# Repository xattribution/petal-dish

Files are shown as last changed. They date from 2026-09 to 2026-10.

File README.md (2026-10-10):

# PETAL — printable parabolic dish generator

PETAL designs a segmented parabolic dish that you can print on an ordinary 3D printer. Enter the dish size and your printer's build volume. It splits the dish into petals that fit your bed and shows the assembly. Then it exports a ready-to-print kit: STLs, packed print plates, an illustrated assembly PDF and a hardware list.

Everything runs in your browser, with no account, no upload and no server-side processing. Geometry builds in a background worker, so the page stays responsive while large dishes generate.

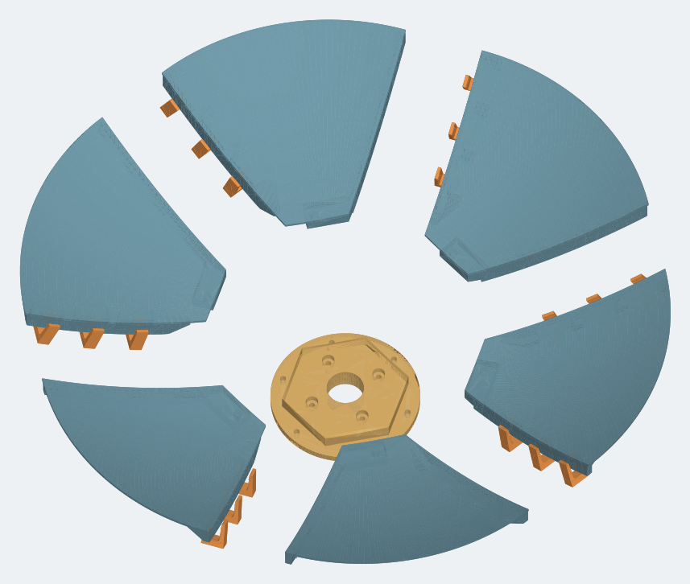
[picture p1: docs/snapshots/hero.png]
A 400 mm dish, exploded and seen from the front: six petals with snap clips around the hub


## Get started

Pick one of four ways to run it.

### 1. Open the offline app (no install)

Download **[`dist/petal-5.3-offline.html`](dist/petal-5.3-offline.html)** and open it in a browser. It is a single file with everything built in, and it works without a network connection.

### 2. Self-host on Linux (one command)

```bash
curl -fL https://raw.githubusercontent.com/xattribution/petal-dish/main/scripts/install-linux.sh -o /tmp/petal-install.sh \
  && sudo bash /tmp/petal-install.sh --port 56302 --ref main
```

Then open `http://SERVER-IP:56302`. The installer sets up a small verified web server and a boot-persistent `petal` service.

| Option | Meaning |
|---|---|
| `--port N` | Listen on port N (default 56302) |
| `--ref REF` | Install a branch, tag or full commit SHA (default `main`) |
| `--localhost` | Bind to 127.0.0.1 only, e.g. behind your own reverse proxy |

To update, re-run the same command. For status, logs and rollback, see [docs/SELF-HOSTING.md](docs/SELF-HOSTING.md).

### 3. Docker

```bash
git clone https://github.com/xattribution/petal-dish.git && cd petal-dish
docker compose up -d --build
```

Then open `http://SERVER-IP:56302`. Compose builds an nginx image from the committed `dist/` and publishes port 56302. This serves the static build only. It does not run the verified Linux installer.

To update, run this one line from anywhere. It pulls the latest build, rebuilds the image, restarts the container and removes the old image. Change `~/petal-dish` if you cloned somewhere else.

```bash
git -C ~/petal-dish pull --ff-only && docker compose -f ~/petal-dish/compose.yaml up -d --build && docker image prune -f
```

If Docker needs `sudo` on your server, use this form instead:

```bash
sudo git -C ~/petal-dish pull --ff-only && sudo docker compose -f ~/petal-dish/compose.yaml up -d --build && sudo docker image prune -f
```

Each build loads its script and styles under new URLs, so a normal reload shows the update.

### 4. Run from source

```bash
git clone https://github.com/xattribution/petal-dish.git && cd petal-dish
npm ci
npm run build                      # rebuilds dist/app.bundle.js and the offline file
python3 -m http.server 56317 -d dist  # then open http://localhost:56317
```

## Using it

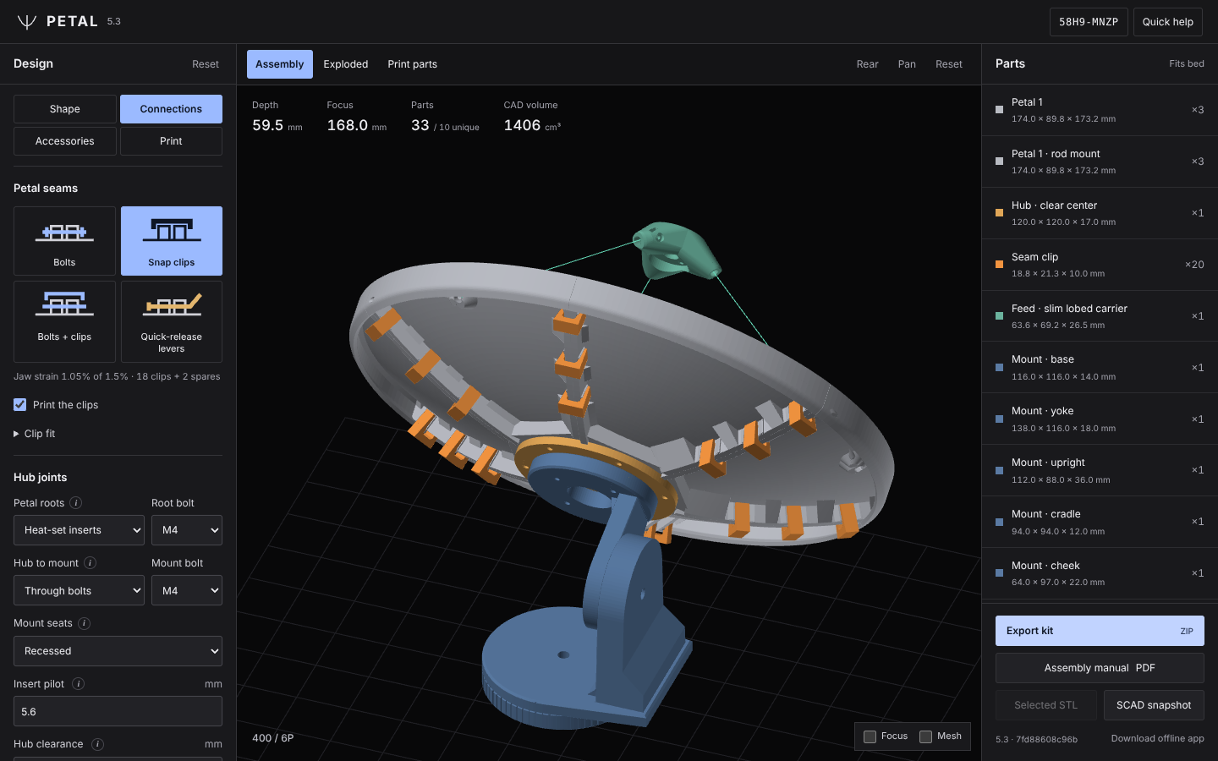
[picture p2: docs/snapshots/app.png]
PETAL in the browser: a 400 mm dish with seam clips, a prime-focus feed support and the aiming mount


The editor has four tabs.

1. **Shape:** dish diameter, focal ratio (f/D), shell thickness, an optional frequency, and the hub front.
2. **Connections:** pick the seam method from the four cards, the seam bolt size and the hub joints. **Edit individual joints** changes one seam family or one joint; **Show in model** highlights it.
3. **Accessories:** a feed support (prime focus, Cassegrain or Gregorian collector) and the aiming mount. Each has a checkbox to leave its parts off the print plates when you already have them.
4. **Print:** your printer and plate packing. PETAL chooses how many petals and rings are needed, aiming for either the largest petals or the fewest print plates.

Then **Export kit (ZIP)**: every STL in its print orientation, packed plates, `ASSEMBLY.pdf`, `HARDWARE.csv` and the fit-test parts. **Print the two seam test strips first**, then one full petal, before printing the whole dish.

The default 400 mm dish is six petals plus one hub: two unique parts, each with a flat flange down on the bed. Packed, they fit on two 220 × 220 mm beds: the petals lean the same way and nest. Drag a part to the empty slot to give it a bed of its own.

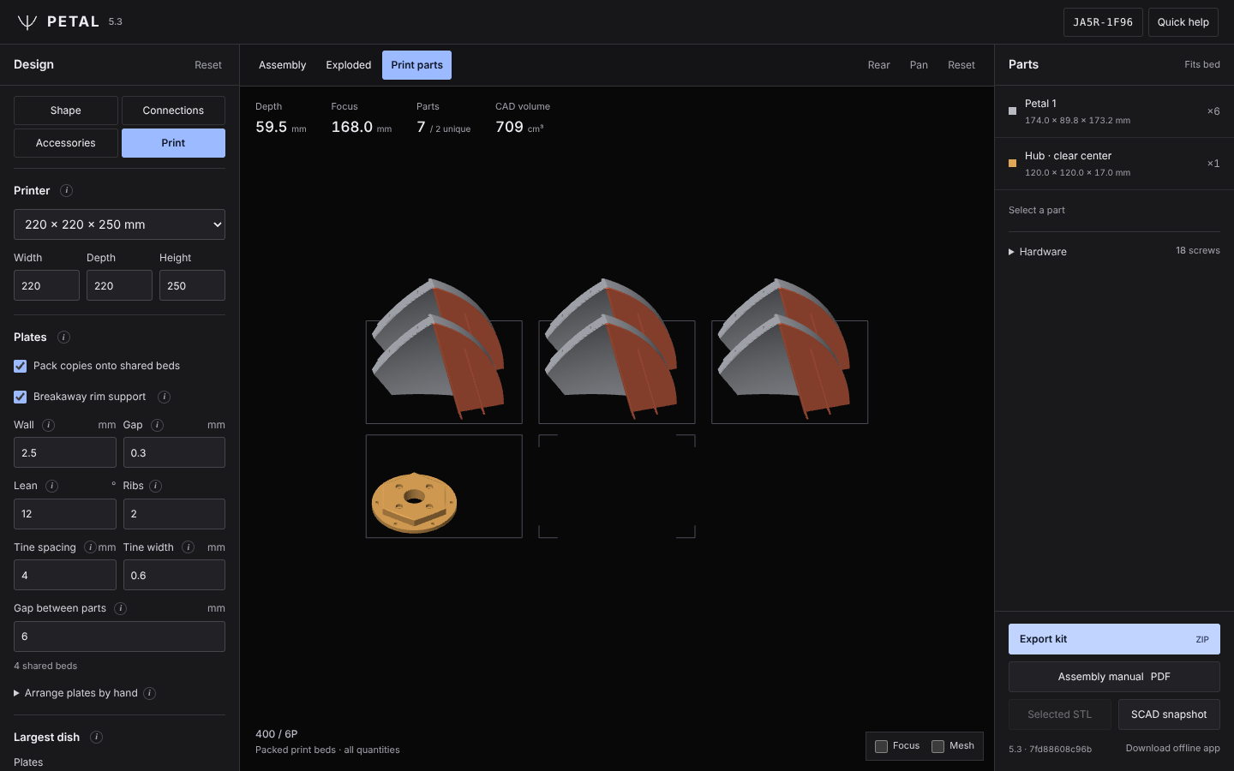
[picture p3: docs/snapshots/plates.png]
Print parts view: five petals nested on the first 220 mm bed, the sixth petal and the hub on the second, and an empty slot for a new bed


### Sharing a design

The button at the top right shows the design's **configuration ID**, such as `PX64-0211`. It covers every setting, joint choice and hand-placed plate, and it changes with any edit, so two people who see the same ID are looking at the same design.

Click it to:

- **Copy code** (for example `P1.wyFMlJFgv-EMhdpaAA`) or **Copy link**. Anyone who loads the code or opens the link gets the exact design. The address bar always holds the current link, so a reload keeps your design.
- **Load** a code, a link, a saved file, or the `parameters.json` from a kit you already exported.
- **Save** named designs in this browser, or **Save file** to keep one with a kit or move it to another device.

Every assembly PDF shows the ID on each page and the full code on the build record page, and the kit's `parameters.json` holds both. A code from another PETAL version still loads, with a note that its parts may differ.

## Options at a glance

| Choice | Options |
|---|---|
| **Seam fastening** | **M3 or M4 bolts** on flat seats (default M3) · **snap clips**, no hardware · **both** (each station takes a bolt or a clip) · **seam levers**, a screwless quick-release cam clamp ([details](docs/SEAM-LEVER.md)) |
| **Petal roots to hub** | Blind heat-set inserts, keeping the reflecting face closed (default) · through bolts, in recessed seats (default) or plain holes. M3, M4 (default) or M5 |
| **Hub to mount** | Through bolts, in recessed seats (default) or plain holes · blind inserts. Four M3, M4 (default) or M5 on a 60 mm bolt circle around a clear Ø30 mm center |
| **Hub clearance** | 0 mm (default) to 0.6 mm of extra gap at the hub's edges and root holes, so the petals line up on their seams before the root bolts clamp them to the hub. The mount holes stay put |
| **Hub front** | Flat (default): level with the petals at the hub's corners and chamfered down to them along each edge, so it prints cleanly · curved, following the dish |
| **Underside** | Smooth curved shell (default) · small flat facets |
| **Stiffening** | A band behind the rim of the outer petals, square to the dish: a frame with a 45° foot toward the hub (default), an L, a U or none, with a 6–30 mm wall and a 0–3 mm lip above the reflecting face (1 mm default). Every print layer ends in a hook instead of a free edge, and the assembled bands form one frame around the dish · optional underside ribs: a diamond grid, a center ring, or both ([details](docs/PRINTING-LARGE-PETALS.md#rim-band-and-underside-ribs)) |
| **Rim support** | A solid breakaway wall printed in front of the rim of each outer petal, joined to the rim's front edge by small tines that snap off (default on: 2.5 mm wall with its inner edge 12° from vertical and two ribs square to it, 0.3 mm gap, 0.6 mm tines at most 4 mm apart). It holds the tall rim edge still in the side print and is not part of the dish. It spreads nested petals on a plate; a larger lean uses less material ([details](docs/PRINTING-LARGE-PETALS.md#breakaway-rim-support)) |
| **Automatic sizing** | Largest petals: the fewest pieces and seams (default) · fewest print plates: may use more, smaller petals when they pack onto fewer beds |
| **Large dishes** | Staggered rings (default) · aligned rings |
| **Printer** | Presets for the Prusa CORE One L (with or without the INDX tool changer), Bambu Lab H2D and H2C, common volumes, or any custom volume. The last valid volume is remembered in the browser |
| **Print plates** | Copies share beds and keep 6 mm apart at every height (adjustable, for wider brims), so side-printed petals that lean the same way nest like spoons. In **Print parts**, drag a part onto another bed (or the empty slot after the last one): it lands in the nearest spot that fits, turning if it has to. Exact positions can also be typed in. **Largest dish** finds the biggest dish whose kit fits a number of plates on your printer, with any petal and ring count |
| **Feed support** | None · prime focus · Cassegrain secondary (experimental) · Gregorian collector: a bowl over the focus that folds the signal down to your insert, re-solved for every dish shape ([details](docs/FEED-OPTICS.md#gregorian-collector)). All on aluminum rods with generated cut lengths: four with 8, 12 or 16 petals, three with 6, or a fixed count |
| **Aiming mount** | None · printed manual alt-az mount, split into parts joined with heat-set inserts. Optional elevation arc lock. The elevation clamp goes on the right, the left (a slip then tightens it) or both sides, a U with two clamps. Base: printed with an azimuth scale, tripod leg sockets for your own legs, or none (bolt the turntable to a stand). Bolt sizes: clamps M6, M8 (default) or M10; joint screws M3–M5; stand screws M4–M6; leg cross bolts by leg size or M3–M6. Joint and stand screws are socket heads in counterbores. The clamp bolt heads, the azimuth nut and the no-base stand screws sit in pockets or counterbores (default) or on plain holes ([details](docs/SIMPLE-MOUNT.md)) |

All seam hardware stays behind the reflecting face.

| Rear: clips, hub and mount | 600 mm, two staggered rings | Exploded |
|---|---|---|
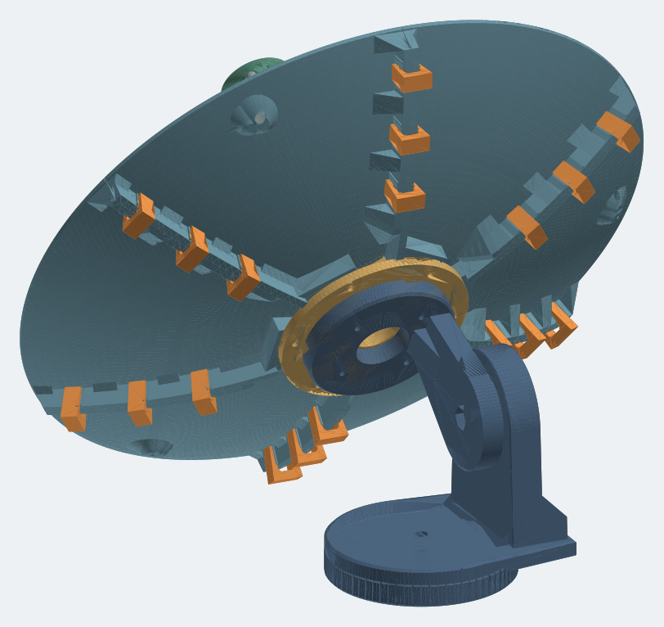
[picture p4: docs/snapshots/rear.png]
Rear view of the 400 mm dish showing seam clips, the flat hub and the aiming mount
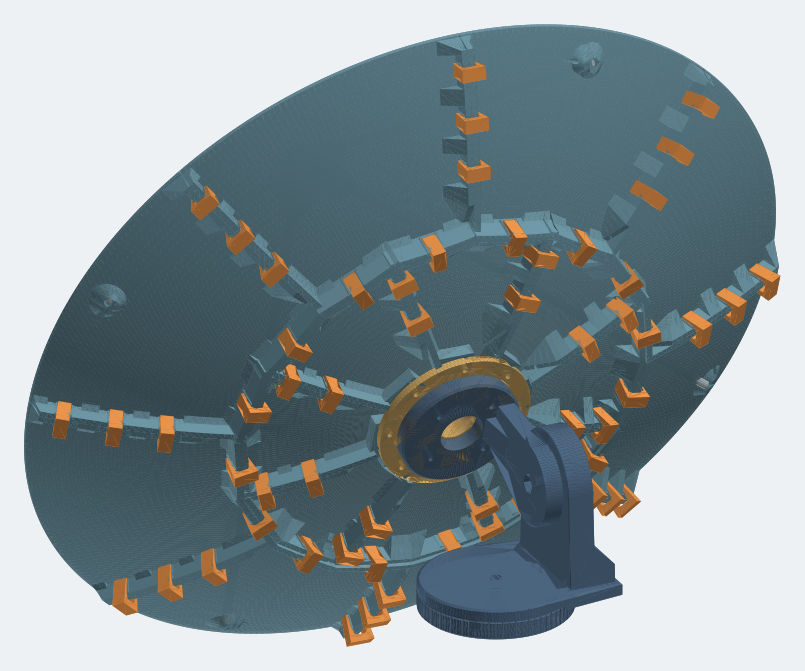
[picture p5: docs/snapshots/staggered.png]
600 mm dish with two staggered rings, mixed bolt and clip seams and four rods
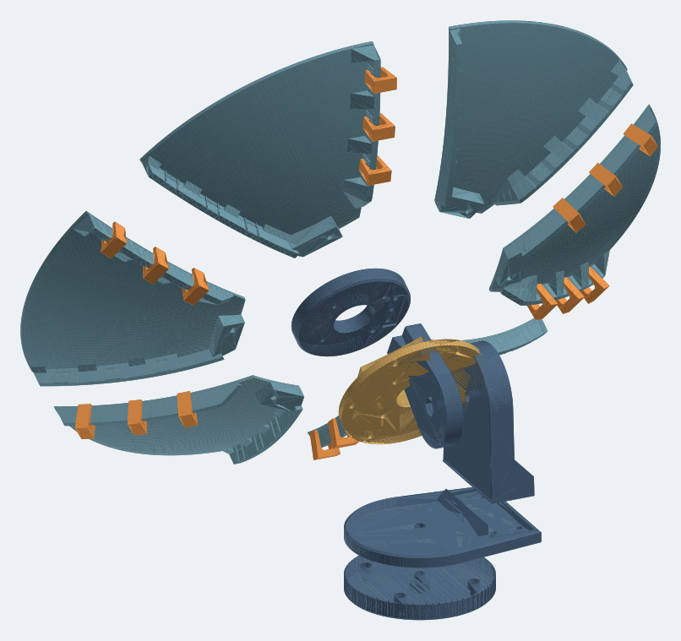
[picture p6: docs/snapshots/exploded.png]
Exploded 400 mm dish and mount
|  |  |  |

| Gregorian collector on the tripod base | Tripod leg sockets |
|---|---|
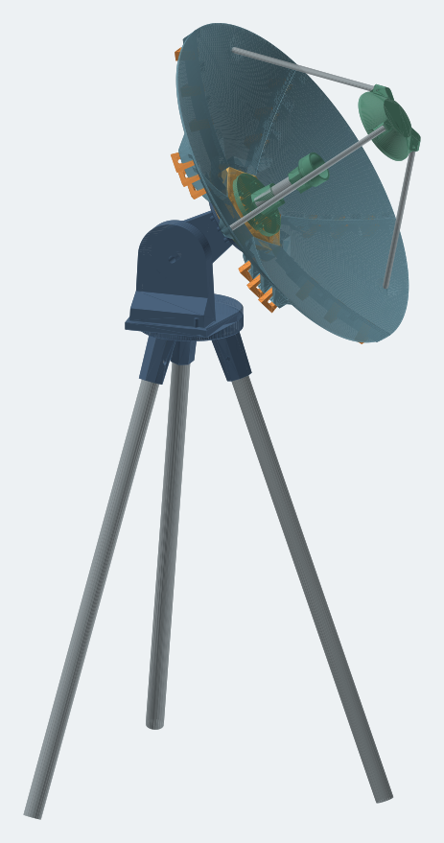
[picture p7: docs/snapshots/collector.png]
400 mm dish with the collector bowl, insert mast and cup, on three legs
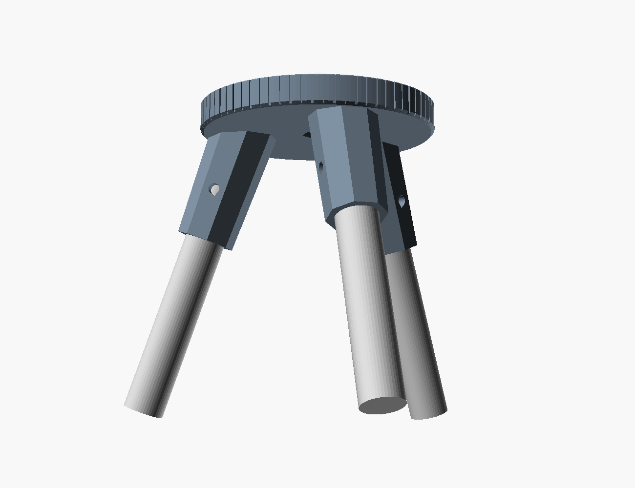
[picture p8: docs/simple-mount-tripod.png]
Tripod base from below: three tapered octagonal sockets with cross bolt holes
|  |  |

Seams take M3 or M4. Petal roots and hub mounts take M3, M4 or M5; M4 is the default interface. Kits with joint overrides include `CONNECTIONS.csv` and individually named petal variants. Help for each setting is in its **ⓘ** tooltip, and the full print and assembly instructions are in the generated PDF.

Viewport: drag to orbit, **middle drag / Shift drag** to pan, wheel to zoom toward the cursor, or use **Pan** mode. On touchscreens, use two fingers to pan and pinch. Shift + arrows pan; Home resets the camera. In **Print parts**, press a part to select it and drag it to move it to another bed.

Feed revision 7 uses a small rounded taper around each direct petal rod hole and a compact side-screw ear. The large underside pyramid, separate rim shoes, backing plates and paired mounting bolts are gone. Only the bore changes angle as dish size or focal distance changes; the exterior blends into the dish underside. The circular bearing has 45° roof shoulders and a **0.8 mm bridge** for the exported side-print orientation.

In **Accessories → Feed support**, choose **Enter diameter**, then enter your measured rod diameter in **mm or inches** (2–12.7 mm / approximately 0.079–0.5 inches). For example, 0.25 inches is exactly 6.35 mm. Both petal and carrier bores use this diameter plus the selected diametral clearance. Switching units preserves physical size. **Auto** screens 4, 5, 6, 6.35, 8, 10, 12 and 12.7 mm stock. On large dishes the rods start further in from the rim, on whichever ring holds that radius, where that keeps them under about 580 mm. No rod is longer than 1 m. Exported geometry, manifest and rod schedule use millimeters; the CSV also includes cut lengths in inches.

Petal retention uses an **M3 × 12 headless screw** and a **short M3 heat-set insert**, maximum 4 mm long, compatible with a 4.2 mm pilot. Carrier hex nuts remain unchanged. Regenerate mounting petals, carrier and rod cuts together; previous feed revisions are not interchangeable. Test one mounting petal for your rod and insert fit first. The carrier and secondary still need their own slicer support review.

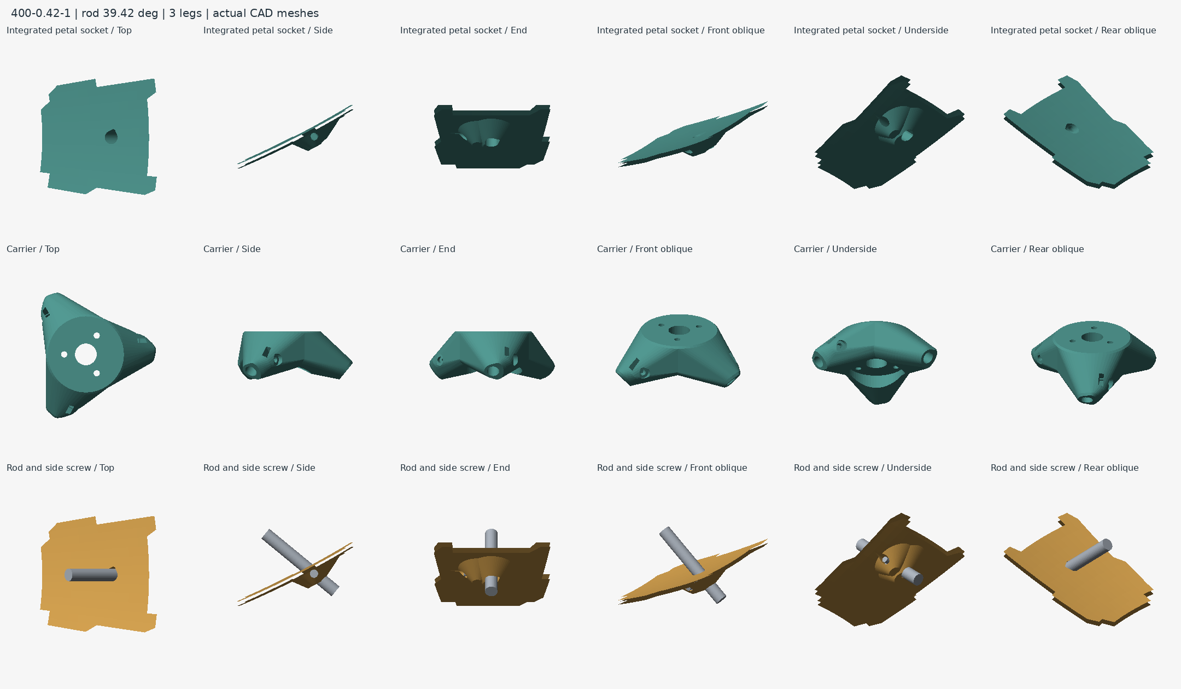
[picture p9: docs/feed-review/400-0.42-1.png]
Compact direct rod attachment, actual CAD views


## Documentation

- [ASSEMBLY / print notes](docs/DEFAULT-ASSEMBLY.md): the generated instructions for the default dish. Your kit includes a version for your exact settings.
- [Test article procedure](docs/TEST_ARTICLE.md): what to print and measure first.
- [Reflective surface](docs/REFLECTOR.md): foil tape and conductive coatings.
- [Feed optics and rod supports](docs/FEED-OPTICS.md)
- [Aiming mount](docs/SIMPLE-MOUNT.md) · [Seam lever](docs/SEAM-LEVER.md)
- [Printing large petals](docs/PRINTING-LARGE-PETALS.md): warping, settings for the CORE One L and H2D/H2C, shell thickness
- [Engineering limits](docs/ENGINEERING.md) · [Validation record](docs/VALIDATION.md)
- [Self-hosting](docs/SELF-HOSTING.md)

## Status and limits

PETAL is an **engineering prototype**. Test prints fit as designed, but a closed STL is not a load, weather or RF rating. Printed plastic needs a conductive finish and a proper RF feed before it works as an antenna. Interface revision 12 parts are not compatible with older kits, so regenerate the whole kit after changing settings. PETG is fine for indoor fit tests. Use ASA for outdoor trials, with a controlled enclosure.

## Develop

```bash
npm ci
npm test              # geometry, feed, plates, rings, integration, lever motion, connections, viewer
npm run test:ui       # builds, then drives the offline app in jsdom
npm run test:scad     # snapshot renders vs. JS geometry (needs OpenSCAD)
npm run test:pdf      # manual PDF fixtures (needs Python)
npm run test:hosting  # real Caddy check of the installer config (downloads Caddy once)
npm run build         # dist/app.bundle.js, petal-5.3-offline.html, BUILD.json
```

The app sources live in `dist/`:

- `app.js`, `workspace-ui.js`, `viewer.js`: the page, its controls and the WebGL preview
- `engine.js`: the geometry worker (build and every export); `engine-client.js` starts it, or runs it on the page if workers are unavailable
- `params.js`: defaults, limits and validation, shared by the page and the worker
- `geometry.js`: dish, flanges, hub and seam fasteners
- `pack.js`: plate packing (per-height footprints, nested stacks, drag-and-drop moves)
- `mount.js`: the aiming mount
- `feed.js`: optics and feed supports
- `exports.js`, `zip.js`: kit, guide, manifest and the deflated ZIP
- `manual.js`: the PDF

The printed accessories are OpenSCAD sources in `cad/`. After editing them, regenerate the bundled meshes:

- `python3 scripts/pack-mount.py` for the mount
- `python3 scripts/pack-lever.py` for the seam lever (needs OpenSCAD and `trimesh`)

`app.bundle.js` and the offline HTML are reproducible build outputs. `npm run docs` regenerates the default guides in `docs/`, and `node scripts/render-system.mjs && python3 scripts/render-system.py && node scripts/render-app.mjs` regenerates the README images. Earlier designs remain in git history.

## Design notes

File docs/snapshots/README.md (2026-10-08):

# PETAL 5.3 images

Every image is generated from the real app or its real triangles, not concept art.

- `hero.png`: the README header, a 400 mm dish with snap clips, exploded and seen from the front.
- `app.png`: the app in a browser, 400 mm dish with snap clips, a three-rod prime-focus support and the aiming mount, Connections tab open. `node scripts/render-app.mjs` (needs Playwright).
- `assembly.png`: the same dish from the front at 30° elevation.
- `rear.png`: the same assembly from behind.
- `staggered.png`: 600 mm dish, two staggered rings, bolt-or-clip seams, four rods, mount at 20° elevation; the rear view shows the three-panel ring joints.
- `exploded.png`: the 400 mm dish and mount with separated parts. Separation is illustrative, not an assembly path.
- `clip.png`: one clip in its exported broad-side print orientation.
- `collector.png`: 400 mm dish with the Gregorian collector (bowl, mast and insert cup) on the tripod base, with legs at the computed minimum length, 35° elevation.
- `plates.png`: the default dish in the Print parts view: five nested petals on the first 220 mm bed, the sixth petal and the hub on the second, and the empty slot for a new bed. Rendered by `node scripts/render-app.mjs`.

Orange parts are installed seam clips, blue is the mount, gold is the hub and green parts hold the aluminum rods. Spare clips, metal fasteners, the RF feed and your stand are omitted.

Regenerate the renders with `node scripts/render-system.mjs && python3 scripts/render-system.py` (NumPy and Matplotlib; name cases to render only those). Numerical geometry is not a load rating or a print qualification.

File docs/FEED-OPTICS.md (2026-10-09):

# Compact feed support and frequency sizing — PETAL 5.3 · accessory revision 7

Actual integrated petal geometry

## Direct petal attachment

The rod passes directly through an angled hole in a selected outer petal. A compact underside saddle is continuous with the shell. An M3 × 12 headless side screw and short M3 heat-set insert retain the rod. There is no separate rim shoe, rear backer, pair of mounting bolts or rim-bolt washer stack.

Small circular tapers blend into the underside. The rod bore has 45° roof shoulders and a 0.8 mm bridge in the actual side-print direction; the side insert pilot is circular. These new petal sockets are designed for support-free printing in the exported orientation. The unchanged carrier and secondary still need their own slicer support review.

The rod count follows the petal count by default: four rods with 8, 12 or 16 petals and three with 6. Each rod lands on its own petal, so 10 and 14 petals cannot space rods evenly, and automatic segmentation skips them while a feed is on. You can still fix the count at 3 or 4; the petal count then has to divide by it. Regenerate mounting petals, carrier and rod cuts together. Use the generated PDF and hardware CSV: the petal uses **short M3 heat-set inserts**, maximum 4 mm long, compatible with a 4.2 mm pilot, while the carrier uses **M3 hex nuts**.

The lower rod datum is now under the reflector. Its crossing of the front face is solved for the chosen dish curve; cuts and angles are recalculated. The 18 mm front-face insertion mark includes any rear protrusion through the open bore, rather than promising 18 mm continuous plastic contact. The carrier keeps its 16–19 mm engagement range. No strength rating follows from geometry checks alone.

## Frequency is an input, not a complete antenna design

For frequency ν in GHz, wavelength in mm is `λ = 299.792458 / ν`. The primary focal length is `f = D × f/D`. **Changing frequency alone does not move the focus of an unchanged parabola.**

| Generator control | What changes |
| --- | --- |
| Frequency + automatic secondary sizing | Target secondary diameter, solved hyperbola position, rod angles/cuts and center standoff |
| Frequency + automatic bowl sizing (collector) | Bowl diameter in wavelengths when that exceeds the smallest bowl that shades the insert; ellipse, F2, rods and mast follow |
| Actual feed phase offset in mm | Prime-focus puck position and rod angles/cuts |
| Known feed phase offset in wavelengths | Converts the supplied feed-specific offset using frequency, then recalculates puck and rods |
| Automatic solid-rod diameter | Chooses 4, 5, 6, 6.35, 8, 10, 12 or 12.7 mm from span, entered payload and deflection budget |
| Manual solid-rod diameter | Uses a user-entered 2–12.7 mm diameter, in mm or inches; warns if over the screening deflection budget |
| Frequency in either optical mode | Reports wavelength and surface-error screening budget |

Changing frequency, phase offset or rod diameter can change the fixed socket angles and bore sizes. Regenerate the mount petals, carrier and rod cut list together; changing the metal rods alone is not always sufficient.

The phase offset in wavelengths is for a **known, scalable feed design**. It is not a universal horn/patch/helix phase-center model. Entering frequency does not synthesize an RF feed, select polarization or establish bandwidth. Default zero offset means the actual feed datum has not been supplied.

## Prime focus and secondary optics

A prime-focus antenna places the actual feed's phase center at the parabola focus, facing the main dish. The puck lower-face datum is `f − phase offset`, with positive offset along +z away from the main reflector. All coordinates refer to the extrapolated parabola vertex, not the rim or rear hub.

A Cassegrain uses a **convex hyperbolic secondary**, with one hyperbola focus at the primary focus and the other at the rear feed's phase center. An arbitrary flat disc or small parabola at the main focus is not interchangeable with this system.

For primary focus f, rear focus g<0 and secondary vertex v:

- `center = (f+g)/2`, `c = (f−g)/2`, `a = v−center`, `b² = c²−a²`.
- Reflecting surface: `z(r) = center + a √(1+r²/b²)`.
- Intersect the primary rim-to-focus ray with this surface; extend its radius by 4% as a geometric margin.

Automatic sizing targets the entered diameter in wavelengths (default **4λ**), subject to a **56 mm mechanical minimum** and a **25% primary-diameter ceiling**. Bisection solves the secondary vertex for that diameter. The program then recomputes all support coordinates. It does not optimize taper, blockage or sidelobes. The 25% ceiling is a prototype packaging limit; a smaller secondary-to-primary ratio can be preferable electromagnetically.

For a 400 mm dish, a 4λ secondary is approximately 500 mm across at 2.4 GHz: automatic mode rejects that combination. Prime focus is the practical starting point at that scale. At 15 GHz the target is about 80 mm; at 20 GHz it is about 60 mm. These examples still need appropriate feed design and electromagnetic analysis. Below five wavelengths the UI specifically flags diffraction; this is not an absolute RF pass/fail threshold.

The returned ray bundle must clear the 30 mm hub with 1.5 mm radial margin. This does not certify physical clearance for a rear horn, connector or cable. A small central standoff is generated in 5 mm increments so rods clear the secondary edge. It is part of the single puck, not a separate arm structure.

The secondary is a 3 mm shell with a central boss and one blind short-M4-insert pocket. No screw breaks the reflecting face. Use the generated hardware schedule: puck/standoff height changes the screw length. A 4 mm total metal washer/spacer stack leaves nominally 5 mm screw entry. Verify actual insert length and tip clearance before tightening.

## Gregorian collector

The collector layout uses the dish to gather rather than to radiate. A concave bowl hangs just beyond the prime focus, facing the dish. Rays from the dish converge on F1, cross it, reflect off the bowl and come back down to a second focus F2 below it. The receiving insert sits at F2, looking up into the bowl, on a short tube mast from the hub. The rods socket directly into fins on the bowl, so there is no separate carrier or adapter.

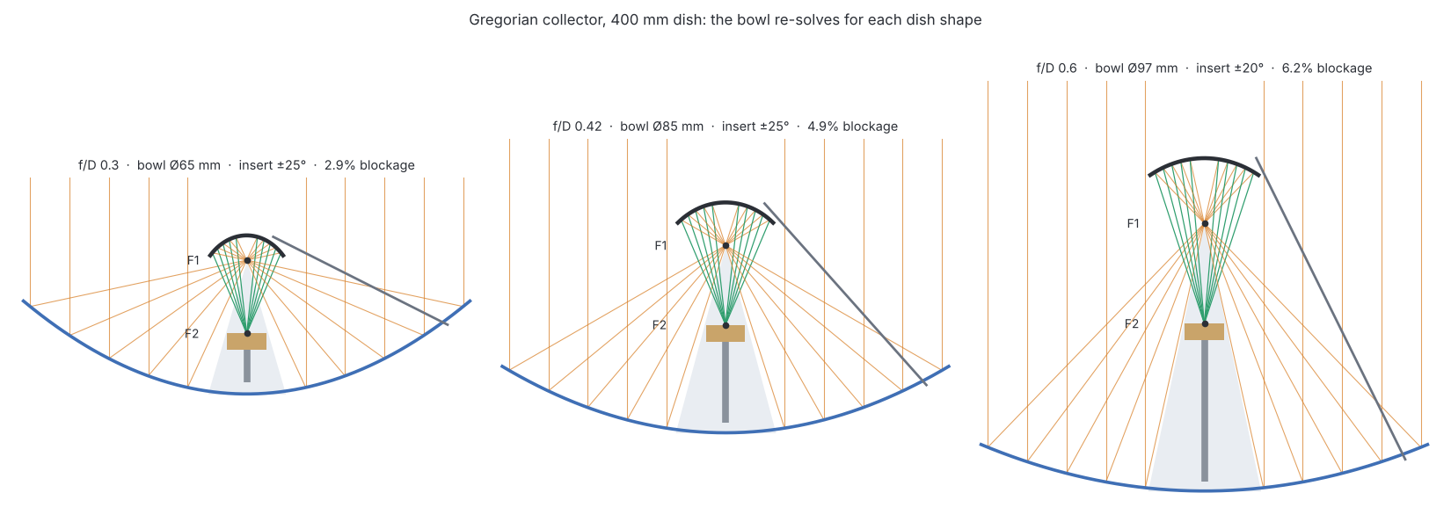
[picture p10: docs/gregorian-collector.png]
Gregorian collector cross-sections for f/D 0.3, 0.42 and 0.6


**Why an ellipsoid.** A reflector that sends every ray through one point to a second point is an ellipsoid with those two points as foci. With F1 at the dish focus and F2 at the insert's phase center, every dish ray folds to the insert. This is the Gregorian dual reflector; the Cassegrain mode uses a convex hyperboloid instead and puts the feed behind the dish. About F1, with ψ measured from the dish axis (ψ = 0 at the bowl vertex):

`t(ψ) = b² / (a + c·cos ψ)`, with `c = |F1F2| / 2`, `a = (|PF1| + |PF2|) / 2` at any surface point P, and `b² = a² − c²`.

**How it follows the dish.** Every build re-solves the bowl from D and f/D:

- Rim angle `ψ0 = 2·atan(D / 4f)`. The bowl edge sits at `ψ0 + 3°`, so it catches every dish ray with a little spill margin.
- The insert half-angle θ is the angle at F2 to the bowl edge. For a bowl radius `r`, the focus spacing is `|F1F2| = r·(cot θ − cot ψE)`.
- Magnification `M = (1 + e) / (1 − e) = tan(ψE / 2) / tan(θ / 2)`, with `e = c / a`. The insert sees an equivalent dish of `f/D × M`, so a deep dish can be fed by an ordinary moderate-beam insert.

A deeper dish (larger ψ0) or a narrower insert beam spreads F1 and F2 apart. A wider insert beam pulls F2 up toward the bowl; a larger insert needs a larger bowl.

**Sizing rule: hide the insert in the bowl's shadow.** Dish rays inside the bowl's radius never reach the dish, so a cone below F1, of half-angle `2·atan((r + lip) / 2f)`, carries no energy. The insert cup and mast go inside that cone, so the bowl is the only blocking object. This is the minimum-blockage condition for dual reflectors (Wade: the feed's blockage should not exceed the subreflector's). Auto sizing bisects for the smallest bowl that shades the insert cup with 1 mm to spare, or the entered number of wavelengths when a frequency is set, whichever is larger. Manual sizing takes your diameter and rejects one that cannot hide the insert.

**RF guidance.** These are ray-optics rules; diffraction is not modeled.

| Check | Rule used | What the app does |
| --- | --- | --- |
| Bowl size | Above ~10 λ works well; 5–10 λ loses some gain to diffraction; below ~5 λ prime focus usually wins | Warns below 10 λ and below 5 λ |
| Blockage | Area fraction `((r + lip) / R)²` | Reports it; warns above 5%; refuses bowls over 30% of D |
| Insert far field | Bowl at least `2d² / λ` from the insert | Warns when the bowl is closer |
| Insert beam | −10 dB edge near ±θ | θ is the input; the dish rim lands slightly inside it |

At 10 GHz a 400 mm, f/D 0.42 dish gets a 4 λ (120 mm) bowl by default, which the app flags. At 24 GHz the same 4 λ is a 50 mm target, so the shadow rule sets the size (about 85 mm, 6.8 λ). Larger dishes and higher frequencies are where the collector earns its keep.

**Mechanics.** The reflecting face is the exact ellipsoid; a ray cast against the printed mesh finds it within 0.01 mm everywhere inside the rim. The bowl prints on its flat top with the reflecting face up and no supports: the back follows the face at 3 mm or a 45° cone, whichever is steeper. Where each rod goes in, the wall thickens between the flat top and the rim, so nothing hangs below the rim or into the signal path. The rod runs just above the back cone, enters at the rim and stops inside the thickened wall, with 1.5 mm of wall over the reflecting face and 1 mm under the top. Each seat is the rod's collar swept at 45° up to the flat top, so it stands on the bed in print. One cross bolt (M3 for rods 6 mm and up, M2 below) passes through flat side faces in open air and is match-drilled through the rod. The bowl end takes 1.6 rod diameters of engagement (at least 8–10 mm), because the bolt pins it. The mast foot bolts to the flat hub front on the four hub-to-mount through bolts; the cup and foot each take an M3 set screw into a short heat-set insert. The cable runs inside the mast and out through the hub center. Very deep dishes leave no room for a tube, and the cup then stands on a printed pedestal.

## Rod cuts, tolerances and retention

**Where the rods start.** The lower datum is 20 mm inside the rim when that rod is at most 580 mm long. On a larger dish the datum moves in toward the hub, in 5 mm steps, to the outermost radius whose rod is 580 mm or shorter and no steeper than 62° (the steepest bore the petal sockets have been checked for), and the sockets go on whichever ring holds that radius (with room for the socket and 8 mm to each ring seam). When no datum meets both (a long focus, a Cassegrain carrier or a collector bowl on a large dish, where the rise alone is most of the rod), the datum stays at the rim: moving in would barely shorten the rod and would narrow the support. No rod may exceed 1 m. On a 1200 mm dish at f/D 0.42 on a 300 mm bed, that puts the prime-focus datum at r 370 mm on ring 2 of 3 (580 mm rods); the Cassegrain and collector rods start at the rim (679 and 659 mm). A 1200 mm dish at f/D 0.8 needs rods over 1 m and is refused.

The underside petal datum and carrier datum determine span S. The lower front-face crossing is solved from the parabola; the upper entrance remains 22 mm from its datum:

`rod cut = S − lower entrance − upper entrance + 36 mm`.

The entrance distances, cut and leg positions are included in `RODS.csv`. The petal hole is through, with no floor. Only the carrier has a bore floor, 2 mm from its datum.

At the carrier, keep 16–19 mm engagement and at least 1 mm clearance above its bore floor. Align the lower 18 mm mark with the front-face center crossing; the rod may protrude under the petal. Deburr, mark insertion depths and trial-fit before final trimming. The rods are not printed; use smooth **solid** aluminum stock. Tubing requires a different clamp and section calculation, because a radial screw can crush it. The purchased rod diameter and generated socket clearance must match.

The radial M3×10 screw threads through a real M3 nut in a **side-loading captured pocket**. The nut has a retaining roof in the screw-load direction; it is not simply pressed into an outward-open recess. No printed threads. Test screw-tip contact, slip and repeatability with the actual rod and filament. Mark the rod for visual slip detection. Do not interpret screw engagement as a validated clamp-force rating.

Align the puck with an independent center/height jig. Tighten incrementally without using any rod to pull a warped petal into shape. Recheck alignment at different dish elevations and after warm soaking. The puck has three/four M3 adapter holes on a 24 mm bolt circle, midway between rods, with a 12 mm prime-focus cable opening. This is PETAL's interface, not a standard feed flange; a feed-specific adapter remains necessary.

## Mechanical and RF screening

Automatic stock selection uses `δ = FL³/(3EI)`, `I = πd⁴/64`, E=69 GPa, and the entire entered supported payload acting transversely on one exposed rod span. This is a deliberately conservative **single-cantilever screen**, not an analysis of the assembled truss. The limit is `min(1 mm, λ/50)`; unknown frequency uses 1 mm. Include the feed/secondary, puck, adapter, fasteners and cable reaction in the entered load. Wind, joints, resonance, buckling, temperature and polymer creep are not modeled. No supported mass or wind rating is assigned.

The displayed surface-RMS budget is λ/40. In the Ruze random-error approximation, that corresponds to roughly 0.43 dB surface-error loss alone; systematic petal distortion, gaps, blockage and feed losses are additional effects. This budget is not a measurement of the printed surface or a complete focus-position tolerance. Rod-screening deflection is likewise not a prediction of RF loss.

Print mounting petals in their exported side-print orientation; the new socket roofs and underside ramps are aligned for support-free printing. Print the carrier top-face down; its existing circular bores and hex-nut pockets may need localized supports. Print the secondary boss-down with support under the surrounding rear shell. Start with four perimeters and locally solid fitting walls; inspect the actual sliced wall paths. PETG is useful for indoor fit tests; ASA can be appropriate for outdoor UV exposure with an enclosed printer. Qualify creep and alignment at the actual service temperature.

Cover the dish-facing reflector surfaces with continuous, well-bonded aluminum/copper foil or a verified conductive coating. Ordinary metallic-looking paint is not an RF conductivity specification. Foil wrinkles, seams, adhesive thickness and assembly steps all consume the surface-error budget. Mask mounting datums and bores; fit first and coat afterward. Verify electrical continuity, then measure RF performance with stable feed alignment.

## Sources and verification scope

- [Paul Wade, W1GHZ: Multiple Reflector Dish Antennas](https://www.w1ghz.org/antbook/conf/Multiple_reflector_antennas.pdf): Gregorian ellipse foci, magnification and eccentricity, subreflector size and feed blockage.
- [T. L. Wilson: Techniques of Radio Astronomy](https://arxiv.org/abs/1111.1183): dual-reflector systems, aperture blockage and efficiency.
- [MathWorks: Cassegrain geometry and electromagnetic analysis](https://www.mathworks.com/help/antenna/ug/design-and-analyze-cassegrain-antenna.html): separate horn design; example 4λ secondary; hybrid solvers and diffraction considerations.
- [NRAO: surface errors and the Ruze approximation](https://naic.nrao.edu/arecibo/phil/sysperf/misc/surfaceErrorsRuze.html).
- [RF HAMDESIGN: three-leg accessory examples](https://www.rfhamdesign.com/products/parabolicdishkit/accessories/index.php).
- [Prusa material guide](https://help.prusa3d.com/filament-material-guide): PETG and ASA printing/material considerations.
- [Manifold](https://github.com/elalish/manifold): Boolean geometry kernel used by the online and offline app; see `THIRD-PARTY-NOTICES.md`.

Automated checks cover closed meshes, winding, quantities, print bounds, generated cuts and datums, wavelength sizing, fixed primary focus, rod screening, exports, independent hyperbola reflection/path checks and ellipse ray traces to F2 for several dish shapes. Sampled mesh interference checks and OpenSCAD comparisons complement them. These are geometry/software checks, not a slicer, physical load test, electromagnetic simulation or measured antenna qualification.

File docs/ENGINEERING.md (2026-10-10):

# Integral-flange design decisions

PETAL 5.3 is a test-article candidate, not a qualified structure.

## Load path and fit

The shell has continuous edge walls extending 14 mm below its underside. Bolt-only walls are 3 mm with 5 mm fastening stations; clip-compatible walls are uniformly 5 mm. The upper flange has a full-depth 45° gusset and a ramped inner end. Root bosses extend to the bed-side edge. Cross-flanges join the side flanges at their ends. M3 screws clamp sideways between flat seats with loose nuts; there are no captured seam nuts or alignment keys. Spaced stations resist rotation; longer seams add stations. Clips provide removable retention, but do not provide the same preload as bolts.

Mating faces are flat, with no keys; the bolts or clips align the petals. Radial insertion between fixed neighbors is sampled by computer collision checks; accumulated shrinkage, layer ridges and thermal distortion remain physical risks. Do not force a ring closed with screws.

Side flanges stop outside the Ø120 hub envelope. Petal root bosses span the whole hub end, seam to seam, and bear on the hub's flat rear support ring. By default each root takes a short blind M4 insert and an M4 × 12 from the hub rear, so the reflecting face stays closed. A through bolt is an option: its head sits in a recessed flat seat in the front, and the nut sits on the hub's rear. Roots and the four hub-to-mount bolts take M3, M4 or M5; holes, seats, insert pilots and screw lengths follow the size. Through-bolt seats are recessed by default; plain holes keep only a flat spot face where the surface slopes, so the heads and washers bear flat. An optional hub clearance (up to 0.6 mm) moves the hub's edges in and enlarges its root holes by the same amount, so the seams, not the hub, set the petals' positions; the petals still bear on the hub's flat rear ring, which sets the surface height. The one-piece hub includes the center surface and eliminates the front cap. The flat front sits level with the petals at the hub's corners, where the inner petal edge is highest, and chamfers down to meet each petal along its edge, so there is no step at the joint. It stands above the parabola by up to zAt(45 / cos(π/n)) − zAt(15), about 3.7 mm on the default dish. The curved front follows the parabola. The flat front's local surface departure is reported against the chosen frequency in the UI and in the exported instructions. Feed shadowing is not guaranteed to hide this error. Root fasteners are not an independently qualified overturning-moment connection. Mount and feed loads still need creep and temperature tests.

## Print orientation

Petals stand on the bed-side radial flange. The primary curved underside becomes side-facing instead of plate-facing. The chosen orientation provides a long contact strip but makes a tall thin wall: brim adhesion, vibration and layer-direction bending remain concerns. Upper-edge details, root-boss transitions and bore roofs need slicer inspection. A 45° gusset in assembly coordinates is not by itself proof of a support-free print in every orientation.

Optional underside facets use a square lattice of tangent planes, never intruding into the nominal shell. Maximum added vertical material is pitch²/(8f), about 0.30 mm for 20 mm pitch and f=168 mm. Crease lines are inserted into the mesh. The reflective front is still a tessellated parabola; coarse triangle spacing can consume a high-frequency surface-error budget.

Minimum supported dish diameter is 260 mm with the present hub and flange hardware. The planner may reject other dimension/bed combinations. This is preferable to exporting overlapping or inaccessible hardware. Segmentation uses straight chord boundaries, maintaining flat printable cross-flanges. **Largest petals** takes the fewest sectors and rings that fit the bed. **Fewest print plates** ranks larger counts by a packed-plate estimate, then packs the real petals and switches only when they need strictly fewer plates. Both are fit heuristics, not a globally optimal packing or stiffness calculation.

## Plate packing

Each copy stands on the bed in its print orientation. Its space on a plate is its outline in every 4 mm height band, on a grid of 1 mm for beds up to 320 mm (1.5 mm up to 480 mm, 3 mm beyond), grown by half the 6 mm gap. Two parts clash only where their outlines meet in the same band. Side-printed petals lean, so copies that lean the same way can stand much closer than their bounding boxes: identical petals are packed as nested stacks, everything else as rectangles. The default 400 mm dish fits on two 220 mm beds instead of three. Moving a part by drag and drop uses the same outlines: it lands at the free spot nearest the drop point, trying its own rotation first, then 180°, 90° and the other 15° steps; if no spot is free the target plate is repacked with it, as long as everything still fits on that plate.

## Numerical checks and remaining gates

Regression tests exercise oriented closed meshes, connected solids, actual print bounds, packing separation (every pair of parts on a plate sliced every 1 mm and kept 6 mm apart), hub/root clearances, flat seam seats with washer and nut clearance, root and mount through bores and seats, insert-pilot roofs, sampled radial seam insertion, inter-segment mating, feed geometry and independent secondary reflection/path calculations. Binary STL reload and OpenSCAD comparison independently check exports. Offline DOM tests exercise the embedded kernel, options, errors and instructions; they do not qualify WebGL rendering.

Manifold solid operations replace the earlier BSP Boolean code. Each petal and the hub are built in their own scope, so their intermediate WASM solids are freed before the next part starts. Mesh output keeps the kernel's vertices and welds only exact duplicates. The kernel works in double precision, so two surfaces a few micrometers apart can share a point once written as Float32; welding them would pinch the surface, so those vertices move 0.2 µm apart into the solid instead. Collinear triangles are then repaired before STL export. These numerical checks cannot establish layer adhesion or dimensional accuracy.

Before a full dish: two seam strips, one full petal, then a root/hub fit. Measure profile and seam steps before and after tightening, multiple assembly cycles, several elevations and warm settling. Check flange-root cracking, screw bearing on the flat seats, seat flatness on the upper flange and feed-rod slip. RF gain, wind, service temperature and outdoor life remain unmeasured. Do not interpret a part-count reduction as proof of greater strength.

## Integrated aiming mount and clips

The mount's blank parts (no holes) are bundled from `cad/STL/blank` by `scripts/pack-mount.py`, and the app cuts the holes, counterbores and pockets for the selected sizes; regenerate that asset after changing mount CAD. Shared scene transforms drive the viewer, PDF and SCAD assembly. The generator checks mount/dish interference at the selected pose and reports below-base clearance, including the elevation-range envelope. This does not certify the continuous collision path, hardware, cables or a user stand.

Clip jaws print in the layer plane on their broad side. The 0.3 mm default detent reduces estimated flex strain; generation rejects settings above the user-entered strain budget. Material selection is an explicit record, not an automatically qualified allowable strain. Test unfilled materials separately from reinforced rigid mount parts. Installed clips and spare print quantities are distinct.

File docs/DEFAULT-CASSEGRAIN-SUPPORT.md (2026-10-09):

# PETAL compact rod support · cassegrain

Accessory revision 7: rods fasten directly into the underside of the selected petals, 20 mm inside the rim. There are no rim shoes, backing plates or paired mounting bolts. Regenerate the mount petals, carrier and rod cuts as a matching kit; earlier rods and petals do not interchange. Seam/hub interface remains revision 12. Changing rod count may change segmentation.

## Rods and attachment

3 × Ø6.35 mm smooth SOLID aluminum rods; nominal cut 224.95 mm each. The petal has an angled through-hole and a small continuous underside saddle, chamfered into the shell. A side M3×12 headless set screw bears on the rod through a short M3 heat-set insert (maximum 4 mm long, compatible with the 4.2 mm pilot). The carrier retains its hex nuts. No printed threads or extra petal mounting bolts.

Rod elevation is 41.42°. The lower face crossing is solved from the dish curvature, not a fixed shoe height. Cut = datum span − lower face crossing − upper entrance + 36 mm. Mark 18 mm from each rod end. At the petal, align the mark with the center of the front opening; the through-hole has no floor and the rear end may protrude. This insertion mark is not a claim of 18 mm continuous plastic bearing. At the carrier, retain 16–19 mm engagement without bottoming the rod. RODS.csv gives the actual angles, positions and cuts. Trial-fit long stock before final trimming.

## Printing and assembly

The integrated saddle is designed for the petal's existing side-print orientation. Its compact circular tapers blend into the underside. The rod bore has 45° roof shoulders and a 0.8 mm bridge aligned to print-up. The side screw and insert pilot are circular, nearly vertical in the print orientation. Keep this exported orientation. Nominal diametral rod clearance is 0.35 mm; print one mount petal and verify fit first. The circular lower arc locates the rod; the short roof relief clears the full specified diameter.

Heat-set the short M3 insert from the side, recessed 0.5 mm; then insert the rod through the petal and fit the side screw. Keep the screw loose while aligning the carrier with a height/centering jig. Fit the fourth rod last without preload. Tighten progressively and mark the rods to reveal slip. Petal inserts and carrier hex nuts are distinct items in FEED-HARDWARE.csv.

The existing carrier prints top-face down and still needs slicer review/localized support for circular bores and hex-nut roofs. The new petal socket's support-free geometry does not certify the carrier or secondary as support-free. PCTG and ASA still require a fit/slip/temperature test of the printed joint; resin data alone does not rate the assembled part. Use locally solid socket walls and a suitable material profile. Avoid hollow tubing with point screws unless separately engineered for crushing and stiffness.

The carrier has 3 M3 adapter holes on 24 mm BCD and a central M4 clearance hole. A feed-specific adapter and its hardware remain separate. Strain-relieve the cable along a rod. Measure height/centering/tilt before and after tightening and warm soaking.

## Frequency and optical meaning

Frequency is unknown; enter it to enable wavelength-based dimensions and accuracy guidance.

Frequency alone does not move the focus of a fixed parabola. Prime focus remains f = D × f/D = 168.000 mm. A phase-center offset can be entered in mm or wavelengths ONLY when supported by the chosen feed design; scaling a generic unknown feed is not valid. The puck lower-face datum is z=177.760 mm; phase-center offset is 0.000 mm along +z.

The secondary is a convex hyperboloid toward the main dish: vertex z=137.760 mm, diameter 80.336 mm, rear focus z=-20.000 mm. Automatic mode targets the entered secondary wavelength count (minimum 56 mm mechanical diameter), solves its position and then recalculates rod lengths and angles. Above 25% dish diameter it rejects the combination; choose prime focus or a larger dish. These are engineering screening limits, not optimized RF dimensions. The 3 mm reflective shell has a central 10 mm boss with one blind Ø5.6×7 mm insert pocket. Install a short M4 insert at least 0.5 mm recessed, maximum 6 mm long; use M4×55 with a 4 mm metal washer/spacer stack through the 46 mm puck/stem stack. Verify actual engagement and leave the reflective face intact. Secondary prints with its boss down; support the surrounding back shell in the slicer. The rear RF feed, phase center, polarization and illumination must be designed separately.

Auto rod sizing screens 4, 5, 6, 6.35, 8, 10, 12 and 12.7 mm SOLID aluminum using E=69 GPa and a deliberately conservative single cantilever with the entire entered 100 g payload applied transversely over the exposed span: δ=FL³/(3EI). Selected-rod result 0.400 mm. Include feed/secondary, puck, adapter and cable loads in the payload input; wind, joint compliance, resonance and creep are excluded. This is not an allowable-load calculation or an RF guarantee. Manual diameter overrides retain an over-budget warning.

- Prototype: no wind, payload or RF performance rating. Small radial screws require physical slip and warm-creep tests.
- Frequency unspecified: wavelength-dependent dimensions and RF tolerances are unavailable.
- Hyperbolic ray geometry is not electromagnetic validation. A frequency-specific rear feed remains required.

Coat the dish-facing secondary surface with continuous bonded aluminum/copper foil or a verified conductive coating; ordinary metallic paint is not sufficient evidence of RF conductivity. Keep datums, bores and the boss back clean. Surface seams/wrinkles count toward the RF error budget. Test one assembled leg for slip and creep, then the complete assembly at several elevations before committing to a full outdoor installation.

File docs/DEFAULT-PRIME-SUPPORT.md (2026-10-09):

# PETAL compact rod support · prime-focus

Accessory revision 7: rods fasten directly into the underside of the selected petals, 20 mm inside the rim. There are no rim shoes, backing plates or paired mounting bolts. Regenerate the mount petals, carrier and rod cuts as a matching kit; earlier rods and petals do not interchange. Seam/hub interface remains revision 12. Changing rod count may change segmentation.

## Rods and attachment

3 × Ø6.35 mm smooth SOLID aluminum rods; nominal cut 218.55 mm each. The petal has an angled through-hole and a small continuous underside saddle, chamfered into the shell. A side M3×12 headless set screw bears on the rod through a short M3 heat-set insert (maximum 4 mm long, compatible with the 4.2 mm pilot). The carrier retains its hex nuts. No printed threads or extra petal mounting bolts.

Rod elevation is 39.42°. The lower face crossing is solved from the dish curvature, not a fixed shoe height. Cut = datum span − lower face crossing − upper entrance + 36 mm. Mark 18 mm from each rod end. At the petal, align the mark with the center of the front opening; the through-hole has no floor and the rear end may protrude. This insertion mark is not a claim of 18 mm continuous plastic bearing. At the carrier, retain 16–19 mm engagement without bottoming the rod. RODS.csv gives the actual angles, positions and cuts. Trial-fit long stock before final trimming.

## Printing and assembly

The integrated saddle is designed for the petal's existing side-print orientation. Its compact circular tapers blend into the underside. The rod bore has 45° roof shoulders and a 0.8 mm bridge aligned to print-up. The side screw and insert pilot are circular, nearly vertical in the print orientation. Keep this exported orientation. Nominal diametral rod clearance is 0.35 mm; print one mount petal and verify fit first. The circular lower arc locates the rod; the short roof relief clears the full specified diameter.

Heat-set the short M3 insert from the side, recessed 0.5 mm; then insert the rod through the petal and fit the side screw. Keep the screw loose while aligning the carrier with a height/centering jig. Fit the fourth rod last without preload. Tighten progressively and mark the rods to reveal slip. Petal inserts and carrier hex nuts are distinct items in FEED-HARDWARE.csv.

The existing carrier prints top-face down and still needs slicer review/localized support for circular bores and hex-nut roofs. The new petal socket's support-free geometry does not certify the carrier or secondary as support-free. PCTG and ASA still require a fit/slip/temperature test of the printed joint; resin data alone does not rate the assembled part. Use locally solid socket walls and a suitable material profile. Avoid hollow tubing with point screws unless separately engineered for crushing and stiffness.

The carrier has 3 M3 adapter holes on 24 mm BCD and a 12 mm cable opening. A feed-specific adapter and its hardware remain separate. Strain-relieve the cable along a rod. Measure height/centering/tilt before and after tightening and warm soaking.

## Frequency and optical meaning

Frequency is unknown; enter it to enable wavelength-based dimensions and accuracy guidance.

Frequency alone does not move the focus of a fixed parabola. Prime focus remains f = D × f/D = 168.000 mm. A phase-center offset can be entered in mm or wavelengths ONLY when supported by the chosen feed design; scaling a generic unknown feed is not valid. The puck lower-face datum is z=168.000 mm; phase-center offset is 0.000 mm along +z.

Place the actual feed PHASE CENTER at the focus, not automatically its mouth or flange. A zero offset remains unverified. The feed points toward the main dish.

Auto rod sizing screens 4, 5, 6, 6.35, 8, 10, 12 and 12.7 mm SOLID aluminum using E=69 GPa and a deliberately conservative single cantilever with the entire entered 100 g payload applied transversely over the exposed span: δ=FL³/(3EI). Selected-rod result 0.361 mm. Include feed/secondary, puck, adapter and cable loads in the payload input; wind, joint compliance, resonance and creep are excluded. This is not an allowable-load calculation or an RF guarantee. Manual diameter overrides retain an over-budget warning.

- Prototype: no wind, payload or RF performance rating. Small radial screws require physical slip and warm-creep tests.
- Frequency unspecified: wavelength-dependent dimensions and RF tolerances are unavailable.
- Zero phase-center offset is a placeholder; specify the actual feed datum.

Coat the dish-facing secondary surface with continuous bonded aluminum/copper foil or a verified conductive coating; ordinary metallic paint is not sufficient evidence of RF conductivity. Keep datums, bores and the boss back clean. Surface seams/wrinkles count toward the RF error budget. Test one assembled leg for slip and creep, then the complete assembly at several elevations before committing to a full outdoor installation.

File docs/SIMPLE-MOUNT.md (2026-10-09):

# Simple alt-az mount

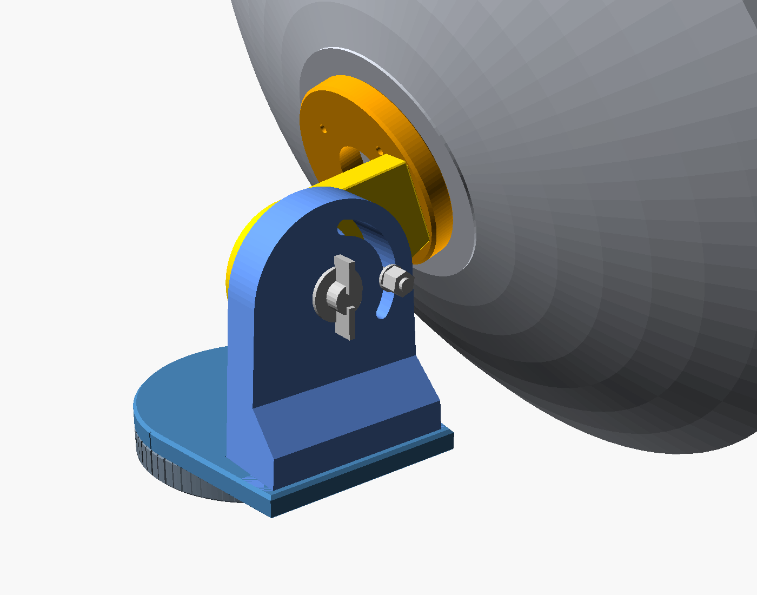
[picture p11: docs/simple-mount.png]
Simple mount with a 400 mm PETAL at 20° elevation, arc lock fitted


Five printed parts and one clamp per axis. Each clamp is two flat faces squeezed by one bolt (M8 by default): loosen, aim, tighten. The two arms, the upright and the cheek, are separate parts bolted on with heat-set inserts (M4 by default). Every bolt size can be changed; see [Bolt sizes](#bolt-sizes). That lets every part print flat, with no supports.

| | |
|---|---|
| Parts | Base, yoke, upright, cradle, cheek. Without the base: four parts |
| Azimuth | 360°. The yoke turns on the base; one bolt in the center, tightened with a hex key from above |
| Elevation | −10° to 100°, checked with the dish fitted. The cheek clamps against the inside of the upright, with one wing nut. Optional arc lock: a second bolt in an arc slot |
| Scale | Azimuth grooves down the base rim every 5°, wide every 10°, read at the groove on the back of the yoke |
| Joints | Upright → yoke plate: 4 socket heads from below. Cheek → cradle plate: 3 socket heads from the hub face. All into heat-set inserts, heads in counterbores 0.5 mm below the face |
| Mounting | 4 socket heads through the base, through the yoke plate without the base, or three legs in the tripod base |
| Supports | None. The overhang scan passes for every part; inspect your slicer toolpath |

## Options

Set them in PETAL under **Aiming mount**, or in `cad/simple-mount.scad`:

| App setting | SCAD parameter | Effect |
|---|---|---|
| Azimuth base: *Printed base with azimuth scale* (default) | `stand_holes = false` | Base + yoke turntable with the azimuth clamp and the scale |
| Azimuth base: *No base · turntable bolts to the stand* | `stand_holes = true` | No base part. The yoke plate gets 4 counterbored stand screw holes (M5 by default) from its top and screws straight onto a flat stand. No azimuth clamp: turn the stand to aim in azimuth |
| Azimuth base: *Tripod leg sockets* | `base_screws = false`, plus sockets added by the app | The base without its stand screw holes, with three splayed, tapered leg sockets on its underside. See [Tripod base](#tripod-base) |
| Elevation lock: *Add arc-slot bolt* | `arc_lock = true` | An M6 bolt runs in an arc slot through the upright, from a captive head in the cheek, for extra grip. It covers the whole −10° to 100° range |
| Elevation clamp: *Right side* (default), *Left side*, *Both sides* | `sides = "right"`, `"left"`, `"both"` | Seen from behind the dish. Left is the mirror image of right. Both sides is a U: a second upright and cheek, mirrored, on the left, so the dish is clamped at two faces and nothing twists it sideways. The bolt heads stay captive inside the cheeks and the wing nuts outside. With both sides the arc lock goes on the right. See [Keeping it from slipping](#keeping-it-from-slipping) |

### Bolt sizes

| App setting | SCAD parameter | Sizes (default) | What changes |
|---|---|---|---|
| Clamp bolts | `clamp_m` | M6, **M8**, M10 | Azimuth hole and captive nut pocket in the base; elevation holes and the head pocket in the cheek. Azimuth M × 25 socket head; elevation hex bolt 40 mm (M6, M8) or 45 mm (M10) |
| Joint screws | `joint_m` | M3, **M4**, M5 | Counterbores in the yoke and cradle plates (Ø6.5 / 8 / 9.5, 3.5 / 4.5 / 5.5 deep); insert pilots in the upright and cheek (Ø4.2 / 5.6 / 6.4). Socket heads 10 mm (upright) and 12 mm (cheek) at every size |
| Stand screws | `stand_m` | M4, **M5**, M6 | Counterbored holes in the base or, without the base, the yoke plate |
| Hub to mount (Connections tab) | `hub_m` | M3, **M4**, M5 | The four cradle holes, matching the hub's mount bolts |
| Leg cross bolt | (app only) | **Auto**, M3–M6 | Auto picks M3, M4 or M5 by leg diameter. The hole may take up to half the leg diameter |

### Seats

| App setting | SCAD parameter | Options (default) | What changes |
|---|---|---|---|
| Clamp heads | `head_pockets` | **Hex pocket**, plain hole | Pocket: the elevation (and arc lock) bolt head is held in the cheek, so one hand turns the wing nut. Plain: a through hole; the head and a washer sit on the cheek's inner face. The bolts grow to M8 × 50 and M6 × 50 |
| Azimuth nut | `nut_pocket` | **Pocket**, plain hole | Pocket: the nut is captured under the base. Plain: a through hole; the nut and a washer sit under the base. The screw grows to M8 × 40. A stand under the printed base needs a clearance hole; the tripod base has room between its sockets |
| Stand seats (no base) | `stand_counterbore` | **Counterbored**, plain hole | Plain: socket heads and washers on top of the yoke plate |

The joint screws stay counterbored, and so do the printed base's stand screws: their heads sit in the faces the yoke and the dish hub bear on.

The arc lock stays M6. The insert pilots follow the **Insert pilot** setting, which is the M4 value; M3 and M5 move by the same amount.

The STLs in `cad/STL/` are the default sizes. For other sizes export the parts from the app, or set the parameters above in the SCAD.

## Generator integration

Enable **Aiming mount** in PETAL 5.3. The app embeds blank parts for the selected options (`cad/STL/blank/`, exported with `fasteners = false`) and cuts every bolt hole, counterbore, insert pilot and nut or head pocket for the selected sizes, with the SCAD's own transforms and 32-sided holes ([`dist/mount-fasteners.js`](../dist/mount-fasteners.js)). At the default sizes the result matches `cad/STL/simple-*.stl` to float rounding. It applies the same assembly transforms in the viewer/PDF/SCAD snapshot, includes mount parts in plate packing, and checks printed-part interference at the selected pose. It reports the clearance below the lowest mount face at that pose and the geometric minimum stand height across the displayed elevation range. Add stand/cable/handling margin. The stand, hardware envelopes and complete collision sweep are not runtime-certified.

For **blind hub inserts**, use M4 × 18 through the 12 mm cradle with a 1 mm head washer, nominal 5 mm entry (M3 × 16 and M5 × 18 for the other sizes). Never use the through-bolt length in a blind insert. For **through bolts**, use the generated schedule; M4 × 35 is the default 400 mm setup.

The kinematic frame is the same for every option: elevation axis 94 mm above the base bottom (base 14 + yoke plate 10 + 70), hub face 75 mm ahead of the axis, clamp faces at x = 40. Without the base the yoke bottom, 14 mm up in that frame, is the lowest face, and the app measures stand clearance from it.

## Design choices

- **One adjustment per axis.** Elevation is a single clamp on one side. It's asymmetric on purpose, so there's one wing nut to work instead of two.
- **Split arms for print orientation.** The upright and the cheek print lying on their clamp faces. The clamp faces come out flat, both elevation bolt holes and the arc slot are vertical in the print, and the layers run along each arm, the way the dish bends it. The plates print on their bearing faces.
- **Bolted joints that resist the moment both ways.** The upright stands on the yoke plate on 4 screws: two under the arm itself (x 48) and two in a foot flange on its outer side (x 69), 64 mm apart. The dish's weight tips the upright inward, which loads the flange screws, and anything that tips it outward loads the inner pair. A low shoulder on the plate locates the upright's inner face. The large triangular flare of the one-piece yoke is gone.
- **Inset joints.** Each arm ends in a 2 mm tenon that drops into a matching pocket in its plate, with 0.2 mm clearance per side and a 0.5 mm lead-in. The tenon locates the arm and carries sideways shear, so the screws only clamp.
  - The upright's tenon is its whole footprint, foot flange included, and it bears on the pocket floor.
  - The cheek's tenon stands 2 mm inside its end face on the inner, top and bottom sides, and is flush with the clamp face so it prints without overhang. The tenon end and the end face both bear on the plate.
  - The insert pilots are 2 mm deeper, so the screws keep their length and full engagement.
- **Cheek gusset.** One solid wedge (20 mm wide, 8 × 24 mm) on the cheek's inner face at the plate end stiffens the joint and bears on the plate. It sits between the hub's bolt heads and outside the Ø34 port, and prints as an up-facing slope.
- **Socket heads in counterbores.** All joint and stand screws are ISO 4762 socket heads, the common M-series screw with a flat underside. Each sits in a counterbore 1 mm wider than the head and 0.5 mm deeper, so the head finishes below the face: under the yoke plate that is the azimuth bearing face, and on the cradle it is the face the dish hub bears on. A flat face mates cleanly with a flat head, washer or the next part, where a cone would leave a sharp lip. Where a counterbore opens toward the bed its ceiling is stepped: two 0.4 mm layers, first a slot the width of the hole, then a square, so each layer bridges a short span instead of a ring hanging in the air.
- **Clamp faces sized to the load.** The upright's cap is r 40 around the axis and holds the arc slot. The cheek's clamp disc is r 32, about 37 cm² of contact. Hand-tight on the default M8, that holds roughly 8 N·m, several times the moment of a 400 mm dish with a feed in wind.
- **A compact cheek.** The cheek tapers straight from its clamp disc to a flat 14 × 42 mm end face. The whole face sits inside the plate's rim chamfer, so it needs no corner cuts, and it clears the four hub bolt heads behind the plate. It is 70 cm³, about 30% less than the earlier 80 mm wide cheek with ribs.

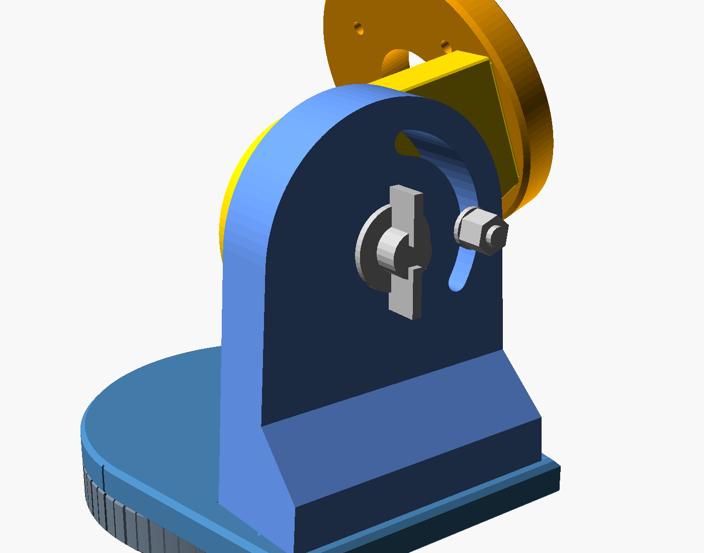
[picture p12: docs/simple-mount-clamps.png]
Elevation clamp and arc lock from the outside


## Keeping it from slipping

The elevation clamp holds the dish by friction alone, so how much it holds depends on how hard the wing nut is turned and how grippy the two faces are. The chart compares the dish's weight torque with an estimate of what each setup holds, counting only half of each estimate to allow for creep and a light hand.

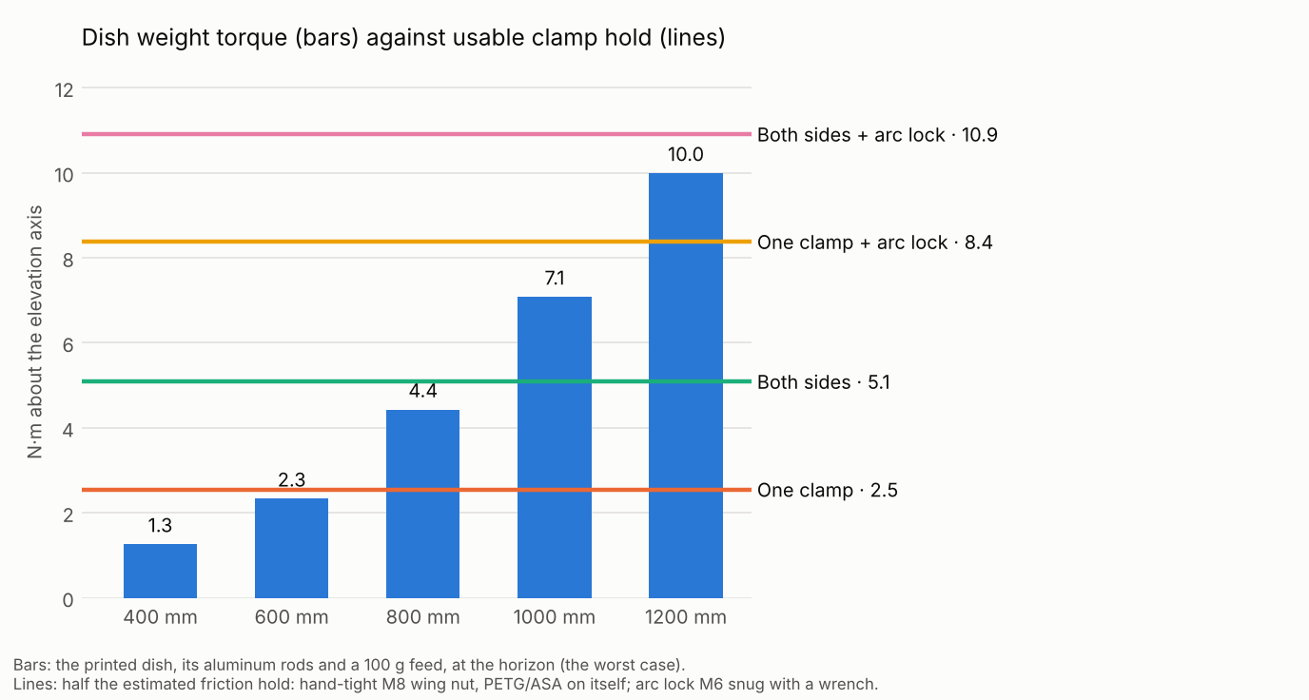
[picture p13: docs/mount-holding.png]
Dish weight torque against clamp hold, by dish size


| Setup | Estimated hold | Usable (half) | Holds, with a 100 g feed |
|---|---|---|---|
| One clamp, hand-tight M8 wing nut | 5.1 N·m | 2.5 N·m | up to about 600 mm |
| Both sides | 10.2 N·m | 5.1 N·m | up to about 800 mm |
| One clamp with a 1 mm rubber or cork pad between the cheek and the upright | 12.2 N·m | 6.1 N·m | up to about 900 mm |
| One clamp plus the arc lock, its M6 nyloc snug with a wrench | 16.8 N·m | 8.4 N·m | up to about 1100 mm |
| Both sides plus the arc lock | 21.8 N·m | 10.9 N·m | up to 1200 mm, with little margin |

How the estimates are made:

- **Preload.** A hand-tight M8 wing nut takes about 1.5 N·m, which with a nut factor of 0.2 clamps with about 940 N.
- **Friction.** PETG or ASA on itself has a friction coefficient of about 0.25; a rubber or cork pad about 0.6. The clamp disc's mean friction radius is 21.7 mm.
- **Arc lock.** The arc lock bolt is tightened with a wrench (about 2 N·m on M6, roughly 1,700 N) and sits 28 mm from the axis, so it adds more than the wing nut does. Snug it; do not crush the plastic under its 12 mm washer.
- **Dish torque.** The app's own masses: the printed parts solid at 1.24 g/cm³, the rods, and the feed payload at its focus, at the elevation where the torque is largest.

These are estimates for comparing options. Test the real thing (see [Validation](#validation)).

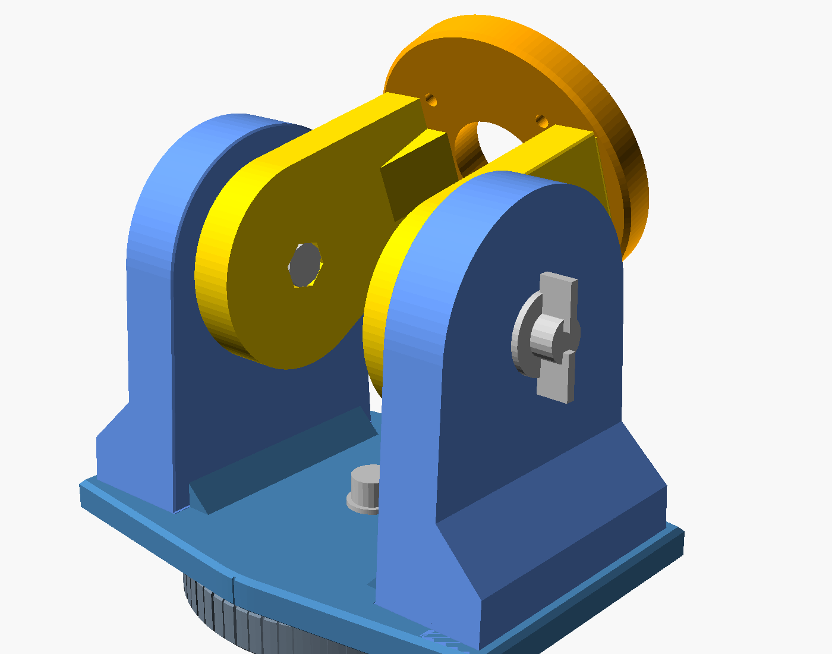
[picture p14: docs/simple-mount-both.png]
The elevation clamp on both sides: a second, mirrored upright and cheek


**Which side.** The bolt head is held in the cheek, so when the dish slips the bolt turns with it. On the right side, a slip that lets the dish nod down turns the bolt the way that unscrews it from the wing nut, so a slip loosens the clamp further. On the left side the same slip screws the bolt further into the nut and tightens it. With right-hand threads the left side is the better choice. With both sides the left clamp tightens as the right one loosens.

**Pads.** A thin rubber, EPDM or cork disc between the cheek and the upright more than doubles the grip and keeps some preload as the plastic creeps. It works with one clamp. With both sides there is no room for it: the cradle fits between the uprights with no designed gap.

**Larger dishes.** Past about 1000 mm, friction is not a dependable way to hold elevation. The reliable answer is a screw drive: a threaded rod between a pivot on the yoke and a pivot under the cradle, turned by a knob. The thread locks itself, so it cannot slip. In a first layout, with the cradle pivot 70 mm from the axis and the yoke pivot 90 mm from it, an M8 rod moves the dish about 1.3° per turn at mid-range, needs about 100 mm of travel (about 80 turns) for the full −10° to 100°, and holds a 1200 mm dish with about 200 N of thrust. It adds two printed pivots, a knob, the rod and two nuts. It is not built yet.

## Tripod base

Tripod base from below with 20 mm legs

Pick **Tripod leg sockets** as the azimuth base, enter your leg diameter (8–25.4 mm, in mm or inches) and set the splay with its slider (10–30° from vertical, default 20°). Legs are whatever round stock you have: dowel, aluminum tube or conduit.

| | Rule | 20 mm legs, 20° splay |
|---|---|---|
| Bore | leg Ø + 0.4 mm, blind, floor just below the base | Ø20.4 |
| Engagement | max(35 mm, 2.5 × leg Ø) | 50 mm |
| Wall | max(5 mm, 0.25 × Ø) at the base, tapering to max(3 mm, 0.15 × Ø) at the mouth | 5 → 3 mm |
| Shape | Octagon, flats facing the cross bolt | 30.4 → 26.4 mm across flats |
| Cross bolt | Auto: M3 below Ø14, M4 below Ø20, M5 above; or pick M3–M6. Mid-engagement, nyloc and two washers | M5 × 40 |
| Placement | As far out as the Ø116 disc allows, clear of the azimuth nut | root at r 37 mm |

Leg 1 points along azimuth zero. Each socket's flats face the tangential direction, so the cross bolt clamps two flat faces. Push the leg home, drill it through the socket hole, and bolt it.

**Printing.** The base still prints top face down, so the sockets stand up from it, leaning out by the splay. The outer faces overhang by at most the splay plus about 2° of taper. The bore floor faces up and the cross-bolt holes are teardrops. No supports.

**Leg length.** The app computes the shortest legs that do two jobs, for your actual dish, feed and mount:

- **Stability.** It sums every printed part, the aluminum rods and mast, and the feed payload at its focus, and finds the worst center-of-mass offset from the azimuth axis over the elevation range. A tripod tips first over the edge between two feet, which sits at half the foot radius. The legs must put that edge 1.5 times farther out than the offset.
- **Ground clearance.** The dish's lowest point over the elevation range must stay 20 mm off the ground.

The default 400 mm dish needs 370 mm legs at 20° splay, on a 334 mm foot circle. With the Gregorian collector the center of mass moves forward and the answer becomes 540 mm. More splay shortens the legs.

**Leg clearance.** The dish turns in azimuth over fixed legs. For every elevation the app checks whether any part of the dish comes within 3 mm of a leg or socket at any azimuth, and reports the lowest elevation that is clear all the way round. It also checks the selected pose exactly. The default dish touches a leg only below −8°, and only when it faces that leg.

These are static checks with no wind rating. Stake or weight the feet outdoors.

## Parts

STLs are in `cad/STL/`, already in print orientation, at the default bolt sizes. Use the variant that matches your options.

| Part | STL | Prints | Size (mm) |
|---|---|---|---|
| Base | `simple-base.stl`; tripod: export from the app | Top (clamp) face down | Ø116 × 14; tripod about 127 × 128 × 70 |
| Yoke | `simple-yoke.stl`; without the base `simple-yoke-stand.stl` | Bearing face down | 138 × 116 × 18 |
| Upright | `simple-upright.stl`; with arc lock `simple-upright-arc.stl` | Lying on its clamp face (x = 40) | 112 × 88 × 36 |
| Cradle | `simple-cradle.stl` | Hub face down | Ø94 × 12 |
| Cheek | `simple-cheek.stl`; with arc lock `simple-cheek-arc.stl` | Lying on its clamp face (x = 40) | 97 × 64 × 22 |
| Both sides | `simple-yoke-dual.stl` (without the base `simple-yoke-dual-stand.stl`), `simple-cradle-dual.stl`, plus `simple-upright-left.stl` and `simple-cheek-left.stl` with the right-hand upright and cheek | As above; the left arms are mirror images | Yoke 160 × 116 × 18 |

For the left side alone, mirror the yoke, upright, cradle and cheek in your slicer, or export them from the app.

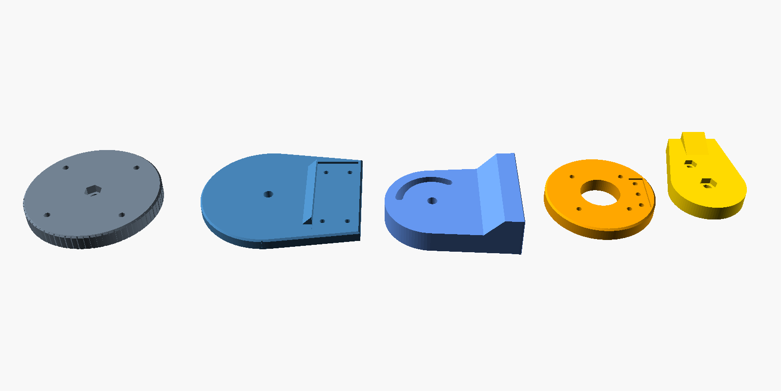
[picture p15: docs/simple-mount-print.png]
Print orientation


The cradle keeps the hub interface: Ø94 × 12 plate, Ø34 port, 4 holes on a 60 mm circle for the hub's mount bolts (M4 by default).

**Material:** use a qualified ASA or reinforced ASA profile for the rigid mount parts, with slip and warm-creep tests. This is separate from the flexible clip material; filled filament is not automatically suitable for repeatedly flexed snaps.

**Print settings:**
- 5–6 walls.
- 30–40% infill.
- Elephant-foot compensation on.
- Insert pilots are 10 mm deep blind holes (Ø5.6 for M4, Ø4.2 for M3, Ø6.4 for M5) with pointed roofs where they lie horizontal in the print. Check your insert supplier's recommended hole, and test one on a scrap print first.

## Hardware

Default sizes. The generated hardware list and PDF use the sizes you pick.

| Qty | Item | Use |
|---|---|---|
| 1 | M8 × 25 socket head, washer, nut | Azimuth (base only). The nut sits in the pocket under the base |
| 1 | M8 × 40 hex bolt, fender washer (24–30 mm OD), wing nut | Elevation. The head sits in a hex pocket on the inside of the cheek |
| 7 | M4 heat-set insert, 6 mm long or shorter, for a Ø5.6 pilot | 4 in the bottom of the upright, 3 in the cheek's end face |
| 4 | M4 × 10 socket head (ISO 4762) | Upright → yoke plate, up from below |
| 3 | M4 × 12 socket head (ISO 4762) | Cheek → cradle plate, from the hub face |
| 4 | M4 × 35 socket head, 2 washers, nut | Cradle → PETAL hub. Head behind the cradle plate; washer and nut in the seats on the hub front |
| 4 | M5 socket head (ISO 4762), length from your stand | Base → your stand, or yoke plate → your stand without the base |
| 1 | M6 × 45 hex bolt (ISO 4017), M6 washer 12 mm OD, M6 nyloc nut | Arc lock only. Head captive in the cheek; washer and nyloc on the upright's outside |

Each joint screw is the shortest stock length that reaches through the plate and the whole insert; the tips stop at least 1.5 mm short of the pilot bottoms. Use a nyloc or flange nut on the arc lock, not a wing nut: its wings would foul the M8 wing nut. The Ø12 washer is the largest that clears the M8 wing nut's swept circle (Ø39).

## Assembly

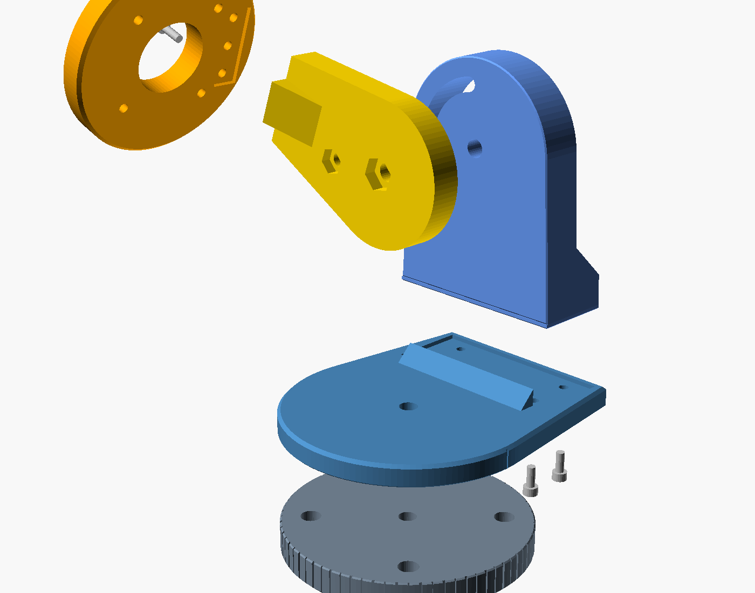
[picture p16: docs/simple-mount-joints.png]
The bolted joints, exploded


Default sizes; the generated PDF uses yours.

1. **Inserts.**
   - Heat-set 4 inserts into the pilots in the bottom of the upright and 3 into the cheek's end face, each 0.5 mm below the tenon entry face (the tip of the 2 mm tenon), not below its surrounding shoulder.
   - Let them cool. Scrape off any raised rim so the mating faces stay flat.
2. **Upright on the yoke plate.**
   - Drop the upright's tenon into the pocket in the plate, against the locating shoulder.
   - Drive the 4 × M4 × 10 up through the plate from underneath. The heads must finish below the bottom face.
3. **Base on the stand** (with the base).
   - Press the M8 nut into the pocket underneath.
   - Screw the base down with the 4 × M5 socket heads.
   - Set the yoke on the base. Drop in the M8 × 25 and washer and tighten it into the nut with a 6 mm hex key.
4. **Yoke on the stand** (without the base).
   - Put the yoke plate, upright already fitted, on a flat stand.
   - Drive the 4 × M5 socket heads down through its counterbores, heads below the top face. They are reached from above beside the upright, so do this before the cradle goes on.
5. **Cheek on the cradle.** Drop the cheek's tenon into the pocket in the back of the cradle plate, then fit it with the 3 × M4 × 12 from the hub face, heads below the face. Do this before the dish hub covers that face.
6. **Cradle on the dish.**
   - Push the 4 × M4 × 35 with washers through the cradle plate from behind, then through the hub.
   - Put a washer and nut on each in the Ø10 seats on the hub front and tighten.
7. **Elevation bolt.** Seat the M8 × 40 head in its pocket on the inside of the cheek. With the arc lock, also seat the M6 × 45 head in the second pocket.
8. **Both sides.** Do steps 1, 2, 5 and 7 for each arm. The cradle fits between the uprights with no designed gap; each upright's tenon has 0.2 mm of play. Screw the left upright down, offer the cradle with both cheeks fitted, then screw the right upright down while pressing it against its cheek. Build the whole U on the bench before setting the yoke on the base: the upright screws are reached from under the yoke plate. Tighten both wing nuts evenly.
9. **Cradle on the upright.**
   - Slide the M8 out through the upright, and the M6 into the arc slot.
   - Add the fender washer and wing nut on the outside, and the M6 washer and nyloc.

## Using it

- **Azimuth (with the base):**
  - Loosen the center bolt from above.
  - Turn the dish, read the rim ticks at the yoke's rear groove, then tighten.
  - The key reaches the bolt with the dish anywhere from −10° to 30°.
- **Azimuth (without the base):** there is no azimuth clamp. Turn or re-fix the stand. The central Ø8.5 hole stays open.
- **Elevation:**
  - Hold the dish, loosen the wing nut (and the arc lock nyloc), set the angle and tighten the wing nut, then snug the nyloc with a 10 mm wrench.
  - The arc slot's ends stop the cradle just beyond −10° and 100°.
  - Read the angle with a phone inclinometer on the dish rim or the back of the hub plate.
- **Clearance:** at −10° the rim hangs 129 mm below the base bottom, or 143 mm below the yoke plate without the base. Mount the lowest face at least that high.
- **With snap-clip seams:** the clips hang about 6–9 mm farther behind the dish than the flanges. Elevation then clears from −7.5° to 100°.

## Loads

- **Elevation:**
  - About 1.2 N·m per kg of dish at the horizon.
  - Grip depends on actual preload, friction, contact and temperature; no allowable holding torque is established. The arc lock adds a second clamp point 28 mm from the axis; it is not rated either.
  - If it creeps, stop and review preload, material, bearing stress and clamp design. Do not solve slip by indefinitely increasing torque.
- **Off-center load:** the dish sits about 40 mm off the clamp. The single joint carries that sideways moment through the full face and the bolt.
- **Joints:** the insert joints are not load-rated. Check them for creep and loosening along with the clamps.
- **Azimuth:** only wind loads it, over 100 cm² of contact.

## Validation

### `scripts/check-simple-mount.py <stl dir>`
It reads the print transforms from the SCAD, places all eight STLs with them, and checks the default, arc-lock and no-base variants:

- **Bed fit and printability:** closed, single-body meshes that fit the bed, and an overhang scan (below).
- **Joints:**
  - The upright sits flush on the yoke plate (29.6 cm²) and the cheek on the cradle plate (6.2 cm², gusset included), each face bearing fully.
  - Each tenon drops into its pocket with 0.2 mm clearance and locks its arm sideways in every direction.
  - All 7 socket heads sit 0.5 mm below the face in their counterbores and stop short of the pilot ends; the inserts fit their pilots with at least 2 mm of plastic around them.
  - The screws clear every other bolt, head and nut.
- **Clamp contact:**
  - Azimuth: 100 cm².
  - Elevation: 36–38 cm² across the range, 32–34 cm² with the arc slot.
- **Hardware:** the bolts, heads and wing nut sit in their holes and pockets at every angle.
- **Elevation travel:** −10° to 100°, clear of the yoke, upright and hardware. The first contact is at −22.5°.
- **Arc lock:** the M6 runs clear through the slot from −10° to 100°, and its washer stays inside both clamp faces and clear of the M8 fender washer and wing nut at every angle. The slot ends stop travel at about −12° and 102°.
- **Both sides:** the left upright and cheek are exact mirror images of the right ones. Each arm sits flush on the dual yoke and cradle with its screws seated, each clamp keeps 36–38 cm² of contact over the range, and both bolts sit in their holes and pockets with the heads inside and the wing nuts outside. The cradle tilts from −10° to 100° (with the arc lock too), the dish clears both uprights, everything that turns clears the base, the hex key still reaches the azimuth bolt from −10° to 30°, the hub bolts and port stay open, and without the base the four stand screws clear both uprights and are reached straight down.
- **Dish clearance:** the dish clears the yoke, upright and base over the same range. With snap-clip seams, modeled as a ring 26 mm deep behind the dish, it clears from −7.5° to 100°.
- **Azimuth sweep:** everything that turns clears the base all the way around, at −10°, 0°, 45° and 90°.
- **Tool access:** the hex key reaches the azimuth bolt, and a Ø10 driver reaches each stand screw with the upright fitted.
- **Hub interface:** the M4 holes and the Ø34 port are open with straight access from behind. The root nuts and washers behind the hub and the hub bolt heads behind the plate are clear. The joint counterbores sit between the port, the hub bolts and the rim.

### `scripts/check-printability.py cad/STL/simple-*.stl`
All eight parts pass. A part fails on any downward face more than 60° from vertical, unless it is a flat ceiling (within 20° of flat) no more than 10 mm across, which prints as a bridge, or a step within 0.3 mm of the bed. Faces between 45° and 60° are listed but pass: at 0.2 mm layers each layer steps out at most 0.35 mm, under one extrusion width. The counterbore ceilings are the bridges here, 4.5 to 6.5 mm across. The same holds for parts exported from the app at the smallest (M3 / M6 / M4) and largest (M5 / M10 / M6) sizes, and for the tripod base with M10 clamps and M6 leg bolts.

### Bolt sizes
- `tests/integration.test.mjs`: at the default sizes, the app's cuts on the blanks reproduce all eight complete STLs (difference under 0.5 mm³, the same number of holes), the hole diameters follow each size setting, and each plain-hole seat option removes its pocket or counterbore.
- `scripts/check-scad.mjs`: `cad/simple-mount.scad` rendered with `joint_m = 5`, `clamp_m = 10`, `stand_m = 6` and `hub_m = 3` matches the app's parts to float rounding, including the dual yoke and cradle and a left upright with `sides = "both"`.

### Regenerating
`python3 scripts/pack-mount.py --export` re-exports every complete STL variant and every blank (`cad/STL/blank/`) from the SCAD and rebuilds `dist/mount-meshes.js` from the blanks, with each part's frame, the inverse of its SCAD print transform and the constants the cuts need. `python3 scripts/render-mount.py` redraws these images.

These are geometry checks. Grip and creep need a physical test: set the dish at 0°, tighten everything, leave it somewhere warm for 48–72 hours, re-tighten once after the first day, then check the angle again.

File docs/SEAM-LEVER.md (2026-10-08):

# Seam lever (quick-release, screwless)

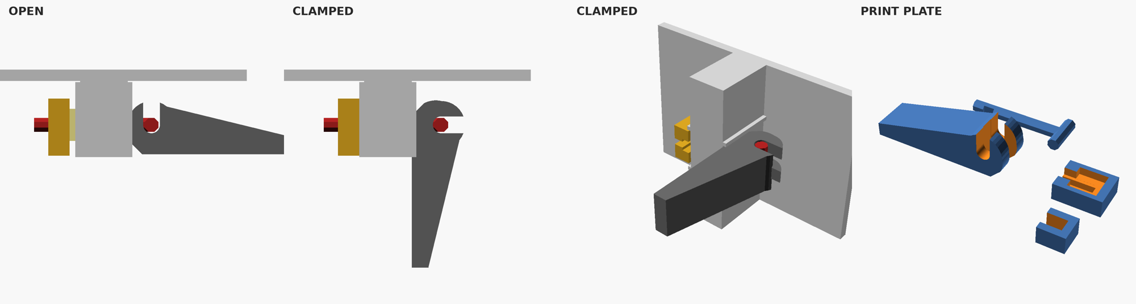
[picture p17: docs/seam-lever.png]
Seam lever open, clamped, and on the print plate


A cam-lever clamp for seam stations. Flip the handle down to clamp, flip it out to release. No screws. Use bolts where a seam should be permanent.

In the app, choose **Seam fastening → Seam levers**. The petals get the same stations as **Both** (bolt hole, clip window, guide ridges), and the kit includes a lever, draw bar, keeper and spring for every station plus spares, sized to the selected **Seam bolt size** (M3 or M4 holes). The assembly view shows each set installed. At ring junctions where a neighboring flange is in the way, the set is turned to the other side of the seam; if neither side has room, that station takes a bolt, and the hardware list says how many. TPU springs are packed on their own print plates.

| | |
|---|---|
| Parts | Lever, draw bar, keeper (PCTG), spring (TPU 95A, or disc/coil springs in the same 7 mm pocket) |
| Stations | Seam joint **Both**: 5 mm flat walls, clip window, guide ridges 10.8 mm apart, bore 2.2 mm below station level |
| Holes | `STL/seam-lever-M3` fits the Ø3.4 holes cut with **Seam bolt size M3**; `STL/seam-lever-M4` fits the Ø4.5 holes cut with **M4** |
| Action | About 1.1 mm draw, a 0.3 mm over-center hump, then the cam seats on a flat; clamp load pushes it further closed |
| Supports | None. Overhang scan finds no face steeper than 45° off the bed |

## Install

1. Push the bar through both flange holes from the lever side.
2. Slide the keeper, with its spring, up onto the bar's neck from behind the dish.
3. Push the lever's open slot up onto the bar's cross pin with the handle sticking straight out.
4. Flip the handle down along the flange.

Release in reverse: handle out, drop the lever off the pin, slide the keeper down.

## Printing

Print the STLs as oriented, at full scale (the bar is sized to the hole).
- **Lever:** stands on its clamping flat; the pin slot opens upward.
- **Bar:** flat on the bed, so the shaft and pin run along the extrusion lines.
- **Keeper:** back face down, pocket up.
- **Spring:** tune clamp force with TPU walls/infill or `spring_t`, not the cam.

## Strength

Ballpark only, not a rating: the M3 bar neck is about 4 mm² (around 150 N ultimate in PCTG); M4 is roughly double. Intended for many stations sharing the load as a quick-assembly option.

## Changing it

`cad/seam-lever.scad` takes the station geometry from the generator (`wall`, `hole_d`, `hole_y`, `ridge_gap`, `shell_y`) and derives the bar, cam and keeper from it. Tuning values: `stroke`, `hump`, `pre`, `spring_t`, `pocket`, `handle_l`. Export a part with `-D 'part="lever"'` (or `bar`, `keeper`, `spring`, `plate`); `part="assembly"` with `closed=true|false` shows it on a mock station, and `installed_*` gives each part in its clamped pose in the station frame. After changing the SCAD, run `python3 scripts/pack-lever.py`: it re-exports both STL sets and the meshes bundled into the app (`dist/lever-meshes.js`).

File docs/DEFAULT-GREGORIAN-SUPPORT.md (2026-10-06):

# PETAL Gregorian collector

The dish gathers, the bowl folds the focus back down, and the insert sits under the bowl looking up. Rays from the dish converge on the prime focus F1 (z = 168.0 mm), cross it, strike the concave bowl just beyond it and reflect down to the second focus F2 (z = 96.8 mm). Put the insert's phase center at F2. The insert, its cup and the mast all stand inside the bowl's shadow, so the only aperture blockage is the bowl itself: 4.9%.

## How the bowl is shaped

The bowl is a section of a prolate ellipsoid whose two foci are F1 and F2 (the Gregorian condition). Any ray through one focus reflects through the other, so the fold is exact for every ray from the dish. About F1, the surface is t(ψ) = b² / (a + c·cos ψ) with a = 74.101, b = 64.999 and c = 35.581 mm; ψ is measured from the dish axis.

It is re-solved on every build from the dish diameter and f/D:

- Rim: the bowl edge sits at the dish rim angle 61.5° plus 3° spill margin (64.5°), so every ray from the dish lands on the bowl.
- Focus spacing: F1 to F2 is 71.2 mm, set so the rim ray reaches the insert at ±25°.
- Size: the smallest bowl whose shadow still covers the insert cup, or N wavelengths when a frequency is set, or the entered diameter. This one is Ø85.3 mm (minimum Ø85.3).

A deeper dish or a narrower insert angle spreads F1 and F2 further apart, so a smaller bowl still shades the insert. A larger insert needs a larger bowl.

Magnification M = (1 + e) / (1 − e) = 2.85, with eccentricity e = c / a = 0.480. The insert sees the system as an f/D 1.20 dish: the dish rim arrives at ±23.6° and the bowl edge at ±25°. Choose an insert whose −10 dB beam edge is near ±25°.

## Parts

- Collector bowl, Ø85.3 mm, 3 mm shell. The wall thickens into 3 rod seats between the flat top and the rim, so nothing hangs below the rim. Prints on its flat top with the reflecting face up; no supports.
- Mast foot: bolts to the hub front through the four mount holes. Prints flange down.
- Insert cup: Ø30 mm bore, 12.0 mm deep, on the mast tube. Prints socket down.
- Mast tube: Ø16 mm, cut 71.8 mm. Aluminum or rigid conduit; the insert cable runs inside it.

## Assembly

1. Heat-set the M3 inserts: one in each petal rod socket and one in the rib of the mast foot and insert cup.
2. Bolt the mast foot to the hub front with the four mount through bolts; the nuts sit on top of the 6 mm flange.
3. Feed the insert cable through the tube, seat the tube in the foot and the cup, and snug both set screws.
4. Seat the insert in the cup with its phase center 0.0 mm above the cup rim (z = 96.8 mm).
5. Mark each of the 3 × Ø6.35 mm rods (cut 229.0 mm) 18 mm from the petal end and 11 mm from the bowl end. Fit them into the petals, then push them into the bowl's rod seats up to the marks. Center the bowl over the hub, drill each rod Ø3.2 through the seat's cross hole, then fit the M3 bolts with a washer on each flat face and a nyloc.
6. Line the bowl's concave face with bonded aluminum or copper foil, seams pressed flat.

## Checks

- Heights run along the dish axis from the paraboloid vertex; the hub front is at z = 4.0 mm.
- Bowl vertex z = 206.5 mm, rim z = 188.3 mm.
- Bowl apex to insert: 109.7 mm.
- Shadow cone half-angle from the prime focus: 15.0°. Keep everything under the bowl inside it.

- Prototype: no wind, payload or RF performance rating. Small radial screws require physical slip and warm-creep tests.
- Frequency unspecified: wavelength-dependent dimensions and RF tolerances are unavailable.
- Ellipsoidal ray geometry is not an electromagnetic validation; measure the assembled collector against a reference antenna.

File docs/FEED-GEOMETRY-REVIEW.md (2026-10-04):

# Direct rod attachment review · revision 7

The broad revision-6 pyramid is replaced by a small rounded rod collar and side-insert ear. Their tapers follow the dish underside; only the internal rod bore follows the calculated rod angle. There are no separate rim shoes or backers.

Default actual CAD, six angles and installed hardware

The default mounting petal adds approximately **1.52 cm³**, versus 7.45 cm³ for revision 6: about **80% less added material**. Maximum local underside depth is approximately 7.55 mm for the default 6.35 mm rod. Both dimensions grow with the supplied rod diameter.

Rod diameter is user-entered in millimeters or inches, from 2 to 12.7 mm. Internally all geometry uses millimeters. Both end bores use the supplied diameter plus diametral clearance; automatic sizing retains the 4/5/6/6.35/8 mm stock list.

The nominal round bearing is fully enclosed by a bore with short 45° roof shoulders and a **0.8 mm bridge**, rather than a pointed teardrop apex. The side pilot is circular and aligned nearly vertically in the exported petal orientation. Petal retention uses a short M3 heat-set insert (maximum 4 mm long, compatible with the 4.2 mm pilot) and an M3 × 12 headless screw. Carrier hex nuts remain unchanged.

## Validation

The size/focal-ratio sweep covers dishes from 260 to 1200 mm and f/D from 0.25 to 0.8, plus custom 3.175, 7.9375 and 12.7 mm rods, phase-offset limits, four legs, thin/thick shells and faceted backs. **52 combinations build; 12 fail the existing optical or rod-path limits explicitly.**

Independent mesh checks verify connected, watertight solids, complete nominal rod clearance, screw and insert access, and the full 4 mm insert's retaining wall. Print-angle checks use the actual side-print up vector. The only bridge exemption is the measured 0.8 mm roof; other local faces must meet the 45° criterion. These checks do not qualify physical strength, creep, or printed fit.

[Small deep dish](feed-review/260-0.25-1.png) · [Large deep dish](feed-review/1200-0.25-1.png) · [Secondary support](feed-review/800-0.6-2.png)

The general test suite, offline UI conversion tests and OpenSCAD volume/bounds comparisons cover the updated geometry and exports. The unchanged carrier and secondary still need localized slicer support review. Regenerate all feed parts and rod cuts together; previous feed revisions do not interchange.

Reproduce the sweep with `node scripts/check-feed-envelope.mjs` and `python3 scripts/check-feed-envelope.py`. Render actual mesh views with `python3 scripts/render-feed-review.py CASE_ID`. Python dependencies: NumPy, Pillow, trimesh and manifold3d.

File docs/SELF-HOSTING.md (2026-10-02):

# Self-host PETAL on Linux

PETAL runs entirely in the browser. The server only delivers static files; models, STL/ZIP exports and the illustrated PDF are generated on the user's device. No database, Node runtime, printer software or PDF daemon is required on the server.

## One-shot installation

Download [install-linux.sh](../scripts/install-linux.sh), then run:

```bash
sudo bash install-linux.sh --port 56302 --ref main
```

Or download and install in one command (requires curl for this initial download):

```bash
curl -fL https://raw.githubusercontent.com/xattribution/petal-dish/main/scripts/install-linux.sh -o /tmp/petal-install.sh && sudo bash /tmp/petal-install.sh --port 56302 --ref main
```

The commands install the current merged release from `main`. A commit SHA or tag can be used instead of a branch for repeatable installs.

Change `56302` to your preferred TCP port (1-65535). Open `http://SERVER-IP:56302`. Add `--localhost` to bind only 127.0.0.1, for example behind an existing reverse proxy.

The downloaded script installs its remaining dependencies. If you start from a downloaded file, Bash and sudo/root are the only bootstrap requirements. The single curl command also needs curl installed beforehand.

## What it installs

Supported: systemd Linux on x86_64, ARM64 or ARMv7, using apt-get (Debian/Ubuntu), dnf/yum (Fedora/RHEL-family), zypper (openSUSE), or pacman (Arch). Arch uses your existing package database; update the OS normally first if it is out of date. The installer does not perform a full OS upgrade. Unsupported init systems/architectures stop with an explanation.

- Installs curl, CA certificates, tar and Python 3 through the system package manager. Python is only used during installation to validate/extract downloads.
- Resolves the selected GitHub ref to one commit, downloads that archive, and verifies the prebuilt web files against BUILD.json. It refuses old builds rather than silently hosting an older interface.
- Downloads Caddy 2.11.4 from its official GitHub release and verifies its SHA-512 against the release checksum list. Caddy is isolated at `/opt/petal/caddy`; existing web-server configuration is untouched.
- Installs static releases under `/opt/petal/releases/COMMIT` (with a suffix on repeat installs), with `/opt/petal/current` pointing to the active release.
- Writes `/etc/petal/Caddyfile` and a dedicated `/etc/systemd/system/petal.service`, running as a systemd dynamic user. The service starts now and at boot. A failed startup/health check restores the prior PETAL configuration and active release.
- Sends `Cache-Control: no-cache`, so clients revalidate assets. The interface shows the version/build ID and has a versioned offline download. BUILD.json exposes the exact installed build.

Package-manager changes are not rolled back. Previous static releases are retained for recovery; there is no automatic OS, Caddy or application update process.

## Network access

The default listens on all IPv4 interfaces over **HTTP**. The installer does not change firewall rules, router forwarding, DNS or TLS. On a filtered host, allow your chosen TCP port using your existing firewall policy. For internet access, put it behind your normal HTTPS reverse proxy; `--localhost` is suitable when that proxy is on the same host. This is a public static application with no login, uploads or server-side model storage.

## Updating or changing ports

Re-run the installer with the desired ref and port. To pin a build, use its full commit SHA. Check the header build ID or:

```bash
curl http://127.0.0.1:56302/BUILD.json
sudo systemctl status petal.service
sudo journalctl -u petal.service -n 60 --no-pager
```

If another application already uses the chosen port, select a free one and re-run. Do not stop an unrelated service to make room. System logs show bind/startup errors.

To roll back manually, stop PETAL, point `/opt/petal/current` to a retained release, and start it again. The release must match its bundled index, JavaScript, CSS and offline file; do not mix assets from different builds.

## Offline edition and stale copies

The current standalone download is `petal-5.3-offline.html`. It contains both the geometry and PDF engines. Open that file itself in a browser; a mail/file-manager HTML preview may disable JavaScript. Expect **PETAL 5.3**, a build ID, and **flange joints** in the header, seven default printed parts, and an Assembly manual PDF button. Legacy strap/plate selectors indicate an older file.

The old hosted `petal-offline.html` URL redirects to the versioned download. That small redirect is not itself an offline app. Previously downloaded files do not update themselves: download the new version explicitly and remove or rename old copies.

## Manual hosting / containers

Serve the complete verified `dist/` build from an existing static server, preferably with revalidation enabled. For Caddy:

```caddyfile
http://:56302 {
    root * /absolute/path/to/petal-dish/dist
    header Cache-Control "no-cache"
    file_server
}
```

A container should expose TCP 56302 and mount the static build read-only. The installer intentionally requires a systemd host; it does not install an init system inside containers. To rebuild from source, use a supported Node.js version satisfying package-lock dependencies, run `npm ci && npm run build`, then serve the generated files together. Node is unnecessary when hosting the committed prebuilt distribution.

## Removal

```bash
sudo systemctl disable --now petal.service
sudo rm /etc/systemd/system/petal.service
sudo systemctl daemon-reload
```

After confirming you no longer need the installation or retained releases, remove `/opt/petal`, `/etc/petal` and `/var/lib/petal`. The installer does not remove system packages shared with other applications.

Caddy references: https://caddyserver.com/docs/quick-starts/static-files and https://github.com/caddyserver/caddy/releases/tag/v2.11.4

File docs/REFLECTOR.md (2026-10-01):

# Reflector surface and RF setup

PETAL prints a support structure. The frequency, feed, conductive finish and mount determine whether the assembled system works as an antenna. There is no measured gain or RF rating for this design.

## Recommended first article: a continuous foil face

Use a thin aluminum foil tape whose adhesive is explicitly conductive, for example 3M 1170. 3M 1181 copper foil tape is another conductive-adhesive option, but copper adds more mass. These are examples of material construction, not qualified PETAL finishes or outdoor lifetime guarantees. Ordinary HVAC tape may have insulating adhesive; overlapping it does not guarantee electrical contact between strips.

Sources: https://www.3m.com/3M/en_US/p/d/b5005158003/ and https://www.3m.com/3M/en_US/p/d/b5005158005/

1. Print an adhesion/coating scrap from the actual filament. Check the tape and any primer after a warm hold and gentle peel. Do not assume adhesion to an injection-molded plastic transfers to a printed surface.
2. Dry-fit, mark and measure the uncoated assembly. Complete heat-setting before applying the conductive finish. Lightly remove burrs; do not sand the parabola into a different shape.
3. Apply narrow strips to each front petal, burnishing gently from the center outward. Start around 10–20 mm strip width and reduce it where compound curvature causes wrinkles. Avoid stretching foil tight across gaps or unsupported holes. Keep overlaps small and consistent; record their height if operating at short wavelengths.
4. Mask flange datums, bearing faces and bores. Cover the central hub front with the same finish. Do not bridge a pocket with foil that a screw will tear during service.
5. Assemble and align first. Bridge seams with removable strips afterward, without pulling petals together. Remove these strips before disassembly. Do not use a continuous skin as an alignment clamp.
6. With power disconnected, check foil-to-foil continuity across strips, hub and seams at many points. Compare against the meter’s shorted-lead baseline; intermittent or unexpectedly high resistance needs investigation. DC continuity is a useful workmanship check, not proof of RF efficiency.
7. Recheck surface shape, adhesion and continuity after thermal cycling and repeated assembly. Corrosion, water ingress and differential expansion require an outdoor finishing plan. Do not assume a generic clearcoat is RF-neutral or compatible with the tape. Keep a specular foil-covered dish pointed away from the Sun during handling; concentrated sunlight near the focus can heat the feed or fixture.

## Conductive paints

A specified silver or silver-coated-copper conductive coating is an alternative when foil wrinkles are unacceptable. Examples are MG Chemicals 842AR and 843AR. They are designed as conductive shielding coatings; that does not establish antenna-reflector performance on PETAL. Follow the current technical data and safety sheets, verify dry-film thickness and sheet resistance, and test solvent/primer compatibility on the actual ASA, ABS or PCTG print. Solvent attack, shrinkage and poor adhesion can ruin surface accuracy. Metallic-looking craft paint, ordinary graphite paint and carbon-filled filament are not automatically suitable low-loss reflectors.

Sources: https://mgchemicals.com/products/conductive-paint/conductive-acrylic-paints/silver-conductive-paint/ and https://mgchemicals.com/products/conductive-paint/conductive-acrylic-paint/copper-conductive-paint/

## Perforations and mesh

This version has no perforation mode. Conductive mesh must be chosen for the intended wavelength; openings, wire size, conductivity and surface accuracy all matter. Do not equate percent open area with gain loss. A continuous foil covering over printed holes needs support against sagging and will largely block airflow. Reference: https://www.gmrt.ncra.tifr.res.in/doc/WEBLF/LFRA/node173.html

## Feed and alignment

This configuration has focal length 168.00 mm from the parabola vertex, dish depth 59.52 mm, and rim half-angle 61.53 degrees as seen from the focus. The vertex is the extrapolated center of the parabola, not the rear hub surface or rim plane. Place the feed phase center at the focus and match its illumination to that rim angle. Provide rigid, adjustable axial/lateral positioning and polarization adjustment. Route and strain-relieve the cable so it cannot move the feed. Enable the optional rod support to generate mounting parts and rod cuts. The RF feed is not supplied.

Choose an operating band before setting surface tolerances. As an engineering starting budget, allocate no more than wavelength/50 RMS to structural/assembly error, then account separately for finish, feed and pointing. This is a proposed test criterion, not a verified capability. Use the shortest wavelength in a band. Measure at several azimuths and elevations; systematic seam steps and defocus need attention beyond a single RMS number.

Check feed return loss if equipment is available, but also compare received level and beam pattern against a known reference with fixed polarization, cable, receiver gain and geometry. Good impedance matching alone does not prove reflector gain. Use a suitable far-field range or a properly characterized near-field method, rather than a nearby transmitter of unknown geometry. RF background: https://www.cv.nrao.edu/~sransom/web/Ch3.html

## Material references

ASA: outdoor UV/temperature suitability, with significant warping risk unless the printer environment is controlled: https://help.prusa3d.com/article/asa_1809
PCTG: manufacturer-specific material data; heat-distortion temperature is not a continuous precision-service limit: https://fiberlogy.com/en/fiberlogy-filaments/pctg/
Inserts and plastic creep: https://www.spirol.com/resources/white-papers/how-to-properly-mate-compression-limiters-and-threaded-inserts-in-plastic-assemblies/

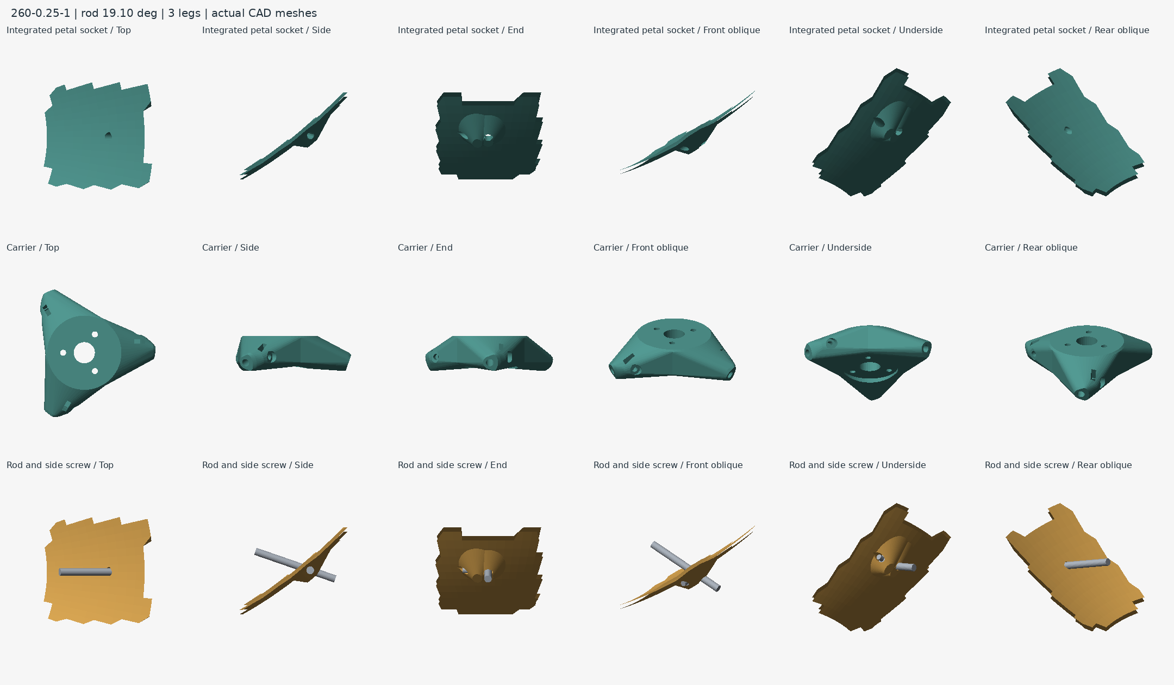
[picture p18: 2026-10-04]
docs/feed-review/260-0.25-1.png

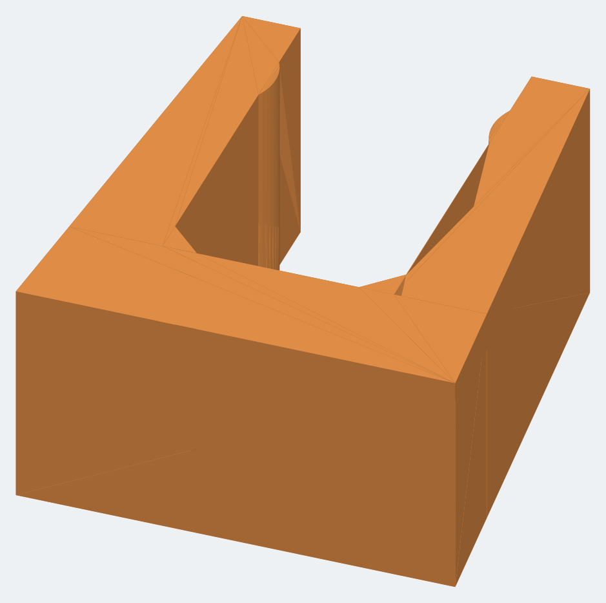
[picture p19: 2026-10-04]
docs/snapshots/clip.png

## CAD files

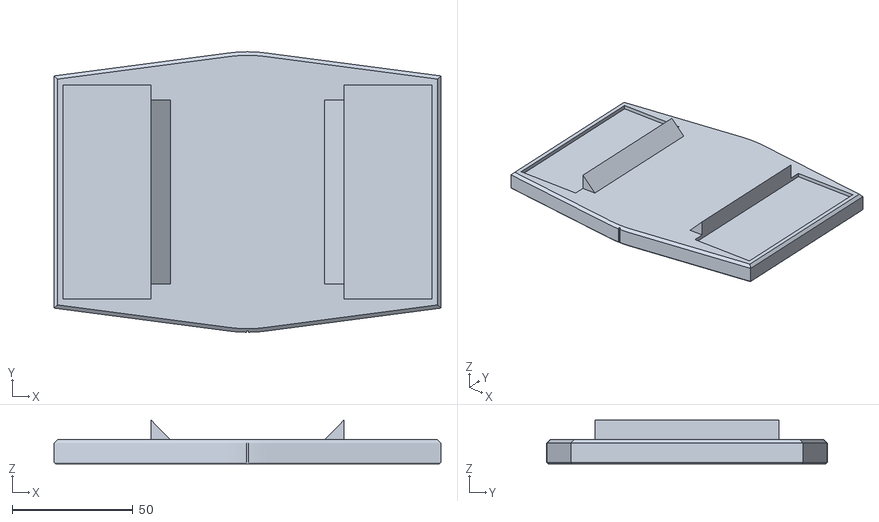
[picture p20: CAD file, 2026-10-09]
cad/STL/blank/simple-yoke-dual.stl
160.0 x 116.0 x 18.0

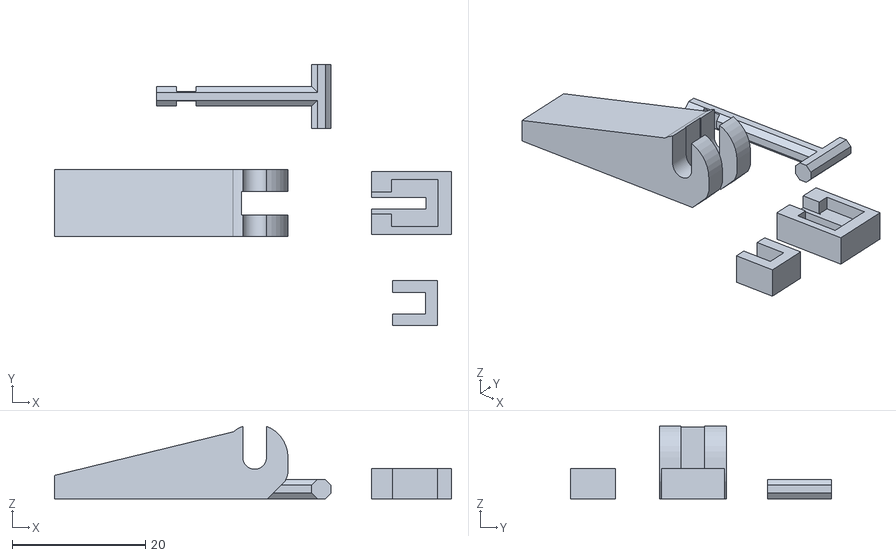
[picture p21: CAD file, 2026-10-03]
cad/STL/seam-lever-M3/plate.stl
59.5 x 39.2 x 10.9

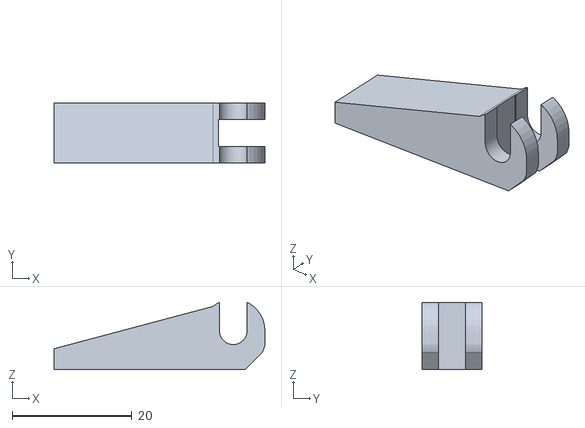
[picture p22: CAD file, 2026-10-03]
cad/STL/seam-lever-M4/lever.stl
35.3 x 10.0 x 11.3

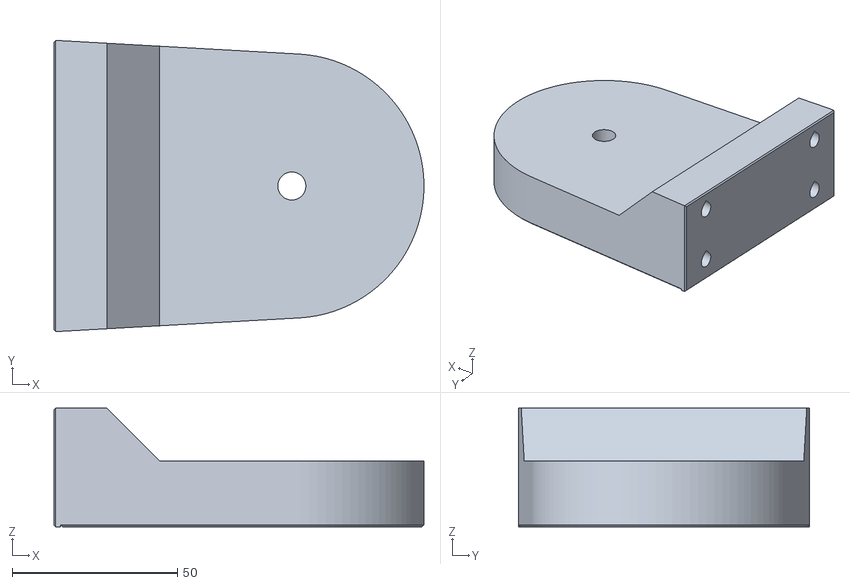
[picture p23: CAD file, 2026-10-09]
cad/STL/simple-upright-left.stl
112.0 x 88.0 x 36.0

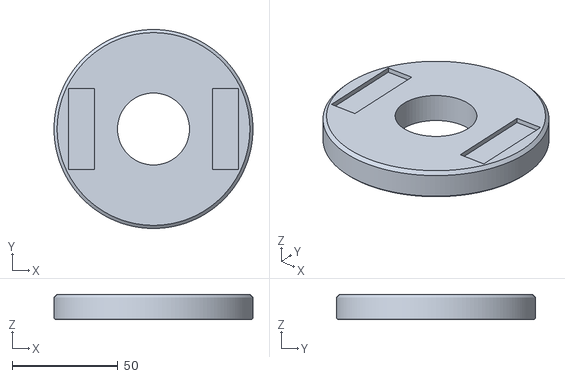
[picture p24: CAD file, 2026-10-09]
cad/STL/blank/simple-cradle-dual.stl
94.0 x 94.0 x 12.0

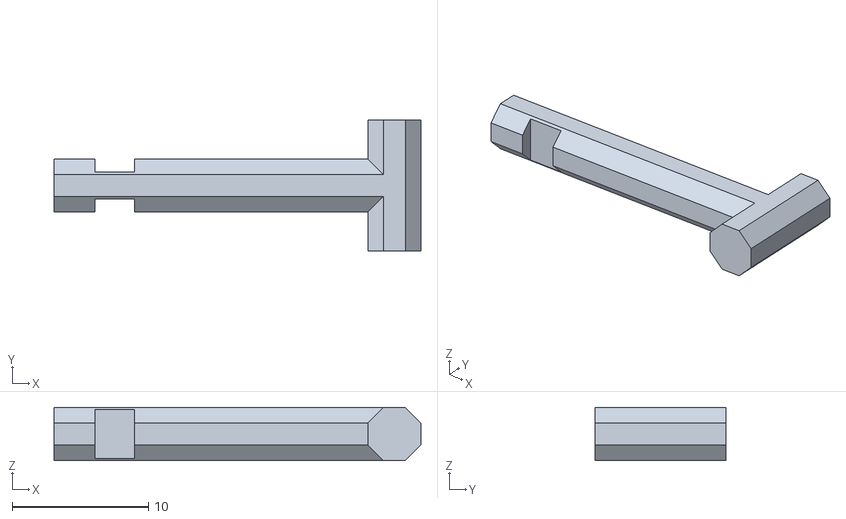
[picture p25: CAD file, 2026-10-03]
cad/STL/seam-lever-M4/bar.stl
27.0 x 9.60 x 3.90

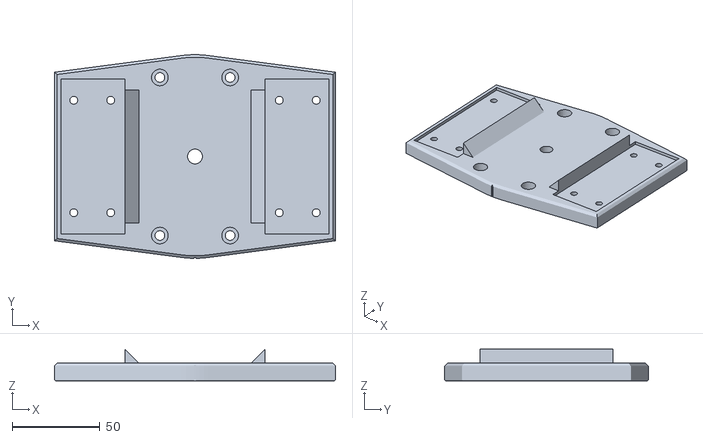
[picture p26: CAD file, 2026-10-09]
cad/STL/simple-yoke-dual-stand.stl
160.0 x 116.0 x 18.0

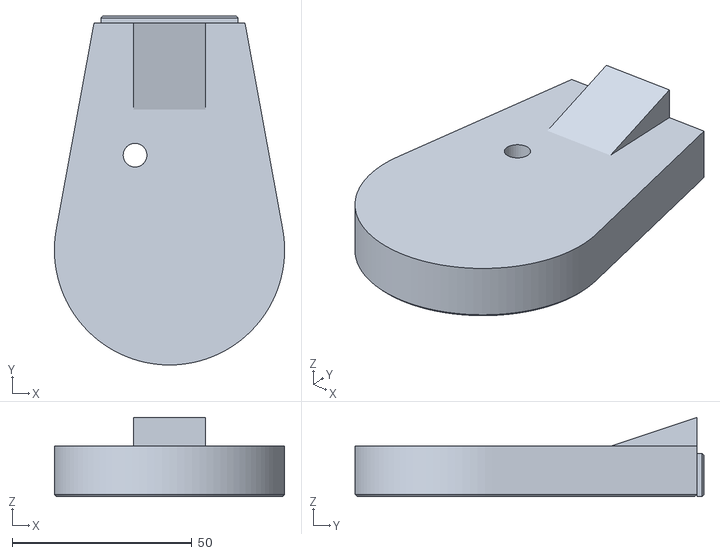
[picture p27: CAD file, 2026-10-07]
cad/STL/blank/simple-cheek-arc.stl
64.0 x 97.0 x 22.0

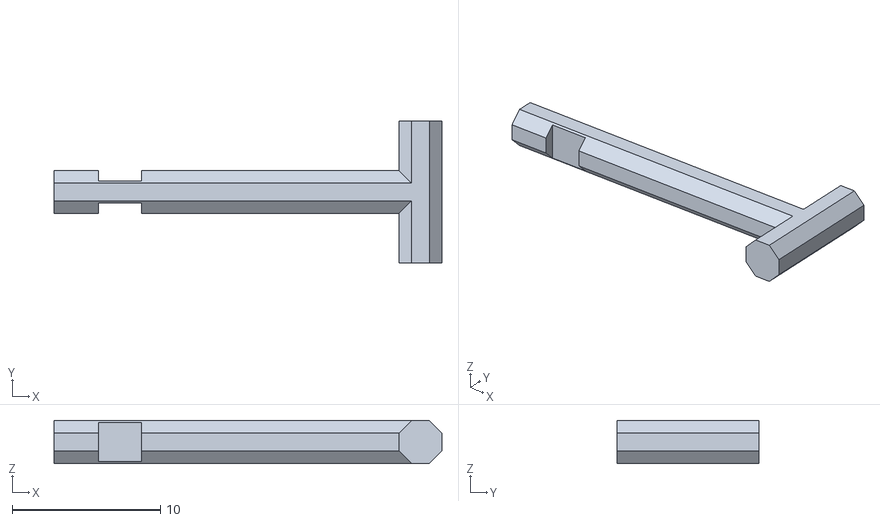
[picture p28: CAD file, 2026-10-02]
cad/STL/seam-lever-M3/bar.stl
26.1 x 9.60 x 2.90

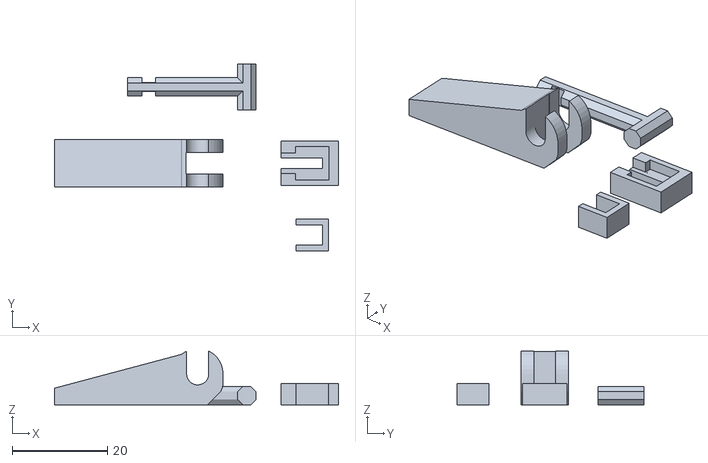
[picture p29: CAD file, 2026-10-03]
cad/STL/seam-lever-M4/plate.stl
59.5 x 39.2 x 11.3

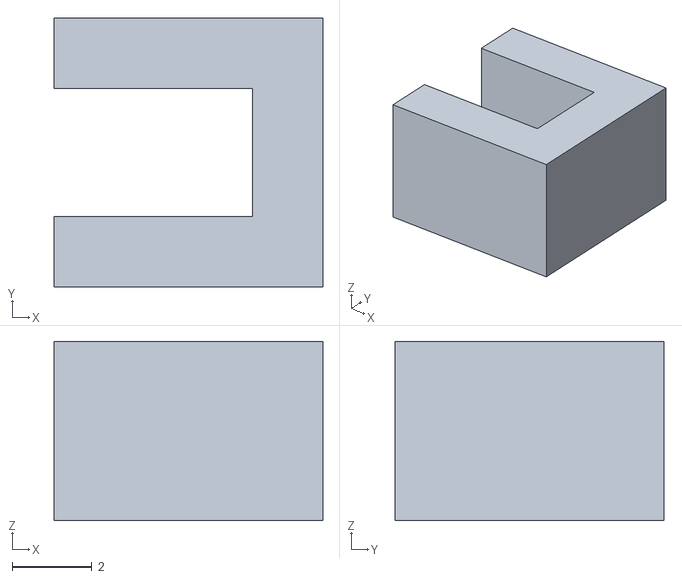
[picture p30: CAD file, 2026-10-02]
cad/STL/seam-lever-M3/spring.stl
6.75 x 6.75 x 4.50

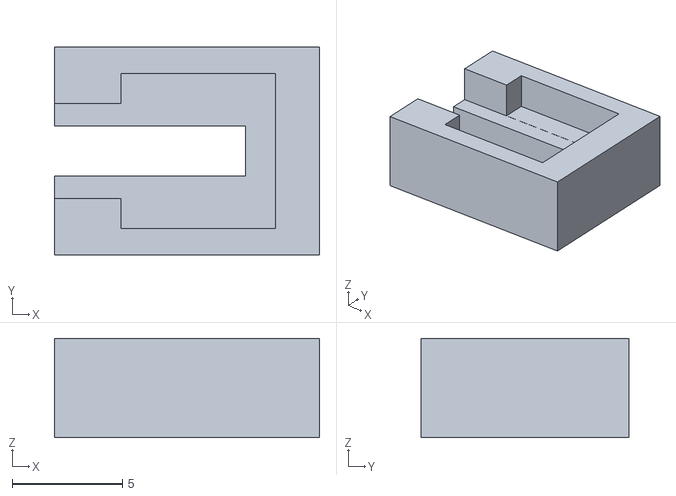
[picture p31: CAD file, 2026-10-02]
cad/STL/seam-lever-M4/keeper.stl
12.0 x 9.40 x 4.50

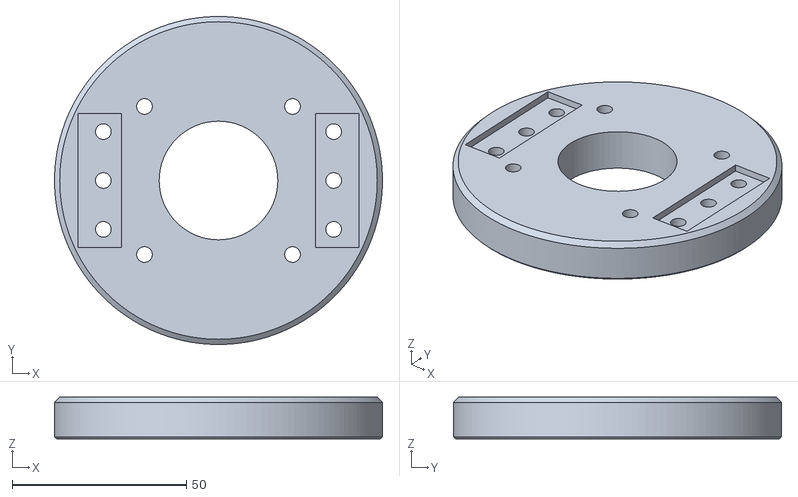
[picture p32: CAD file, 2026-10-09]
cad/STL/simple-cradle-dual.stl
94.0 x 94.0 x 12.0

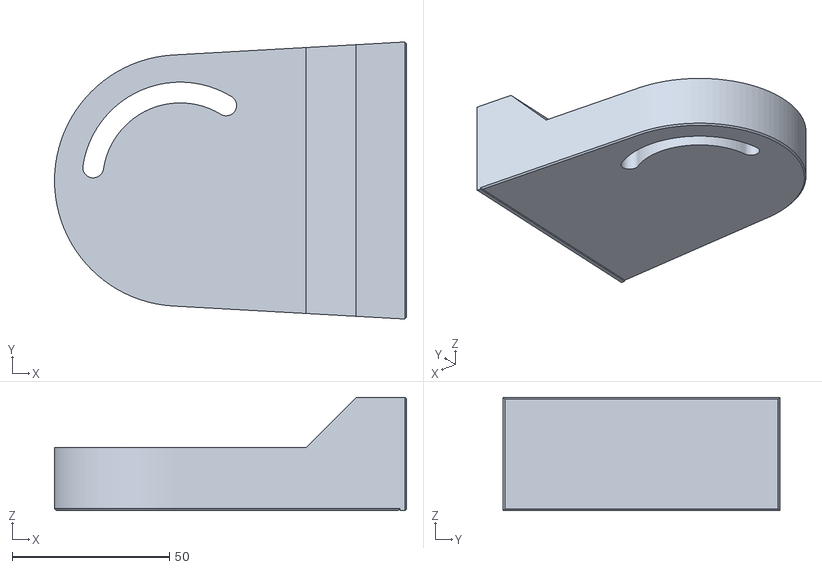
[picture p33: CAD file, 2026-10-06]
cad/STL/blank/simple-upright-arc.stl
112.0 x 88.0 x 36.0

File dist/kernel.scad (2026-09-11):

// PETAL parametric geometry kernel, version 3.0
// Units: millimetres. Front surface z = r*r / (4*f).
// Custom center interface: 120 mm OD, 30 mm center bore, four M4
// clearance windows on a 60 mm keyed / 40 mm legacy bolt circle. Custom interface.
// Square polar clearance windows accept M4 hardware; use washers.
// Front stays parabolic. Optional two-plane rear includes matched fittings.
// Angled panels can include separate breakaway ribs in the same STL.
// F6 Render, then File > Export > STL. Select one part for printing.
// assembly is for inspection only. Recheck fit after editing parameters.

assert(diameter>=180&&diameter<=1200&&fd>=.25&&fd<=.8,"Dish dimensions out of supported range.");
assert(thickness>=1.6&&thickness<=6&&resolution>=2&&resolution<=10,"Thickness or mesh spacing out of range.");
assert(sectors==0||(sectors>=6&&sectors<=32&&sectors%2==0),"Use automatic or 6-32 even petals.");
assert(rear_style==0||rear_style==1,"Choose curved or two-facet rear.");
assert(facet_angle>=10&&facet_angle<=15,"Rear fold angle must be 10-15 degrees.");
assert(!(rear_style&&print_angle==0),"Faceted petals use diagonal printing.");
assert(rows>=0&&rows<=12&&floor(rows)==rows,"Use 0-12 whole rings.");
function zz(r)=r*r/(4*diameter*fd);
function seq(a,b,n)=[for(i=[0:n])a+(b-a)*i/n];
// Range-bisect numeric sort avoids deep recursion on repeated mesh indices.
function qsort(a)=len(a)<2?a:let(lo=min(a),hi=max(a),mid=(lo+hi)/2,p=mid<hi?mid:lo)lo==hi?[lo]:concat(qsort([for(x=a)if(x<=p)x]),qsort([for(x=a)if(x>p)x]));
function hh(r,a,w=4.6)=[r-w/2,r+w/2,a-w/(2*r)*180/PI,a+w/(2*r)*180/PI,r,a,w,1,0];
function nh(h)=let(af=7+2*joint_clearance,w=af/cos(30))[h[4]-w/2,h[4]+w/2,h[5]-w/(2*h[4])*180/PI,h[5]+w/(2*h[4])*180/PI,h[4],h[5],w,2,af];
function bcuts(h,axis)=len(h)>7?[for(t=[-1,-.75,-1/sqrt(3),-.25,0,.25,1/sqrt(3),.75,1])axis==0?h[4]+t*h[6]/2:h[5]+t*h[6]/(2*h[4])*180/PI]:axis==0?[h[0],h[1]]:[h[2],h[3]];
function sameb(a,b)=len(a)>7&&len(b)>7&&abs(a[4]-b[4])<.000001&&abs(a[5]-b[5])<.000001;
function bgroups(bs)=[for(i=[0:len(bs)-1])if(len(bs[i])>7&&len([for(j=[0:1:i-1])if(sameb(bs[j],bs[i]))1])==0)let(g=[for(b=bs)if(sameb(b,bs[i]))b],ws=qsort([for(b=g)b[6]]))[for(w=ws)[for(b=g)if(abs(b[6]-w)<.000001)b][0]]];
function bpoint(h,a)=let(rad=h[7]==2?h[8]/2/max([for(i=[0:5])cos(a-i*60)]):h[6]/2)[rad*cos(a),rad*sin(a)];
function bwarp(x,y,gs)=let(r=sqrt(x*x+y*y),a=atan2(y,x),matches=[for(g=gs)let(h=g[0],da=atan2(sin(a-h[5]),cos(a-h[5]))*PI/180,u=r-h[4],v=h[4]*da,q=max(abs(u),abs(v)),limit=g[len(g)-1][6]/2*1.15)if(q<limit&&q>.0000000001)[g,u,v,q,limit]])len(matches)==0?[x,y]:let(m=matches[0],g=m[0],h=g[0],q=m[3],angle=atan2(m[2],m[1]),hits=[for(i=[0:len(g)-1])if(q<=g[i][6]/2)i],idx=len(hits)?hits[0]:len(g),p0=idx==0?[0,0]:bpoint(g[idx-1],angle),q0=idx==0?0:g[idx-1][6]/2,p1=idx==len(g)?[cos(h[5])*(x-h[4]*cos(h[5]))+sin(h[5])*(y-h[4]*sin(h[5])),-sin(h[5])*(x-h[4]*cos(h[5]))+cos(h[5])*(y-h[4]*sin(h[5]))]:bpoint(g[idx],angle),q1=idx==len(g)?m[4]:g[idx][6]/2,t=(q-q0)/(q1-q0),P=p0+(p1-p0)*t)[h[4]*cos(h[5])+P[0]*cos(h[5])-P[1]*sin(h[5]),h[4]*sin(h[5])+P[0]*sin(h[5])+P[1]*cos(h[5])];
function clamp_depth()=4.4+zz(56.7)-zz(48.3);
function legacy_tilespec(n,k,j)=let(w=(diameter/2-45)/k,b0=45+j*w,b1=45+(j+1)*w,rm=b0+w*.65,h=180/n)
 [b0+(j>0?gap/2:0),b1-(j<k-1?gap/2:0),-h+gap/(2*b0)*180/PI,h-gap/(2*b0)*180/PI,
 concat([hh(rm,-h+8/rm*180/PI),hh(rm,h-8/rm*180/PI)],j==0?[hh(52.5,0)]:[for(a=radial_angles(n,k,j-1))hh(b0+8,a)],j<k-1?[for(a=radial_angles(n,k,j))hh(b1-8,a)]:[]),0,thickness,rear_style?1:0,n,k,j];
function tilespec(n,k,j)=joint_style?jpanel(n,k,j):legacy_tilespec(n,k,j);
function smode(s)=len(s)>7?s[7]:0;
function fdata(s)=let(f=diameter*fd,xc=(s[0]+s[1])/2,base=atan(xc/(2*f)),ms=[tan(base-facet_angle/2),tan(base+facet_angle/2)],mins=[for(m=ms)let(q=m>=0?1:cos(s[3]),r=max(s[0],min(s[1],2*f*m*q)))r*r/(4*f)-m*(r*q-xc)])[min(mins)-thickness,xc,ms[0],ms[1]];
function fz(x,d)=d[0]+max(d[2]*(x-d[1]),d[3]*(x-d[1]));
function roof(s,x,y)=let(mode=smode(s),r=sqrt(x*x+y*y))mode==2?let(d=fdata(tilespec(s[8],s[9],s[10])),h=180/s[8])fz(cos(h)*x+sin(h)*abs(y),d)-.2:
 mode==3?let(w=(diameter/2-45)/s[9],rb=45+(s[10]+1)*w,d1=fdata(tilespec(s[8],s[9],s[10])),d2=fdata(tilespec(s[8],s[9],s[10]+1)),u=max(0,min(1,(r-(rb-gap/2))/gap)))(1-u)*fz(cos(jalpha(s))*x-sin(jalpha(s))*y,d1)+u*fz(cos(jbeta(s))*x-sin(jbeta(s))*y,d2)-.2:
 mode==4?let(d=fdata(tilespec(s[8],s[9],0)),xx=max([for(i=[0:s[8]-1])cos(i*360/s[8])*x+sin(i*360/s[8])*y]))fz(xx,d)-.2:zz(r)+s[5];
function creases(s)=let(mode=smode(s))mode==1?[[1,0,fdata(s)[1]]]:mode==2?let(d=fdata(tilespec(s[8],s[9],s[10])),h=180/s[8])[[0,1,0],[cos(h),sin(h),d[1]],[cos(h),-sin(h),d[1]]]:mode==3?[[cos(jalpha(s)),-sin(jalpha(s)),fdata(tilespec(s[8],s[9],s[10]))[1]],[cos(jbeta(s)),-sin(jbeta(s)),fdata(tilespec(s[8],s[9],s[10]+1))[1]]]:mode==4?[for(i=[0:s[8]/2-1])let(a=(i+.5)*360/s[8])[-sin(a),cos(a),0]]:[];
function orient(v,t)=[cos(t)*v[0]+sin(t)*v[2],v[1],-sin(t)*v[0]+cos(t)*v[2]];
function yawpoint(v,a)=[cos(a)*v[0]-sin(a)*v[1],sin(a)*v[0]+cos(a)*v[1],v[2]];
function envelope(s,t,a)=let(vs=[for(r=seq(s[0],s[1],16),ang=seq(s[2],s[3],24),l=[0,1])yawpoint(orient([r*cos(ang),r*sin(ang),(l?(smode(s)==5?jrear(s,r*cos(ang),r*sin(ang))-(s[10]==0?2:0):(rear_style?fz(r*cos(ang),fdata(s)):zz(r)-thickness)):zz(r))],t),a)])
 [for(k=[0:2])max([for(v=vs)v[k]])-min([for(v=vs)v[k]])+(supports?(k==2?5.6:8):0)];
function fits(d)=((d[0]<=bed_x-2*margin&&d[1]<=bed_y-2*margin)||(d[1]<=bed_x-2*margin&&d[0]<=bed_y-2*margin))&&d[2]<=bed_z-2;
function exactfit(d)=d[0]<=bed_x-2*margin&&d[1]<=bed_y-2*margin&&d[2]<=bed_z-2;
function anglechoice(s,angle)=let(t=atan((s[0]+s[1])/(4*diameter*fd))-angle,choices=[for(a=angle==0?[0,90]:[0:15:90])let(d=envelope(s,t,a))if(exactfit(d))[d[0]*d[1]+a*.001,angle,a,t]])len(choices)==0?[]:[for(c=choices)if(c[0]==min([for(v=choices)v[0]]))c][0];
function pickprint(s,i=0)=let(angles=print_angle==-1?((supports||rear_style||joint_style)?[60,55,50,45,65]:[0]):[print_angle])i>=len(angles)?[]:let(c=anglechoice(s,angles[i]))len(c)>0?c:pickprint(s,i+1);
function valid(n,k)=(diameter/2-45)/k>=40&&(!joint_style||jfit(n,k))&&min([for(j=[0:k-1])len(pickprint(tilespec(n,k,j)))>0?1:0])==1;
assert(supports==0||supports==1,"Supports must be 0 or 1.");
assert(print_angle==-1||print_angle==0||(print_angle>=45&&print_angle<=70),"Use auto, low profile, or 45-70 degrees.");
assert(!(supports&&print_angle==0),"Ribs require an angled panel.");
assert(rib_count>=2&&rib_count<=5&&floor(rib_count)==rib_count,"Use 2-5 whole ribs.");
assert(contact_gap>=.1&&contact_gap<=.4&&contact_width>=.4&&contact_width<=.8&&rib_pitch>=6&&rib_pitch<=20,"Support settings out of range.");
candidates=[for(k=rows==0?[1:12]:[rows],n=sectors==0?[6:2:32]:[sectors])if(valid(n,k))[n*k+k*.15+n*.001,n,k]];
assert(len(candidates)>0,"No segmentation fits. Change bed or dish settings.");
assert(fits([120,120,18]),"Center clamp does not fit bed.");
choice=[for(c=candidates)if(c[0]==min([for(t=candidates)t[0]]))c][0];
N=choice[1]; K=choice[2]; W=(diameter/2-45)/K;
echo(petals=N,rings=K,depth=diameter/(16*fd),focus=diameter*fd);
function extra_r(s)=smode(s)==3?let(r=(s[0]+s[1])/2)[r-gap/2,r,r+gap/2]:[];
function rr(s)=qsort(concat(extra_r(s),seq(s[0],s[1],max(1,ceil((s[1]-s[0])/resolution))),[for(h=s[4],r=bcuts(h,0))if(r>s[0]&&r<s[1])r]));
function aa(s)=qsort(concat(seq(s[2],s[3],max(2,ceil((s[3]-s[2])*PI/180*s[1]/resolution))),[for(h=s[4],a=bcuts(h,1))if(a>s[2]&&a<s[3])a]));
function inside(r,a,hs)=len([for(h=hs)if(r>h[0]&&r<h[1]&&a>h[2]&&a<h[3])1])>0;
function on(i,j,R,A,hs,full)=let(jj=full?(j+len(A)-1)%(len(A)-1):j)i>=0&&i<len(R)-1&&jj>=0&&jj<len(A)-1?!inside((R[i]+R[i+1])/2,(A[jj]+A[jj+1])/2,hs):false;
function vid(i,j,l,nr,nc)=l*nr*nc+i*nc+j%nc;
function verts(s)=let(R=rr(s),A=aa(s),full=abs(s[3]-s[2]-360)<.00001,nc=len(A)-(full?1:0),gs=bgroups(s[4]))
 [for(l=[0:1],r=R,j=[0:nc-1])concat(bwarp(r*cos(A[j]),r*sin(A[j]),gs),[l])];
function faces(s)=let(R=rr(s),A=aa(s),nr=len(R),full=abs(s[3]-s[2]-360)<.00001,nc=len(A)-(full?1:0),off=nr*nc)
 [for(i=[0:nr-2],j=[0:len(A)-2])if(on(i,j,R,A,s[4],full))let(q=[vid(i,j,0,nr,nc),vid(i+1,j,0,nr,nc),vid(i+1,j+1,0,nr,nc),vid(i,j+1,0,nr,nc)],b=[for(x=q)x+off])each concat(
 [[q[0],q[1],q[2]],[q[0],q[2],q[3]],[b[2],b[1],b[0]],[b[3],b[2],b[0]]],
 [for(e=[[0,1,i,j-1],[1,2,i+1,j],[2,3,i,j+1],[3,0,i-1,j]])if(!on(e[2],e[3],R,A,s[4],full))each [[q[e[0]],b[e[0]],b[e[1]]],[q[e[0]],b[e[1]],q[e[1]]]]] )];
// Edge-indexed triangle splitting preserves watertight crease topology.
function crossing(a,b)=(a>1e-6&&b< -1e-6)||(a< -1e-6&&b>1e-6);
function ekey(u,v,n)=min(u,v)*n+max(u,v);
function bfind(a,x,lo=0,hi=undef)=let(h=is_undef(hi)?len(a)-1:hi,m=floor((lo+h)/2))lo>h?-1:a[m]==x?m:a[m]<x?bfind(a,x,m+1,h):bfind(a,x,lo,m-1);
function clipface(f,d,sgn,keys,n)=[for(j=[0:2])let(u=f[j],v=f[(j+1)%3])each concat(sgn*d[u]>=-1e-6?[u]:[],crossing(d[u],d[v])?[n+bfind(keys,ekey(u,v,n))]:[])];
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

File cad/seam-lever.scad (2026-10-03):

// PETAL seam lever: a quick-release cam clamp for clip/lever seam stations. Millimeters.
// No screws. Three printed parts plus a printed TPU spring (or a small metal spring in the same pocket):
//   lever   - two cheeks with the cam profile, joined by the handle; an open slot takes the bar's cross pin
//   bar     - draw bar: cross pin (lever side), octagon shaft through both flange holes, neck + button (far side)
//   keeper  - slides up onto the neck from behind the dish, holds the spring against the far flange
//   spring  - TPU block in the keeper pocket (or swap in disc/coil springs)
// Install: bar through both holes from the lever side, keeper (with spring) up onto the neck from the rear,
// push the lever's open slot up onto the cross pin with the handle sticking straight out, then flip the handle
// down along the flange; it snaps over-center onto its flat. Release: flip the handle out, drop the lever off
// the pin, slide the keeper down.
//
// Station geometry comes from the PETAL generator (seam joint = "Both", where every station has the bolt
// hole and the clip window): 5 mm flat walls, guide ridges 10.8 mm apart, bore 2.2 mm below station level.
// World frame: X across the seam (seam plane X = 0, lever on +X), Y toward the shell (Y = 0 at the station
// level), Z along the seam.

part = "assembly";  // [assembly,lever,bar,keeper,spring,plate,installed_lever,installed_bar,installed_keeper,installed_spring]
closed = true;      // assembly view: handle down (clamped) or up (open)
$fn = 48;

// ---------- from the PETAL designer (Both mode) ----------
wall      = 5;      // each flange wall at a station (CLIP.wall)
hole_d    = 3.4;    // seam bore: 3.4 = M3 as generated; 4.5 = M4
hole_y    = -2.2;   // boltY() in Both mode
ridge_gap = 10.8;   // clear width between the two guide ridges (2 x (CLIP.width/2 + CLIP.clear))
shell_y   = 6.75;   // nothing may rise above this (CLIP.top)

// ---------- tuning ----------
hole_clr  = 0.25;   // bar corner-to-hole diametral clearance
stroke    = 1.2;    // net draw from handle-up to handle-down
hump      = 0.3;    // over-center: how far the cam lifts before it drops onto its flat
pre       = 0.3;    // spring preload with the handle up (keeps the keeper seated)
spring_t  = 4.5;    // free spring thickness (TPU: ~40% max squeeze at stroke + hump + pre)
pocket    = 7;      // square spring pocket in the keeper
pocket_d  = 2;      // pocket depth
lever_w   = 10;     // lever width, sits between the ridges
handle_l  = 30;     // handle length below the pivot
handle_t  = 3.5;    // handle thickness at the tip

// ---------- derived ----------
p    = floor((hole_d - hole_clr) * cos(22.5) * 10) / 10;   // bar section: octagon across flats
n    = 0.5 * p;                                            // neck width (balances neck vs shoulder area)
gap  = p + 0.6;                                            // central slot between the lever cheeks
rb   = p / 2 / cos(22.5) + 0.2;                            // pin slot half width
h_open = max(5, rb + 3);                                   // cam radius toward the wall, handle up
hf   = h_open + stroke;                                    // pivot-to-flat, handle down
rc   = hf + hump;                                          // peak radius at the flat's corner
yc   = sqrt(rc * rc - hf * hf);                            // corner height above the pivot
th_c = atan2(yc, -hf);                                     // corner angle
floor_t = 2.5;                                             // keeper floor (fork) thickness
button  = 3;
x_pf = -wall - (spring_t - pre);   // pocket floor, handle up
x_k  = x_pf - floor_t;             // keeper back face = button shoulder, handle up
pin_x = wall + h_open;             // pivot, handle up
kw = min(ridge_gap - 1.4, pocket + 2.4);
kb = 6.5; kt = pocket / 2 + 2;

echo(str("bar octagon ", p, " mm, neck ", n, " mm, pin slot ", 2 * rb, " mm, cheeks ", (lever_w - gap) / 2, " mm"));
echo(str("cam radius to the wall: open ", h_open, ", clamped flat ", hf, ", over-center peak ", rc));

echo(MOTION = [h_open, hf, rc, stroke, hole_y, wall]);

// ---------- helpers ----------
module oct(d) rotate(22.5) circle(d = d / cos(22.5), $fn = 8);   // octagon, across flats d
// lever profile in the lever frame: pivot at origin, handle down, x away from the wall, y toward the shell
function spiral() = [for (i = [0:24]) let(t = 90 + (th_c - 90) * i / 24, r = h_open + (rc - h_open) * i / 24) [r * cos(t), r * sin(t)]];
function lever_pts() = concat(
  [[-hf, -handle_l], [-hf + handle_t, -handle_l]],
  [for (t = [-40:10:80]) [h_open * cos(t), h_open * sin(t)]],
  spiral(),
  [[-hf, yc]]);
module lever_profile() intersection() {
  polygon(lever_pts());
  // The open cam must not protrude beyond h_open toward the flange.
  // The radial spiral briefly exceeds this tangent otherwise (about 0.13 mm).
  translate([-60, -60]) square([120, 60 + h_open]);
  // 45° print chamfer up from the flat's corner (the flat is the bed face)
  polygon([[-hf, yc], [40, yc + 40 + hf], [40, -60], [-hf, -60]]);
}

// ---------- parts (each modeled in its own working frame) ----------
module lever() difference() {
  translate([0, 0, -lever_w / 2]) linear_extrude(lever_w) lever_profile();
  // central slot for the bar: everything above the handle root, down through the flat
  translate([-50, -p / 2 - 0.5, -gap / 2]) cube([100, 50, gap]);
  // open pin slot through both cheeks, opening away from the wall
  translate([0, 0, -lever_w]) linear_extrude(2 * lever_w) { circle(r = rb); translate([0, -rb]) square([20, 2 * rb]); }
}

module bar() {   // world frame, handle up
  // cross pin
  translate([pin_x, hole_y, -(lever_w - 0.4) / 2]) linear_extrude(lever_w - 0.4) oct(p);
  // shaft from the pin to the neck
  translate([x_pf + 0.4, hole_y, 0]) rotate([0, 90, 0]) linear_extrude(pin_x - x_pf - 0.4) rotate(90) oct(p);
  // neck
  intersection() {
    translate([x_k - 0.01, hole_y, 0]) rotate([0, 90, 0]) linear_extrude(x_pf + 0.42 - x_k) rotate(90) oct(p);
    translate([x_k - 1, hole_y - p, -n / 2]) cube([floor_t + 2, 2 * p, n]);
  }
  // button
  translate([x_k - button, hole_y, 0]) rotate([0, 90, 0]) linear_extrude(button) rotate(90) oct(p);
}

module keeper() difference() {   // world frame, handle up
  translate([x_k, hole_y - kb, -kw / 2]) cube([x_pf + pocket_d - x_k, kb + kt, kw]);
  translate([x_pf, hole_y - pocket / 2, -pocket / 2]) cube([10, pocket, pocket]);                        // spring pocket
  translate([x_pf - 0.01, hole_y - kb - 1, -(p + 0.4) / 2]) cube([10, kb + 1 + p / 2 + 0.2, p + 0.4]);  // bar clearance
  translate([x_k - 1, hole_y - kb - 1, -(n + 0.3) / 2]) cube([floor_t + 2, kb + 1 + p / 2 + 0.2, n + 0.3]); // neck fork
}

module spring() difference() {   // world frame, free length, seated in the pocket
  translate([x_pf, hole_y - (pocket - 0.25) / 2, -(pocket - 0.25) / 2]) cube([spring_t, pocket - 0.25, pocket - 0.25]);
  translate([x_pf - 1, hole_y - pocket, -(p + 0.3) / 2]) cube([spring_t + 2, pocket + p / 2 + 0.15, p + 0.3]);
}

// ---------- station mock-up for the assembly view ----------
module station() color("lightgray") difference() {
  union() {
    translate([-wall, -9, -20]) cube([2 * wall, shell_y + 9 + 0.25, 40]);
    translate([-30, shell_y + 0.25, -20]) cube([60, 2.4, 40]);   // shell
    for (s = [-1, 1], k = [-1, 1]) translate([s > 0 ? wall : -wall - 1, -9, k > 0 ? ridge_gap / 2 : -ridge_gap / 2 - 1]) cube([1, shell_y + 9, 1]);
  }
  translate([-20, hole_y, 0]) rotate([0, 90, 0]) cylinder(d = hole_d, h = 40);
}

// ---------- print orientations ----------
// lever: flat face (x = -hf) on the bed, cheeks side by side; lever y -> X, z -> Y, x -> Z
module print_lever()  multmatrix([[0, 1, 0, 0], [0, 0, 1, 0], [1, 0, 0, hf], [0, 0, 0, 1]]) lever();
// bar: world Y up, everything flat on the bed; keeper: back face down, pocket up; spring: squeeze axis up
module print_bar()    translate([0, 0, p / 2 - hole_y]) rotate([90, 0, 0]) bar();
module print_keeper() multmatrix([[0, 1, 0, -hole_y], [0, 0, 1, 0], [1, 0, 0, -x_k], [0, 0, 0, 1]]) keeper();
module print_spring() multmatrix([[0, 1, 0, -hole_y], [0, 0, 1, 0], [1, 0, 0, -x_pf], [0, 0, 0, 1]]) spring();

module lever_world(c) translate([wall + (c ? hf : h_open), hole_y, 0]) rotate([0, 0, c ? 0 : 90]) lever();

// installed poses in the station frame (no mock station); the PETAL generator bundles these for its assembly view
module installed_lever()  lever_world(closed);
module installed_bar()    translate([closed ? stroke : 0, 0, 0]) bar();
module installed_keeper() translate([closed ? stroke : 0, 0, 0]) keeper();
module installed_spring() { s = closed ? stroke : 0; translate([s + x_pf, 0, 0]) scale([(spring_t - pre - s) / spring_t, 1, 1]) translate([-x_pf, 0, 0]) spring(); }
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

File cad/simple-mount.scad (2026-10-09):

// PETAL simple alt-az mount. Millimeters. One clamp per axis; the two arms are bolted on with heat-set inserts.
//   base    - flat disc on your stand; captures the azimuth nut, carries the azimuth scale on its rim (optional)
//   yoke    - turntable plate on the base (azimuth); without the base it screws straight onto the stand
//   upright - elevation arm; socket heads (joint_m) come up through the yoke plate into its inserts
//   cradle  - hub plate (Ø94 × 12, Ø34 port, 4 × hub_m on a 60 mm circle)
//   cheek   - elevation arm on the cradle; socket heads (joint_m) from the hub face go into its inserts
// Each axis: two flat faces, one clamp_m bolt. Azimuth: hex key from above. Elevation: one wing nut,
// plus an optional M6 bolt in an arc slot (arc_lock).
// Every part prints without supports in its export orientation (printing = true):
//   base   top face down            yoke   bottom (bearing) face down
//   upright clamp face (x = 40) down  cradle hub face down    cheek clamp face (x = 40) down
// Frame: Z up, +Y = boresight at az 0 / el 0, elevation axis along X. Base bottom at Z 0.

part = "assembly";  // [assembly,base,yoke,upright,cradle,cheek,upright_left,cheek_left,matrices]
printing = false;
arc_lock = false;     // M6 arc-slot lock bolt: slot in the upright, hole + head pocket in the cheek
// Elevation clamp side, seen from behind the dish: "right"; "left", the mirror image (with right-hand threads a slip
// that lets the dish nod down turns the captive bolt the way that tightens its wing nut); "both", a U with an upright
// and a cheek on each side, two clamps. Heads stay captive inside the cheeks and the wing nuts outside. The arc lock
// sits on the right in "both" (part = "upright_left" / "cheek_left" give the mirrored arms).
sides = "right";      // [right, left, both]
stand_holes = false;  // no base: 4 counterbored stand_m holes from the top of the yoke plate; assembly omits the base
base_screws = true;   // base: 4 counterbored stand_m holes to a stand. The app's tripod base turns them off and adds leg sockets
fasteners = true;     // false: every bolt hole, insert pilot and nut or head pocket left out. The app bundles these blanks
                      // and cuts the holes for the selected sizes itself (dist/mount-fasteners.js mirrors the cuts below)
head_pockets = true;  // false: plain holes in the cheek; the elevation (and arc lock) bolt heads sit on its inner face with a washer
nut_pocket = true;    // false: plain azimuth hole in the base; the nut and a washer sit under the base
stand_counterbore = true;   // false (no base): plain stand holes in the yoke plate; socket heads and washers on its top
// Fastener sizes (metric): joint socket heads into inserts, the two clamp bolts, stand screws, hub-to-mount bolts
joint_m = 4;   // [3,4,5]
clamp_m = 8;   // [6,8,10]
stand_m = 5;   // [4,5,6]
hub_m = 4;     // [3,4,5]
dish_d = 400; dish_fd = 0.42;
el = 30; az = 0; show_dish = true;
$fn = 96;
hfn = 32;               // small holes; a multiple of 8 so teardrop roofs meet the circle on a vertex
efoot = 0.6;            // first-layer chamfer
chamf = 1.5;            // top-edge chamfer on plates
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

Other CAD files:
cad/STL/seam-lever-M3/lever.stl
cad/STL/simple-yoke-dual.stl
cad/STL/blank/simple-cheek.stl
cad/STL/seam-lever-M3/keeper.stl
cad/STL/blank/simple-base.stl
cad/STL/blank/simple-cradle.stl
cad/STL/blank/simple-upright.stl
cad/STL/blank/simple-yoke.stl
cad/STL/seam-lever-M4/spring.stl
cad/STL/simple-base.stl
cad/STL/simple-cheek-arc.stl
cad/STL/simple-cheek-left.stl
cad/STL/simple-cradle.stl
cad/STL/simple-upright-arc.stl
cad/STL/simple-upright.stl
cad/STL/simple-yoke-stand.stl
cad/STL/simple-yoke.stl

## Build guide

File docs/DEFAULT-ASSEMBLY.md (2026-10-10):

# PETAL 5.3 — print and assembly

## New interface · print a test first

PETAL uses integral flanges and one rear hub, interface revision 12. Do not mix older petals, saddles, caps or hubs with this kit. The first article is a geometric prototype, not a validated antenna or outdoor load-bearing structure. Start with two copies of FIT_TEST/seam-strip-print-two.stl in their exported orientations. These are sections of the real petal, including both flange edges and a fastening station. They intentionally retain the petal width so the upper flange prints in the same orientation as the full part. They do not test full-length warping or the hub.

## Materials and side printing

Use dry PETG for an indoor fit article; use ASA for outdoor trials only with a controlled enclosure and a verified material profile. For long ASA, ASA-CF or ASA-GF petals run the chamber at the top of its range (50–65 °C) with a low part fan, dry the filament first, and print one of the longest petals alone before full plates (docs/PRINTING-LARGE-PETALS.md). PLA can establish fit but is a poor choice for a warm, sunlit dish. Start with a 0.4 mm nozzle, 0.2 mm layers and at least four perimeters; preview thin walls and use locally solid flange pads and root bosses. Exported petals stand on their flat radial flange; the curved underside is sideways. A full-depth upper-flange gusset, ramped inner end and bed-connected root boss reduce broad unsupported projections. The underside is a smooth curved shell by default; optional small tangent-plane facets add material without changing the RF face. Each outer petal has a band behind its rim, square to the dish: a 14 mm wall whose foot bends 45° toward the hub, standing 1 mm above the reflecting face. In the side print every layer ends in it instead of a free edge, so the tall rim edge does not flex when the nozzle turns there, and its end adds bed contact. Assembled, the bands form one frame around the dish. Each outer petal prints with a breakaway rim support in the same file: a solid 2.5 mm wall with 2 ribs square to it standing 0.3 mm in front of the rim's front edge, joined to it by 44 tines (0.3 mm tall, 0.6 mm wide at the rim, at most 4 mm apart). It holds the tall rim edge still when the nozzle turns there. Let the petal cool on the bed, then twist the wall away from the rim starting at the top; the tines break at the rim. Trim any nub flush with a sharp blade. It adds about 29.8 cm³ per petal and is not part of the dish. Add a 3–6 mm brim for full petals and check adhesion. Packed copies keep 6 mm apart at every height, so side-printed petals that lean the same way nest closely; at the bed the gap is also 6 mm, so brims wider than 3 mm merge with their neighbors. Tall ASA petals hold better with a wider brim: raise the gap between parts in Print, or let the brims merge. Avoid sequential-by-object printing unless the slicer confirms toolhead clearance. The upper flange, bores and clip recesses still require layer-preview inspection; pointed roofs reduce unsupported spans but are not a universal support-free guarantee. Use localized supports if your slicer/material requires them. Hub prints flat rear down.

## Fit and fasteners

Remove first-layer flare only from mating edges; the mating faces are flat, with no keys. Every seam bolt clamps between two flat Ø10 mm seats square to the bolt, one on each flange; the nut is loose, not captured. Bores are Ø3.4 mm for M3. Test the real M3 hardware on the coupon before printing the whole dish. Petal roots take blind heat-set inserts, so the reflecting face above them stays closed. The M4 hub mount bolts pass fully through, with Ø10 mm seats 5 mm deep in the hub front for the washers and nuts. Insert pockets are Ø5.60 × 7 mm for short M4 inserts, maximum 6 mm long, seated 0.5 mm below the entry. Insert pilot requirements depend on the exact insert and filament: verify the supplier specification and use an insert scrap before installation. Heat-set while supporting the boss, never by loading the RF face. Let it cool fully. The hub front is flat, level with the petals at the hub corners and chamfered down to them along each edge. It stands up to 3.68 mm above the parabola near the center opening, which sits in the feed's shadow; choose Curved if the hub area must follow the parabola.

## Assembly without pulling in warp

If petals are segmented, join each radial strip first using its integral cross-flanges. Then bring complete petals together by sliding radially inward from outside the rim. The flat mating faces meet as the edges approach. Keep all fasteners loose. The final petal also approaches radially; do not try to snap it into a closed ring from the front. Flat pads establish contact; bolts retain. Use a profile jig for repeatable alignment. Place the shape in a measured support jig, check seam steps, then lightly snug opposite seams in several passes. Install the rear hub after the petal ring closes freely. Never use bolts to bend a warped petal until its seam disappears. Reprint or correct the process if faces do not sit flat, pads do not seat or the final petal needs force. Full-length flanges increase stiffness but thermal shrinkage and accumulated print error still require measurement.

## Hardware and access

Use M3 × 16 socket head seam screws with a washer under the head and under the nut. Each nut sits loose on a flat seat; hold it with a 5.5 mm nut driver or wrench and drive the screw from the other side. Work from behind the dish, and verify tool access before fitting rods. M4 × 12 root screws go from the hub rear, with one 1 mm washer, into the petal inserts; nominal 5 mm entry. The external mount keeps the clear 30 mm center hole and has four Ø4.6 mm through bores on a 60 mm bolt circle for M4. Put the heads behind the adapter and the washers and nuts in the Ø10 mm front seats (washers 9 mm OD or less). Select screw length as 19 mm plus the adapter thickness, rounded up. Install front hardware before applying removable foil patches; keep bores and hardware accessible. No qualified torque is specified: snug by hand and stop if plastic compresses, whitening appears, or a seam moves. Recheck after a warm hold; printed plastic creeps.

## RF surface and accuracy

Apply continuous conductive foil or a specified conductive coating; see REFLECTOR.md for preparation and source references. Keep flange seats, detent grooves and bores clean. Align before bridging seams with removable foil strips. The parabola focus is 168.00 mm from the extrapolated vertex, not from the hub back. Frequency does not move that geometric focus. Feed phase-center position, illumination, surface error and pointing determine RF performance. Mesh spacing is a geometric approximation too: reduce it for short wavelengths and measure the final coated dish. No calculated focal point or closed STL establishes measured gain.

## Inspection before a full article

Record seam steps and dish profile before tightening, after tightening, at several elevations, and after thermal settling. A joint that fits a coupon does not prove a full petal will stay true. Check screw bearing on the flat seats, flange-root cracking, seat flatness and tool access on the test parts. Test repeated assembly and mark screws/rods to reveal movement. Wind, water, UV, creep and transport loads are not qualified. Keep a foil-covered dish away from direct sunlight during handling because it can concentrate heat.

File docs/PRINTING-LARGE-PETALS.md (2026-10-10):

# Printing large petals in ASA-GF, ASA-CF and PCTG

This is a plan for getting long petal prints right the first time in expensive filament. It covers what makes these parts warp, the settings that matter most on the Prusa CORE One L and the Bambu Lab H2D and H2C, what changing the shell thickness, walls or infill would do, and the rim band and ribs that stiffen the petal while it prints.

## What is at risk in this part

PETAL petals print standing on one radial flange. On a large dish that makes them tall, narrow parts:

| Dish / printer | Petals | Largest petal | Bed contact | Contact length |
|---|---|---|---|---|
| 400 mm / 220 bed | 6 × 1 | 174 × 70 × 173 mm | 2,060 mm² | 147 mm |
| 600 mm / CORE One L | 6 × 1 | 274 × 102 × 260 mm | 3,510 mm² | 247 mm |
| 1000 mm / H2D | 10 × 2 | 287 × 125 × 294 mm | 3,400 mm² | 235 mm |
| 1200 mm / H2D | 12 × 2 | 290 × 226 × 300 mm | 4,080 mm² | 266 mm |

Three things follow from this shape:

- **The bed strip is narrow.** The contact averages about 15 mm wide and the part stands up to 300 mm tall, a 20 to 1 ratio. Lifting starts at the two ends of the strip.
- **Every layer is one long curved bead.** Each layer is a slice through the petal's profile, 250–300 mm long. Warping grows with the length of continuous material in a layer (Wang 2007), so this part is near the worst case for it.
- **The prints are long.** A tall part spends hours with its first layers cooling under it while new layers shrink on top, and a single lifted corner or knock ends a 10-hour print.

How much a new layer shrinks against the layers below it is roughly its expansion coefficient times the gap between its glass transition and the chamber. For ASA (Tg about 104 °C, 69 µm/m·°C) that is about 0.55% with the chamber at 25 °C and about 0.3% at 60 °C. Over a 266 mm strip that is a pull of 1.5 mm against the bed at room temperature and 0.8 mm in a 60 °C chamber. Glass or carbon fiber cuts the shrinkage along the bead to about a third (measured on CF-ABS, GF-PETG and CF-PA), but not between layers. That is why ASA-CF and ASA-GF are the right materials for the long petals, and why Prusa's CORE One profile compensates ASA-CF by 0% in XY but 0.22% in Z.

## Settings that matter most

Start from the printer maker's profile for the exact filament. These are the values in those profiles today:

| Profile | Chamber | Bed | Nozzle | Part fan |
|---|---|---|---|---|
| CORE One L · ASA | 60 °C (at least 50) | 110 °C | 260 °C | 20–25% |
| CORE One L · ASA-CF | 60 °C (at least 50) | 110 °C | 260 °C | 15–20% |
| CORE One · PCTG | 35 °C | 85 °C | 260 °C | 30–60% |
| H2D / H2C · ASA | 65 °C | 100 °C | 270 °C | 10–35% |
| H2D / H2C · ASA-CF | 60 °C | 90 °C, textured plate | 275 °C | up to 25% |
| H2D / H2C · PCTG | off | 70 °C | 255 °C | 10–40% |

The CORE One L chamber reaches 60 °C and the H2D and H2C 65 °C; some ASA-GF makers ask for more than either can give, so run them at the maximum.

For the long ASA-GF and ASA-CF petals, in order of importance:

1. **Chamber at the top of its range**, and let it reach temperature before the first layer. This is the setting that does the most against warping.
2. **Dry filament.** Bambu ASA-CF: 80 °C for 8 hours. ASA-GF: 70–80 °C for 4–6 hours. PCTG: 65 °C for 4–6 hours. Keep fiber-filled spools below 20% humidity while printing.
3. **A wide brim.** A 10 mm brim raises the contact of a 170 × 10 mm strip from about 1,700 mm² to about 5,600 mm². Bambu Studio's automatic brim grows with a part's height for exactly this reason. In PETAL, set **Gap between parts** (Print tab) to 16–20 mm so 8–10 mm brims do not merge, or accept merged brims and cut the parts apart afterward.
4. **Plate and glue.** Prusa: smooth or satin sheet with glue stick for ASA. Bambu: Engineering, High-Temp or textured PEI with glue, with the plate type in the slicer matching the plate fitted. PCTG sticks too well: use glue as a release layer.
5. **Low fan and moderate speed.** Keep the part fan at or below the profile's value. Slow down and lower the acceleration for tall parts.
6. **Hardened nozzle.** The H2D and H2C come with hardened steel. On the CORE One L fit a hardened or ObXidian nozzle before printing CF or GF.

## Shell thickness, walls and infill

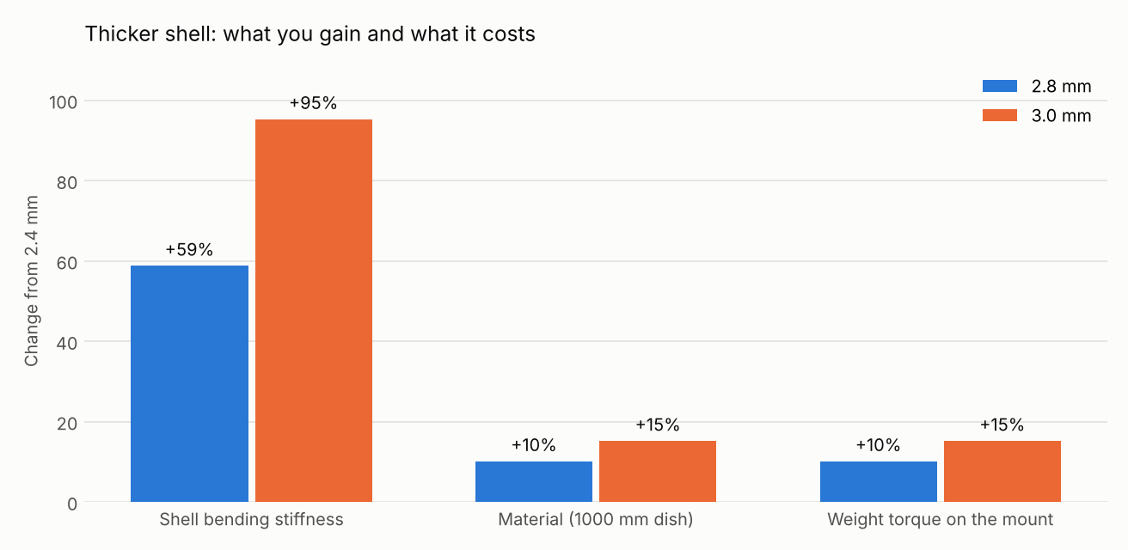
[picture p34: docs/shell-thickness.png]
Change from a 2.4 mm shell to 2.8 and 3.0 mm


| Shell | Bending stiffness | Material, 1000 mm dish | Weight on the mount |
|---|---|---|---|
| 2.4 mm (default) | 1.00 | 3.05 L | 1.00 |
| 2.8 mm | 1.59 | 3.36 L (+10%) | +10% |
| 3.0 mm | 1.95 | 3.51 L (+15%) | +15% |

The plate count does not change at any of these thicknesses.

- **Thickness does little for warping itself.** A thicker shell is stiffer, so it bends less once the part comes off the bed. It also has more material shrinking in each layer, so it pulls harder on the bed strip. On balance the two roughly cancel for bed lift.
- **Where 2.8 mm pays off is stiffness in use.** 2.8 mm is 59% stiffer for 10% more filament and print time, and adds 10% to the weight on the mount. That matters most for the longest petals of a large dish, against wind and handling. 3.0 mm costs another 5% for less additional gain.
- **Make the shell all walls.** With 0.45 mm lines, a 2.4 mm shell is five to six walls and a 2.8 mm shell six to seven. Set enough walls that the slicer preview shows only walls across the shell, with no gap fill or infill inside it.
- **Do not use 100% infill.** Infill only fills the thicker parts: the root boss, the bolt pads and the clip walls. Denser infill raises the residual stress, and Bambu's guidance is to stay under 50%. Use 15–25% gyroid there and more walls instead.

## Rim band and underside ribs

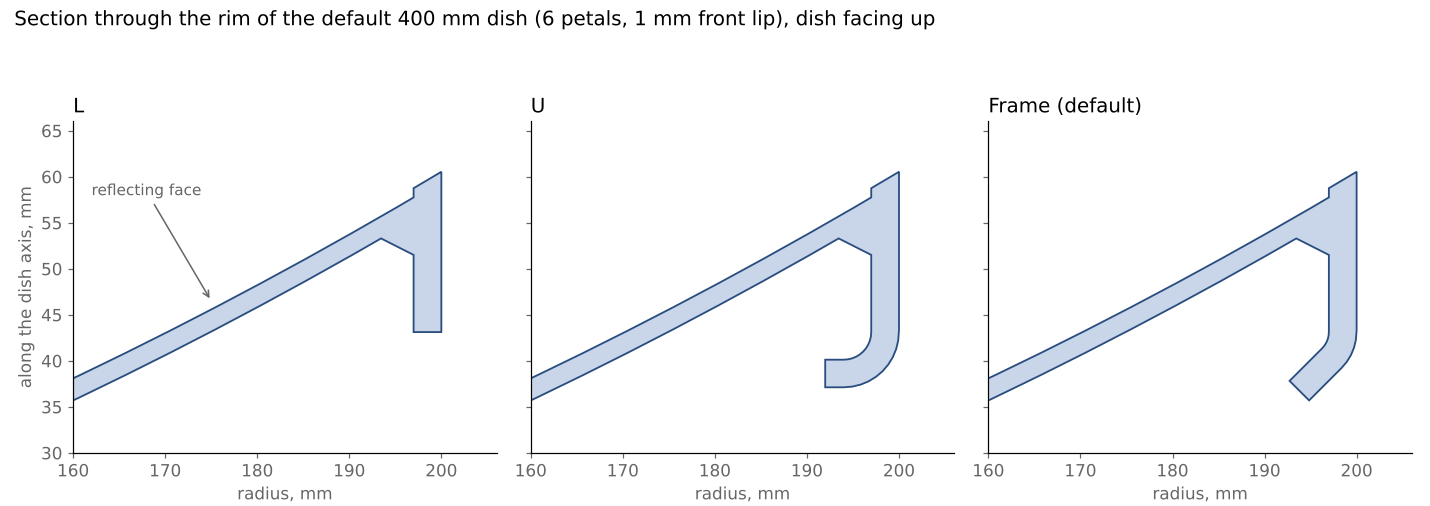
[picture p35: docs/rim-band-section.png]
Section through the rim of the default dish with an L, U and frame band


Every layer of a side-printed petal is one long curve that ends at the rim. That end is a free 2.4 mm edge standing up to 300 mm tall, so it flexes when the nozzle reaches it and turns around, and the layer lands slightly off. **Rim band** (Shape tab) puts a wall behind the rim of each outer petal, square to the dish, so that every layer ends in a hook instead:

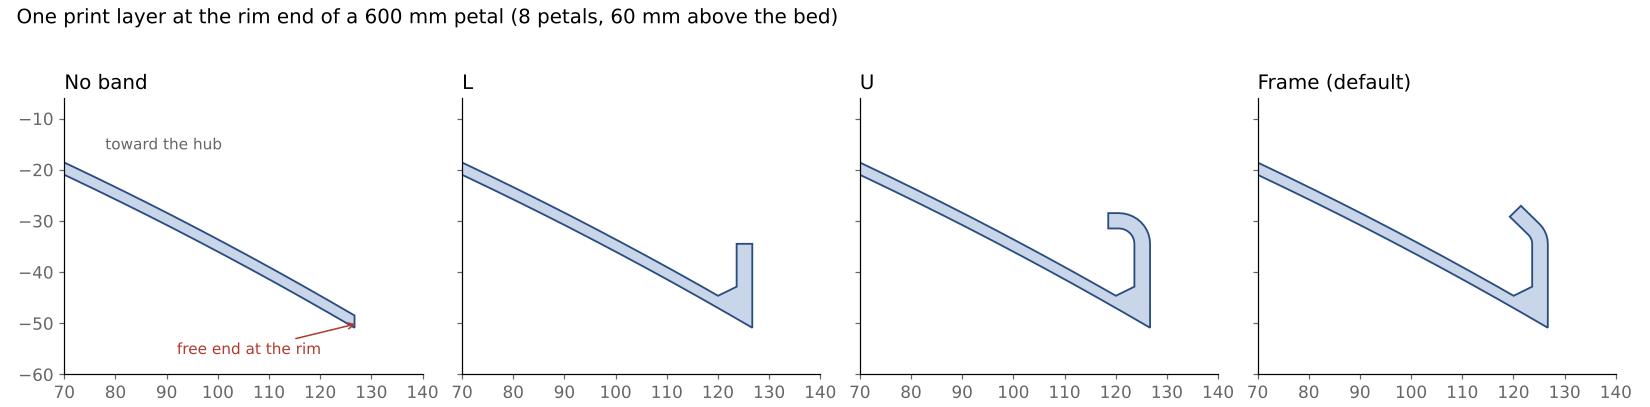
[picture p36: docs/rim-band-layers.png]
One print layer at the rim end of a petal with no band, an L, a U and a frame


| Band | Section | Extra material, 600 mm petal |
|---|---|---|
| None | free edge | — |
| L | 3 mm wall, 14 mm deep, 45° fillet to the shell | +8% |
| U | the wall, then a round 90° bend toward the hub and a 2 mm lip | +12% |
| Frame (default) | the wall, then a round 45° bend toward the hub and a 5 mm lip | +12% |

- The band's end face sits on the bed with the flange, so the bed contact becomes an L at the end of the strip, where lifting starts.
- Assembled, the bands of all the outer petals form one frame around the dish, which also stiffens the rim in use.
- The wall depth is adjustable (6–30 mm); a U or frame foot adds about 6 mm behind it.
- A **front lip** carries the wall on above the reflecting face, 1 mm by default (0–3 mm), so the edge is braced from both sides. Against the frame alone it adds about 5% stiffness at 1 mm and 17% at 3 mm. It covers only the outer 3 mm of the aperture (3% of a 400 mm dish, 1% of a 1000 mm dish), where the feed puts little energy, so the gain cost is under 0.05 dB with a typical feed. It also gives the rim a hard edge and a clean stop for foil or coating. A 3 mm lip can cost nesting room: the default 400 mm dish then needs three 220 mm plates instead of two.
- The wall stays square to the dish with any petal count. With 6 petals its inner face reaches 60° from vertical near the top of the side print (45° with 8 petals, less with more). It is a short face on the hidden inside of a thick wall and prints without support; expect a slightly rougher surface there.
- Seam stations near the rim move toward the hub just far enough to keep their bolts, clips or levers clear of the band. A short seam that would crowd its stations loses one.

**Underside ribs** (Shape tab, off by default):

- **Diamond grid:** low ribs, 2.5 mm tall and 50 mm apart by default, across the underside of every petal, mirrored on each petal so the ribs meet the next petal's at the seams. On a 600 mm, 8-petal dish they add about 8% material.
- **Center ring:** one ring rib, 3 mm tall by default (2–6 mm), half way along each petal (each ring of petals on a larger dish). It stiffens a long petal where it is least supported, about 2.4 times through the shell at 3 mm, and braces each print layer at mid-length.
- **Both** together make a ring-and-diagonal grid. All ribs have 45° sides, so they print without supports in any direction, and they stop short of seam hardware and the rod socket.

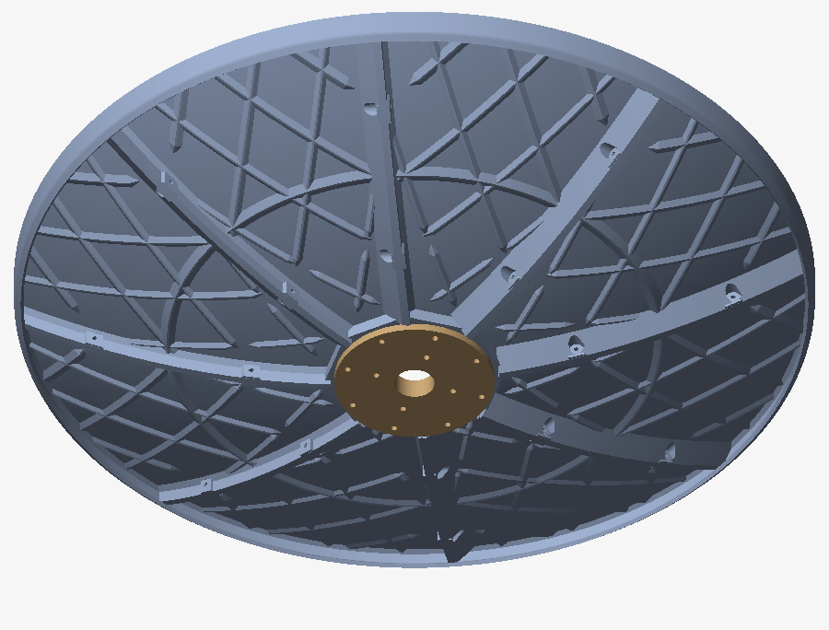
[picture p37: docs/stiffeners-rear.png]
Rear of a 600 mm dish with the frame band, diamond ribs and center ring


## Breakaway rim support

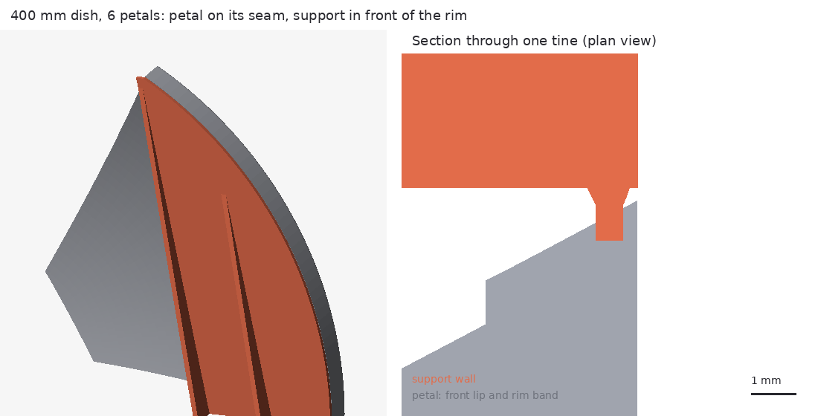
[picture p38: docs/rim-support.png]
A 400 mm petal in print orientation with the rim support in front of its rim, and a section through one tine


The rim band holds each layer's end from behind. **Breakaway rim support** (Print tab, on by default) holds it from the front: a wall printed in front of the rim of each outer petal, joined to the rim's front edge by small tines that snap off. It is in the same STL as the petal and is not part of the dish.

| | Default | Range |
|---|---|---|
| Wall thickness | 2.5 mm | 2–8 mm |
| Inner edge lean | 12° from vertical | 0–30° |
| Ribs square to the wall | 2 | 0–4 |
| Gap to the rim's front edge | 0.3 mm | 0.15–0.8 mm |
| Tine width at the rim | 0.6 mm (1.2 mm at the wall) | 0.4–1.2 mm |
| Tine height | 0.3 mm, one or two layers | fixed |
| Tine spacing | at most 4 mm, from 1 mm above the bed to the top | 2–12 mm |

- The wall is solid and stands on the bed. Its face is vertical, parallel to the rim's front edge, which is at one depth all the way up. Its outer edge follows the rim. Its inner edge runs from the rim's top almost straight down to the bed, so the wall is widest at the bed. Every layer is one solid island, so the nozzle never travels across a window and leaves strings. Nothing on it is steeper than 45°, and each tine is a bridge of about 1 mm.
- **Ribs** stand square to the wall on its outer face, so the wall also resists pushes across its face, not only along it. The first runs along the inner edge, making an L in plan; the others spread across the foot. Each is a thin triangle, deepest at the bed (12% of its height, 6–16 mm) and running back into the wall at its top.
- Each tine narrows from 1.2 mm at the wall to the tine width where it meets the rim, 0.25 mm in from the rim's outer edge. With ASA-CF and ASA-GF the fibers lie along each bead, so a bead is strong along its length; the narrow neck makes the break happen at the rim instead of pulling material out of the lip.
- The numbers follow published designed-in supports: a 0.2–0.4 mm standoff, contact tines about one nozzle bead wide and one layer tall, a few millimeters apart.
- **Removal:** let the petal cool on the bed. Then twist the wall away from the rim, starting at the top. Trim any nub flush with a sharp blade.
- **Tuning:** if tines break during the print or the wall moves, widen them to 0.7–0.8 mm or space them closer. If they leave chunks in the lip, narrow them to 0.5 mm. With a 0.6 mm nozzle use at least 0.6 mm.
- **Material and plates:** the wall sits where the next petal in a nested stack would be, so it spreads stacks apart. The lean is the trade-off:

| Dish | Lean | Ribs | Support per petal | Plates (without the support) |
|---|---|---|---|---|
| 400 mm, 220 mm bed | 12° | 2 | 30 cm³ | 4 (2) |
| 400 mm, 220 mm bed | 12° | 0 | 24 cm³ | 3 (2) |
| 400 mm, 220 mm bed | 30° | 0 | 11 cm³ | 3 (2) |
| 600 mm, CORE One L | 12° | 2 | 62 cm³ | 4 (2) |
| 600 mm, CORE One L | 12° | 0 | 54 cm³ | 3 (2) |

**Brim: in the slicer.** A brim drawn into the model would be tied to one first-layer height, and the gap that lets a brim peel cleanly (0.1 mm) is finer than the slicer resolves in a mesh. The slicer's brim is cleaner and adjustable:

- PrusaSlicer: Print settings → Skirt and brim: Brim type *Outer brim only*, Brim width 8–10 mm, Brim separation gap 0.1 mm.
- Bambu Studio and OrcaSlicer: Brim type *Outer*, Brim width 8–10 mm, Brim-object gap 0.1 mm.

The brim also runs around the support's foot and into the space between it and the rim at the bed, and peels off with the rest.

## Annealing

- **ASA and ASA-CF:** skip it. Prusa's tests found almost no strength gain for ASA and bad warping from 110 °C. Bambu allows 80–90 °C for 6–12 hours for its ASA-CF but warns that larger parts can deform.
- **PCTG:** never. It softens from about 64–76 °C, so a 2.4 mm shell would sag.

## A test plan that wastes the least filament

1. Print the two seam strips (`FIT_TEST/seam-strip-print-two.stl`) in the real material and settings. Check that the mating faces sit flat and the hardware fits.
2. Print one of the longest petals alone, with the brim, at the settings above. After it cools, check the bed strip and the seam faces with a straightedge, and compare the two flanges' lengths.
3. Only then print full plates. For the first runs in a new material, put fewer petals on a plate: a part that lets go can knock over the ones nested next to it.

## Sources

- Polymaker, warping: https://wiki.polymaker.com/printing-tips/material-science/warping and https://wiki.polymaker.com/printing-tips/common-printing-issues/warping
- Stratasys ASA data sheet (Tg, CTE): https://pocc.techpark.uconn.edu/wp-content/uploads/sites/2880/2020/10/MDS_FDM_ASA_0920a.pdf
- Residual strain in printed ABS and anisotropic expansion of CF-PA: https://www.ncbi.nlm.nih.gov/pmc/articles/PMC11433601/
- Expansion of CF-ABS and GF-PETG along and across the bead: https://www.ncbi.nlm.nih.gov/pmc/articles/PMC9031978/
- Infill density and residual stress (simulation): https://pmc.ncbi.nlm.nih.gov/articles/PMC10347020
- Continuous length and warping (Wang 2007, "bricking"): https://www2.uned.es/egi/publicaciones/congresos/Bricking_A_new_slicing_method_to_reduce_warping.pdf
- PrusaSlicer profiles: https://github.com/prusa3d/PrusaSlicer/tree/master/resources/presets/prusa-research-fff/PrusaResearch
- Bambu Studio profiles: https://github.com/bambulab/BambuStudio/tree/master/resources/profiles/BBL/filament
- Bambu chamber temperature: https://wiki.bambulab.com/en/software/bambu-studio/chamber-temperature
- Bambu warping and plates: https://wiki.bambulab.com/en/filament-acc/filament/print-quality/warping-falling-off-collapsing
- Bambu automatic brim: https://github.com/bambulab/BambuStudio/blob/master/src/libslic3r/Brim.cpp
- Prusa ASA and satin sheet: https://help.prusa3d.com/article/asa_5078 and https://help.prusa3d.com/article/satin-steel-sheet_196526
- Prusa nozzles for abrasive filament: https://help.prusa3d.com/article/prusa-nozzle-types-for-nextruder-printers_928993
- Designed-in support fins and tines (gap, tine size and spacing): https://github.com/gittrahan/support-fins/wiki and https://hackaday.com/2026/09/23/forget-trees-add-fins-to-your-3d-prints-instead/
- Slant 3D's support fins with sprue tips: https://weblog.masukomi.org/2024/03/11/manual-support-fins-for-3d-printing/
- Clough42's separate-body support: https://hackaday.com/2026/01/22/touchless-support-leaves-no-mark/
- Prusa skirt and brim: https://help.prusa3d.com/article/skirt-and-brim_133969
- OrcaSlicer brim settings: https://www.orcaslicer.com/wiki/print_settings/others/others_settings_brim
- Prusa annealing tests: https://blog.prusa3d.com/how-to-improve-your-3d-prints-with-annealing_31088/
- Bambu ASA-CF data sheet (third-party mirror): https://www.lesimprimantes3d.fr/dl/Bambus_ASA-CF_Technical_Data_Sheet.pdf
- Siraya ASA-GF: https://siraya.tech/pages/siraya-tech-asa-gf-filament-user-manual
- PCTG data sheet (heat deflection): https://nexa3d.com/wp-content/uploads/2024/07/TDS-Essentium-PCTG.pdf
- Spectrum PCTG guide: https://shop.spectrumfilaments.com/Material-Guide-PCTG-blog-eng-1760884613.html

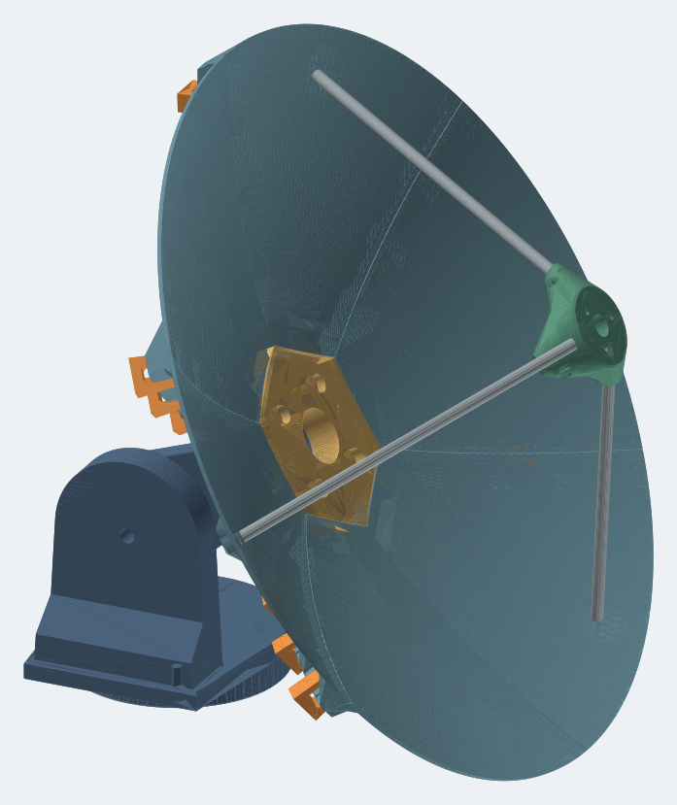
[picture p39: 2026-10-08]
docs/snapshots/assembly.png

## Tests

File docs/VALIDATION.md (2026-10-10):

# PETAL 5.0 validation record

Run on the integral-flange candidate. These checks establish numerical geometry and application behavior, not physical qualification.

- Twelve structural configurations: default; optional facets; 260, 600 and 800 mm diameters; explicit two-segment petals; f/D 0.25 and 0.8; 1.6 and 6 mm shells; a 120 mm printer-height constraint; coarse mesh with 30 mm facets.
- Closed consistently oriented meshes, positive volume, one connected solid per part, actual bed/height fit and print-plane placement.
- Sampled final-petal radial insertion against both neighbors, including cross-segment neighbors; inter-segment fit and hub/petal interference. Numerical intersection tolerance 0.02 mm³ accommodates float-precision contact slivers; this is not a dimensional tolerance or exhaustive motion proof.
- Root blind-pilot void and roof, clear central passage, matching seam strips, packed quantities and 6 mm bounding-box separation.
- Twenty-seven actual binary structural STLs reloaded independently with trimesh: watertight, consistent winding, one component, nondegenerate triangles. Export quantization is included.
- Nine feed configurations plus independent hyperbolic reflected-ray/equal-path calculations, frequency sizing, rod cuts, fixed primary focus, phase offsets and automatic rod screening.
- Sampled feed-part interference on six configurations, including 4 and 8 mm rods and a steeper support angle.
- Seven OpenSCAD mesh-snapshot renders match generated part volume within 0.002 relative error and dimensions within 0.05 mm (actual errors substantially smaller).
- Offline DOM checks pass embedded WASM initialization, generation, facets, feed-frequency changes, invalid-state export disabling, reset and generated instructions. WebGL rendering is not exercised by that test.
- A 1200 mm dish with a 1000 mm print volume generates longer flanges with six screw stations per side and a matching 36-screw seam schedule; this is a generation check, not structural qualification of a dish that size.

Default 400 mm result: 6 petals + 1 hub, 2 unique parts; approximately 580.28 cm³ solid CAD volume. Side-oriented petal bounds are approximately 173.8 × 70.0 × 173.1 mm. Shared-bed packing puts three petals on each of two 220 mm beds plus one hub bed, with 8 mm edge margin and 6 mm between part bounds. Brims, supports and machine toolhead clearance remain slicer responsibilities.

A default-petal triangle-normal inspection after the orientation fixes found remaining steep downward surfaces localized to pocket/roof details (largest individual triangle approximately 6.6 mm²); this is not a layer-by-layer support check.

No physical print, slicer toolpath, FEA, wind/creep test, RF gain measurement or outdoor-life qualification is claimed. See TEST_ARTICLE.md for the next gate.

## 5.1 hosting and illustrated exports

The geometry/interface remains revision 10. The app now identifies version 5.1 and a content-derived build ID; the standalone file is `petal-5.1-offline.html`. BUILD.json lists checksums of the complete hosted asset set. The stable old offline URL is only a redirect, so downloaded standalone files should use the versioned name.

PDF fixtures cover the default dish, a 600 mm four-rod prime-focus dish with facets, and a 24 GHz secondary configuration. Tests check actual part filenames/quantities, frequency-dependent rod cuts, text bounds, text visibility after page breaks, and a readable ASSEMBLY.pdf inside the ZIP. Rendered pages were visually reviewed. Views use the generated triangle meshes and are illustrative, not dimensioned drawings; exploded separation is not an assembly motion path. Offline DOM tests also activate the PDF button and verify the downloaded PDF header and filename.

The installer-generated configuration was exercised with the official checksum-verified Caddy binary on ports 56302 and 56303: every hosted asset matched BUILD.json, cache revalidation headers were present, and missing routes returned 404. Installer argument validation and Bash syntax checks passed. Package-manager installation and boot-time systemd execution were not run on this workspace; the script targets the documented systemd distributions and preserves an existing PETAL installation on startup/health-check failure.

## 5.2 staggered rings, mount bores and plate overrides

Interface revision 11 restores half-petal staggering by default for multi-ring dishes. Both sides share the same 2n-sided polygon at each ring boundary; each outer panel meets two inner neighbors. Cross-ring flanges overlap at their common vertex and use no projecting keys. Aligned segmentation remains selectable. Flat-side print orientation and the central Ø30 mm passage remain unchanged.

The central mount offers blind inserts or four Ø4.6 mm full-depth bores with Ø10 mm flat front washer seats. Root inserts remain blind. Hardware quantities and generated instructions reflect the selection.

## Revision 12: flat seats, fastener options, flat hub

Revision 12 makes these changes.

- **Separate root and mount fastener options.**
  - Roots default to blind heat-set inserts, so the reflecting face stays closed. The through-bolt option gives each root a Ø4.5 mm teardrop bore and a Ø9.6 mm recessed flat seat in the front.
  - The hub mount defaults to through bolts and nuts; inserts are an option.
- **Flat seam seats.** The captive hex pockets are gone.
  - Each seam bolt clamps between two Ø10 mm flat seats square to the bolt.
  - The seats are cut through the gussets only, never the shell, and never through a neighbor's bolt pad.
- **Flat hub front by default.** It sits at the petal-root height; a curved front that follows the dish is an option.
- **Ring seams** use the same flange and flat-seat system as the seams between petals.
- **Flat mating faces.** The alignment keys are gone; bolts or clips align the petals.
- **Snap-clip seams (option).** Seams can use printed clips instead of bolts, or offer both at every station.

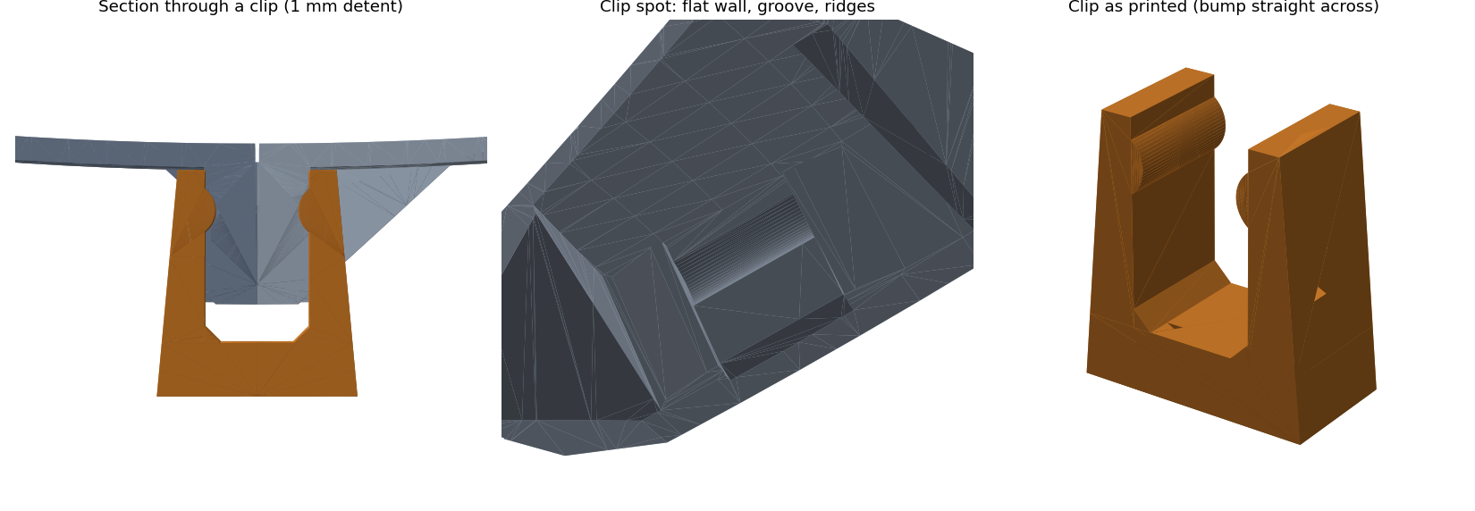
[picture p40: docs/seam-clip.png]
Section through a clip station, the station itself, and the clip as printed
  

  - With clips, each flange wall is a uniform 5 mm (no pad blocks), so each petal presents one flat face.
  - The clip is a solid trapezoid block with a channel, 10 mm wide along the seam, printed standing on its wide base. It snaps straight up over both walls; the jaws taper from 4 mm at the channel floor to 2.5 mm at the top.
  - Detent: each clip jaw carries a cylindrical bump (R 2.6 mm) straight across its full width, so the clip is a plain extruded profile. It clicks into a cylindrical groove across each wall, 0.1 mm deeper and 0.4 mm wider each side than the clip. Detent depth is a setting (0.3–2 mm, default 1 mm). The wall's bottom edge gets a lead-in chamfer.
  - Where the shell slopes across a seam (ring seams), the walls are made deeper so the full clip and, with both fasteners, the bolt seat stay on the wall.
  - Clip spots tilt to follow the shell along the seam, so the jaw tops sit 0.25 mm under the shell. Across ring seams the shell also slopes across the clip, so one side keeps a small gap there.
  - Two low vertical ridges (1 mm tall) on each wall either side of the clip stop it sliding along the seam or twisting.
  - At each clip station the 45° gusset is cut clean through over the clip and its ridges; the cut end is tilted to 45° or better in print. On radial seams, clips start past the gusset's inner ramp so the wall is full depth at every clip.
  - Where the shell slopes across a clip (toward the rim, and across ring seams), the station sits lower so the jaws clear the shell everywhere.
  - Clip stations are about 40 mm apart (the default dish gets three per seam). Short ring segments get one centered station so the clip stays clear of the corners.
  - Tapered-cantilever estimate of peak jaw strain while a jaw rides over the bump: about 1.0% at 0.3 mm, 1.6% at 0.5 mm and 3.1% at the 1 mm default. Physical testing sets the final detent depth.
  - The fit test includes clips at three squeeze settings.

The tests check, in every structural configuration:
- each seam bore is clear;
- a washer and nut envelope fits on each side;
- the seat has backing;
- in insert mode, the root pilot is clear with a closed roof; in through mode, the bore and seat are clear and the seat floor is solid;
- the hub front is flat, or follows the dish when curved;
- the mount seats are open;
- with clips, each installed clip clears its petal and every other assembled part, including feed parts, and pulling it 1 mm makes the bumps bite the grooves.

The mount check models clips as a conservative ring 26 mm deep behind the dish. With clips, the simple mount clears from −7.5° to 100° instead of −10°.

The upper (male) flange seat faces downward in print. Up to 8 petals it stays within 45°. With more petals it becomes a short overhang about 10 mm across.

Manual plate arrangements preserve copy identity, plate number, X/Y and in-plane yaw. Validation rejects missing/duplicate copies, nonfinite coordinates, out-of-volume placement and less than 6 mm between bounding boxes. Pending edits block exports. Accepted placements reach the STL plates, PLATES.csv, manifest and PDF; model/printer changes reset them. Overrides are session-local.

Validation covers 15 structural configurations, including aligned and staggered two-ring dishes, a three-ring dish and through-bolt hubs. Tests check closed/wound topology, one connected solid per part, print bounds, sampled radial insertion against actual phased neighbors, pilots and roofs, coupons and packing. Separate ring tests check paired cross-ring bore centers and axes, half-petal seam offsets, and three/four-rod registration. Plate tests exercise copy coverage, reassignment, yaw, collision/volume rejection and manifest metadata. Offline UI tests exercise the new controls, apply/reject/reset behavior and PDF download. PDF fixtures include a staggered, faceted 600 mm four-rod dish with the through-hole hub.

These are geometry/software checks. Print a three-panel staggered junction and verify alignment, tool access and side-print overhangs before committing to all rings. No measured strength improvement, slicer toolpath, wind/creep rating or RF performance is established.

Independent trimesh reload of 36 structural binary STLs confirmed watertight, consistently wound, connected positive-volume solids. Mesh cleanup now cancels coincident opposite triangle pairs, collapses sub-resolution connected edges, and refuses unresolved topology rather than exporting a broken seam.

## 5.3 system integration (2026-10-01)

- Full structural, feed, plate and ring regression suite passed, plus five integrated mount configurations: through and blind hub hardware, minimum clip elevation, 600 mm staggered rings with four rods, and a 24 GHz secondary configuration at 90° elevation.
- Mount/dish intersection checks run during generation. Shared affine transforms drive browser, SCAD and PDF assemblies. Stand clearance is calculated at the selected pose and over the permitted elevation interval; it does not replace a continuous collision test or include the stand, cables and metal hardware.
- Canonical mount STL checks passed for manifoldness, interfaces, sampled angular motion and tool access. Exported mount parts and the side-oriented clip had no >45° downward regions or flat ceilings in the triangle-normal printability scan. Slicer toolpaths remain untested.
- Clip tests cover the strain rejection threshold, broad-side print orientation, unique coupon names at tolerance limits, and installed/spare counts. The default detent is 0.3 mm; the user-entered 1.5% strain budget is not a certified material allowable.
- Offline DOM checks exercise mount controls, clip validation, manual plates and exports. Three generated PDF fixtures and ZIP contents pass text/page bounds checks; assembly and part pages were rendered for visual inspection.
- Reproducible CAD snapshots are in `docs/snapshots`: run `node scripts/render-system.mjs` then `python3 scripts/render-system.py`. These are exact generated triangles with stock rod cylinders; fasteners and stand are omitted.
- No physical prints, WebGL rendering test, RF measurement, load rating or warm-creep qualification is claimed. Follow `TEST_ARTICLE.md` before a full assembly.

## Seam levers and M4 seam bolts

- **Seam bolt size.** M3 keeps the revision 12 geometry (Ø3.4 bores, Ø10 seats). M4 cuts Ø4.5 bores with Ø11 seats and, with bolts only, 13 × 11 mm pads. Structural tests check open bores, a clear washer and nut envelope, and flat seat area for M4 with bolts only and with Both.
- **Seam levers.** These use the Both station geometry. The bundled lever, draw bar, keeper and spring meshes come straight from `cad/seam-lever.scad` (`scripts/pack-lever.py`), for M3 and M4 holes. Tests on the 400 mm default and on a 600 mm two-ring staggered M4 dish check three things:
  - every installed set clears the assembled dish;
  - the lever bears on its flange when pushed 0.5 mm toward the wall, and the spring bears on the far flange;
  - TPU springs never share a plate with rigid parts.
- **Ring junctions.** At junctions the set flips to the open side. On the 600 mm two-ring dish, 6 of 48 stations have no room on either side and are scheduled for bolts.
- **Not tested.** Clamp force, cam wear and spring creep are not modeled. Try one set on the seam strips first.

## Unification and lever motion (2026-10-03)

- The open cam tangent no longer penetrates the flange; the M3 and M4 SCAD, print STLs and embedded meshes are regenerated together.
- `tests/lever-motion.test.mjs` checks every installed open lever/bar/keeper/spring against panels and hub on 400 mm and 600 mm dishes, plus the lever at five intermediate cam angles with its pivot following the flange tangent. Cam radii come from SCAD metadata. This is sampled geometry validation, not force, fatigue, physical retention or full insertion-path qualification.
- Mount pilots are 10 mm from the tenon entry face, including the 2 mm inset. Instructions now match the check model: inserts seated 0.5 mm below that entry face. Through-bolt dish instructions distinguish the seven inserts still required by the split mount.
- Assembly/rear/staggered/exploded snapshots were regenerated for the current five-part mount.

## Feed attachment revision 3 — size and focal-ratio envelope

The rim socket pedestal is replaced by a continuous curved saddle with a flat
side-print cheek, 45-degree shoulder and front washer/nut recesses. Socket nut
housings taper into the barrels; radial webs carry the upper sockets into the
puck. Rod axes, 18 mm engagement, pocket/screw datums and rim bolt positions
retain revision 2 dimensions. The accessory manifest and instructions use
revision 3; dish joint interface remains 12.

Run `npm run test:feed-envelope` with numpy, trimesh and manifold3d available to
Python. Its 50-case grid combines dish diameters 260/400/600/800/1200 mm,
f/D 0.25/0.30/0.42/0.60/0.80, and prime-focus/Cassegrain supports. Three additional
cases exercise 4/8 mm rods, clearance extremes, four legs and phase offset.
36 cases build; 17 are explicitly rejected by the existing rod span/rise or
secondary diameter limits. Built cases span focal lengths 65–480 mm and rod
angles 2.29–62.24 degrees. Both staggered ring phases and three/four rod layouts
occur in the grid. These are sampled configurations, not a proof for every
continuous parameter combination.

Independent manifold intersections pass for rim shoe/petal, rear backer/petal,
puck/secondary, and every installed rod against its two fittings. Every exported
assembled solid is watertight, consistently wound and a single connected body.
Real M3 washers/nuts clear the rim recesses; real socket nuts clear their pockets
and sampled side-loading paths. 66 shoe/puck print meshes have at least 116.9 /
1971.2 mm² respectively of flat bed contact. The default shoe increases bed
contact from 60.0 to 204.4 mm². Its material volume rises from 3.76 to 8.10 cm³;
the default prime-focus puck rises from 34.42 to 36.16 cm³. This trades material
for broader roots and bed contact, rather than claiming a mass optimization.

The existing >45-degree overhang scanner still flags circular bores, hardware
pockets and some outer socket faces. At the default prime-focus geometry,
flagged area falls from 371.0 to 288.4 mm² for the shoe and from 809.7 to
648.0 mm² for the puck. Slicer supports/bridging and bore cleanup remain required
as appropriate; neither fitting is certified support-free. Shallow-angle cases
have more puck overhang. No printed load, screw-torque, slip, creep, wind or RF
performance qualification is implied by these checks.

The full regression suite, embedded offline UI, OpenSCAD mesh parity and
illustrated PDF/ZIP validation also pass. The one-off render scripts for this
revision were retired on 2026-10-04 and remain in git history.

## Curved seam bearing lands — bolt-only mode

The fixed-height bolt-pad blocks are replaced by full-depth bearing lands clipped
to a swept curved flange envelope. The top overlaps the petal underside; the
bottom stops inside the existing curved flange edge. A 2 mm chamfer joins one
end to the 3 mm wall, while the other retains the existing print-direction ramp.
The small 0.1 mm bottom / 0.4 mm top envelope offsets avoid coincident boolean
faces. Hole centers, flat 5 mm bearing faces, bolt/nut/washer specifications and
interface revision 12 are retained. Clip and lever flange profiles are unchanged.

The structure regression now checks that bearing lands do not protrude through
the reflector face or below the curved flange floor, and that at least 95% of
the outer washer bearing annulus remains supported. Reflector-face checks allow
for the existing tessellation chord error. The 29 structure configurations include
260/400/600/800/1200 mm dishes, f/D 0.25 and 0.8 extremes, M3/M4 bolts, multiple
rings, staggered/aligned joints, faceted rear surfaces, insertion/mating,
connectivity, hardware access and bed packing.

Before/after print scans at default, shallow and deep M4 geometry show no
significant change in overall >45-degree flagged area: approximately 314 mm²
for default/shallow, and 307 → 314 mm² for the deep M4 case. Most flags are
existing near-bed flat bridge surfaces; this is not a support-free claim.
The complete regression suite, offline UI, OpenSCAD parity and illustrated
PDF/ZIP checks pass. The before/after render scripts were retired on 2026-10-04
and remain in git history.

## Connections workspace and feed revision 4

Build `c2ebade2f49b` adds family/individual connection overrides, matched petal print variants, a joint map in CSV/PDF, accessory print inclusion, compact category controls, and viewport pan/pinch with a wider zoom range.

- The full JS suite passes, including mixed M3/M4 seam methods with staggered and aligned rings, individually selected root/mount inserts or through bolts, hardware totals, matching fit-strip pairs, and ZIP/plate exclusions.
- The feed envelope sweep covers 53 size/focal-ratio/optical-layout combinations: 36 build and 17 are explicitly rejected by stock-span or secondary geometry limits. Independent mesh checks cover connected closed solids, fitting/petal and secondary interference, rods, washer/nut seating, and captured-nut insertion paths. The 66 main fitting print meshes have flat bed contact. Residual bore/pocket overhangs still require slicer review.
- Fixed continuous feed housings replace rotated external sockets. Rod cuts use the actual housing entrances. The widened petal bearing patch replaces the rear backer and has a 45° underside perimeter chamfer. Rim fittings use M3 bolts; seam clips/levers retain their matched 5 mm flange grip faces.
- A previously failing 800 mm / f/D 0.25 Boolean mesh case now passes. Quantization repair remains bounded to 0.0001 mm; only closed numerical islands with at most 12 triangles and less than 0.00001 mm³ volume are removed.
- The embedded offline UI and export controls pass DOM tests. Navigation tests cover orbit, middle/Shift/keyboard pan, pinch, expanded zoom, fixed depth range and reset using mocked WebGL calls. A real browser/GPU viewport run was unavailable; the browser download failed.
- OpenSCAD volume/bounds comparisons pass. Default, custom, secondary and mixed-connection PDFs pass independent content and page-bound checks; representative pages were rendered for inspection.

These checks validate software geometry and export consistency. They do not replace a slicer inspection or physical fit/load test.

## Slim feed fittings — revision 5

Build `12176e22f157` replaces the bulky revision-4 housings with a thin curved
foot and tapered socket lobes blended into a 44 mm central carrier. The mounting
reinforcement footprint is narrower; its underside retains the 45° perimeter
chamfer. The default 400 mm / f/D 0.42 rim fitting drops from 31.90 to 11.47 cm³
(64%); the prime-focus carrier drops from 125.56 to 39.31 cm³ (69%). These are
solid CAD volumes, not slicer estimates. Default material-budget regression
checks prevent the fittings growing back into broad blocks.

The 53-case feed sweep builds 36 supported configurations and explicitly rejects
17 outside the existing stock-span/secondary limits. Independent intersections
and topology checks pass for reflector contact, rods, secondary, washer/nut
seating and side-loading nut paths. All 66 main fitting print meshes retain flat
bed contact. Rod bores retain 18 mm nominal engagement in 22 mm tapered sockets;
regenerate the fittings and rod cuts together.

Feed and integration tests, OpenSCAD mesh parity, the embedded offline UI, and
custom/secondary PDF content and page bounds pass. The UI check is DOM-only;
WebGL is not exercised. Residual bore/pocket overhangs need slicer inspection, and
physical fit/load qualification remains separate. The before/after render script
was retired on 2026-10-04 and remains in git history.

## Multi-view feed review — ecdc20b6aff8

The review found and corrected carrier nut-entry cuts crossing secondary stems
and an M4 screw bore stopping short inside the longer stem. Carrier nuts load
from the outer edges; the clearance bore follows the actual stem back datum.
Independent tests now guard both defects. The expanded sweep builds 40 of 57
cases, with 17 explicit limit rejections, and checks 80 fitting print meshes.
Six views per part/interface and an additional representative full orbit are
recorded in [the geometry review](FEED-GEOMETRY-REVIEW.md).

## Performance, export and editor review — 2026-10-04

Geometry and every export now run in a Web Worker started from a Blob URL, so the
hosted page and the single offline file both stay responsive; without workers the
same engine runs on the page. On a 600 mm dish switched to seam levers and the
mount, the page previously froze for 10 s in one stall and reached the final model
in 23 s; it now never misses a frame and finishes in 5.5 s (headless Chromium,
software WebGL).

Seam-lever placement tests each lever set only against the petals its bounds
reach, one at a time, in its own memory scope. A 700 mm lever dish builds in 4 s
instead of 10 s, 900 mm in 6 s instead of 25 s, and 1200 mm builds instead of
exhausting WASM memory. Mixed-connection kits build each distinct petal once
(5.4 s to 2.2 s). Every model is byte-identical to the previous engine for the
same settings, checked across 14 configurations.

The exploded view moves each part rigidly; the petal at azimuth 0 was previously
stretched about 30 % tangentially in the preview, the PDF and `exploded.png`.
Kits are deflated (about half the size), and the manual culls hidden triangles
(about half the size), draws each print plate as a numbered footprint diagram and
lists hardware as a table. The hub front is flat by default again, as revision 12
specifies.
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

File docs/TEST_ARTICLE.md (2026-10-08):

# First test article

1. Export the default PETAL 5.3 kit (smooth underside, flat hub front). Keep one parameter set and material profile for every matching piece.
2. Print TWO copies of `FIT_TEST/seam-strip-print-two.stl`, preserving orientation. These full-width cropped petal strips reproduce the lower and upper edge print conditions and include flat mating faces and a fastening station. Fit their neighboring edges at the intended dish angle; do not flatten the pair onto a table. Check the faces sit flat, then try the fastener: the M3 × 16 screw, washers and loose nut, or with clips, the distinct fit-test clips. Check insertion, layer flare, that both seats are flat (especially the upper flange's, which prints as a short overhang), tool access and seam step before/after snugging.
3. If the faces don't sit flat, correct first-layer flare or process error before going further. Do not use bolt torque or clips to pull a gap closed.
4. Print one full petal with a brim. Inspect layer previews first; use local slicer supports if needed. Measure the full radial and cross-petal profiles against the generated parabola. A short strip cannot reveal full-length warp.
5. Test the specified short M4 insert on a scrap with the same pilot, then install the root insert. Inserts are a maximum of 6 mm long in a 7 mm cavity, with the mouth recessed 0.5 mm; check heat distortion and actual engagement. With the through-bolt root option instead, check that the M4 × 20 head sits below the front surface and that the seat doesn't crush when tightened.
6. Print the hub and remaining petals only after fit/process checks pass. For staggered segments, assemble the inner ring loosely, then slide outer segments radially inward one at a time, aligning both inner neighbors in a profile jig. Do not force complete rings together. With staggering disabled, assemble radial strips first. Keep all fasteners loose. Close the final seam without force. Snug opposite seams progressively, then fit the rear hub. Record seam steps before and after each stage.
7. For a segmented dish, trial-fit a three-panel junction (two inner segments and one outer segment) before printing all rings. For the mount, test M4 hardware and washers no larger than 9 mm OD in the hub's front seats; select length from the actual stack.
8. Measure again at several elevations and after a warm hold representative of service. Check loosening, creep and seat/flange movement. Only then apply conductive finish and repeat profile/continuity checks.

No torque, wind or payload rating has been established. Begin with a restrained bench fixture and no valuable feed equipment. The foil finish can concentrate sunlight: keep it away from the Sun during handling.

For clips, print broad side down as exported. Cycle each candidate repeatedly and reject cracking, whitening, weak retention or warm creep. For the integrated mount, verify the hub/cradle stack before fitting screws: the blind-insert configuration uses M4 × 18 with a 1 mm washer through the 12 mm cradle. Set stand height from the reported full elevation-range clearance plus cable/handling margin. Restrain the dish during clamp-slip and warm-hold trials.

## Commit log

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2026-09-11 Redesign panel joints with keyed four-bolt saddles and indexed hub
    Add reinforced rear sockets and adjustable mating clearance, preserving the reflector wall. Revise the hub with locating shoulders, a flat mounting back, a slimmer front ring and a 60 mm mount bolt circle. Keep the legacy interface selectable.
    Update procedural STL and OpenSCAD geometry, support generation, offline app, assembly instructions and tests.
    [kernel.scad]
2026-09-11 Add staggered petal rings and adaptive seam connectors
    Rotate alternate rings by half a petal and connect both neighboring overlaps. Distribute additional keyed saddles along long seams using adjustable target spacing, reserving clearance for nearby sockets and fittings. Update faceted mating profiles, assembly rotations, quantities and OpenSCAD station selection.
    Expand PETAL to Parametric Expeditionary Tactical Aperture Lab. Update the offline app, documentation and geometry/connection tests.
    [kernel.scad]
2026-09-11 Polish PETAL into a fixed viewport workspace
    Remove the footer and inline assembly prose. Keep design and part lists independently scrollable, pin exports, and move print guidance into a dialog. Use responsive drawers on narrow screens, compact floating viewport controls, a near-black canvas, neutral panels and distinct model colors. Rebuild the standalone offline app.
    Validated JavaScript syntax, control IDs and whitespace; browser layout testing was not performed.
2026-09-11 Default to two-bolt side saddles and four-bolt ring saddles
    Reduce same-ring connector bodies and matching panel sockets. Preserve four-bolt ring overlaps, indexed keys and adaptive connector spacing. Update OpenSCAD, hardware counts, interface revision, guid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
    Full geometry, mating, layout and support tests pass. OpenSCAD side connector bounds match JavaScript within 0.001 mm.
    [kernel.scad]
2026-09-11 Replace raised keys with shallow seats and thin sloped plates
    Use plain panel bores and 0.35 mm footprint seats, removing raised pads and per-hole tongues. Fit planar connector backs to the local rear angle and rotate them flat for printing, retaining 3.2 mm normal thickness. Preserve two-bolt side and four-bolt ring joints.
    Make staggering independent of connection style, including matching legacy hole patterns and faceted fittings. Update exports, interface revision, hardware grip lengths, guides and offline app.
    Full mesh, mating, layout, seat-depth and support checks pass. Added independent-stagger and planar-base checks. Six representative OpenSCAD renders match JS bounds within 0.002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
    [kernel.scad]
2026-09-11 Add round bores, captured nuts and a flush mechanically captured hub
    Replace square mesh windows with round M4 bores. Add rear hex nut pockets with flat bearing seats. Capture petal-root lips in indexed hub grooves, seat the cap in a concentric pilot channel, and recess the root shoulders so the cap follows the dish parabola. Add recessed M4 button-head seats and preserve access to the 60 mm mount pattern.
    Update OpenSCAD, hardware counts and grip lengths, interface revision 5, guides and offline app. Preserve independent ring staggering and the two-bolt side/four-bolt ring arrangement.
    All mesh, mating, hardware, layout and support tests pass. Seven OpenSCAD exports match JS bounds within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
    [kernel.scad]
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2026-09-26 Reinforce seam connections and add printable joint fit coupons
    [kernel.scad]
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2026-09-28 PETAL 4.0: reinforce structure, improve datum joints and document test assembly
    [kernel-revision-7.scad]
2026-09-28 PETAL 4.1: add metal-rod feed supports, Cassegrain geometry and open-center aiming adapter
    [DEFAULT-CASSEGRAIN-HARDWARE.csv, DEFAULT-CASSEGRAIN-RODS.csv, DEFAULT-PRIME-HARDWARE.csv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]
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2026-10-01 Add all-printed indexed alt-az mount (1° vernier pin lock)
    Three ASA-GF parts (column, azimuth head, elevation cradle) that bolt to the
    hub's 4 x M4 mount inserts on the 60 mm BCD and keep the Ø30 port open.
    Each axis locks with one Ø5 steel pin through vernier hole rings
    (10° coarse / 9° fine), giving a positive stop at every 1° (step 2/3 optional).
    Elevation -5..100°, azimuth 360°.
    scripts/check-indexed-mount.py reloads the STLs and checks bed fit, one
    locking pair per step, hole positions, pin fit, hub interface and a
    cradle + dish-envelope collision sweep.
    Claude-Session: https://claude.ai/code/session_01WKA4qkWi8fLbdtiGhs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
    [indexed-column.stl, indexed-cradle.stl, indexed-head.stl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]
2026-10-01 Indexed mount rev 2: print-optimized, no supports or bridges
    - Horizontal axle and pin holes are teardrops roofed at 45° toward print-up;
    the pin still seats in 270° of true circle, indexing unchanged.
    - Column prints flange-down: azimuth datum and holes come off the bed, the
    bolt-head step faces up, base is a hollow 40° trumpet with 45° countersunk
    bench holes. Flange shrinks to head size (dish clearance 19 mm at -5°).
    - Azimuth coarse scale moves to the flange rim (vertical face).
    - 0.6 mm elephant-foot chamfers on all bed-side edges and hole entries.
    - Matched facet counts remove sliver ledges between holes and chamfers.
    - scripts/check-printability.py: overhang/bridge scan of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
    [indexed-column.stl, indexed-cradle.stl, indexed-head.stl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]
2026-10-01 Replace pin-indexed mount with all-printed geared alt-az head (rev 3)
    - One printed worm per axis on a printed gear: 6° per knob turn, 0.5° ticks,
    self-locking (lead 7.1°), no pins, detents or springs. Both worms are the
    same part.
    - 48° pressure-angle teeth so the worm prints upright and the ear's gear
    sector prints sideways with every flank under 45°; elevation worm axis at
    50° from vertical so its housing prints without bridges.
    - Head is a module: base plate with 4 x M5 inserts on a 50 mm square takes a
    printed stand, a 1-1/4" NPS pipe-mast clamp, or a 3/8-16 tripod puck.
    - Hard stops at about -8° and 104°, worm still fully meshed at both.
    - scripts/check-geared-mount.p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
    [geared-base.stl, geared-cradle.stl, geared-head.stl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]
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2026-10-01 Add three-part simple alt-az mount with M6 pinch clamps
    Base (split vertical socket), rotator (spigot + split horizontal sleeve)
    and cradle (hub plate + shaft). Each axis is held by one M6 bolt across a
    slit; the bolt runs tangent to the bore in a V-groove, so a loosened joint
    stays captive. Azimuth scale on the rotator collar; elevation by phone
    inclinometer on the cradle's flat top web. Only standard hardware:
    2 x M6, 4 x M4, plus a 3/8-16 nut or 4 x M5 for mounting.
    check-simple-mount.py: fits, bolt capture, el -10..100 and az sweeps with
    the dish envelope, hub interface. All three parts pass check-printability.
    Claude-Session: htt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
    [simple-base.stl, simple-cradle.stl, simple-mount.scad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]
2026-10-01 Simple mount: replace pinch clamps with disc-on-disc clamps
    Both axes are now two flat faces clamped by one M8 bolt (head captured in a
    hex pocket) and a wing nut. Base and rotator are flat discs (azimuth); the
    cradle arm clamps flat against an upright on the rotator (elevation).
    Clamp faces print on the bed where possible. Validator checks face contact
    area, bolt clearance, el -10..100 and az sweeps with the dish envelope.
    Claude-Session: https://claude.ai/code/session_01WKA4qkWi8fLbdtiGhsKFaF
    [simple-base.stl, simple-cradle.stl, simple-mount.scad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]
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2026-10-01 Simple mount: redesign as a symmetric clamped fork; drop earlier designs
    Start-over design following commercial dish brackets and printed pan-tilt
    heads: base disc, yoke (disc + two cheeks) and cradle (hub plate + two
    cheeks outside the yoke cheeks). Azimuth is disc-on-disc with one M8;
    elevation is two flat clamp faces, one M8 bolt and wing nut per side.
    Cheeks are straight where they clamp and flare on every side into their
    disc or plate; all faces print without supports.
    Removes the geared and pin-and-screw mounts (and their scripts, STLs and
    docs) from this branch so the simple mount is the only one; they remain
    in history.
    Claude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
    [geared-base.stl, geared-cradle.stl, geared-head.stl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]
2026-10-01 Simple mount: single elevation clamp on one side (asymmetric)
    Replaces the fork with one solid upright on the yoke and one cheek on the
    cradle, so each axis has a single adjustment point: one wing nut for
    elevation, one center bolt for azimuth. Clamp faces grow to r 35 to make
    up for the lost second face. The upright and cheek are straight where
    they clamp and flare on every side into their plates. The azimuth scale
    moves to the base rim; the yoke carries the pointer groove.
    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
    [simple-base.stl, simple-cradle.stl, simple-mount.scad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]
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2026-10-01 Revision 12: through bolts by default, flat seam seats, flat hub front
    - Root and hub mount fasteners default to M4 through bolts with washers and
    nuts; heat-set inserts stay selectable. Roots get a teardrop through bore
    and a recessed flat seat in the front so the head sits below the face.
    - Seam bolts clamp between flat Ø10 seats square to the bolt on both
    flanges; the captive hex pocket is gone (loose M3 nut, M3 × 16).
    Seats cut gussets only, never the shell or a neighbor's bolt pad.
    - Hub front is flat at the petal-root height instead of a shallow dome.
    - Drop the unused nut-clearance option; update hardware schedule, guides,
    UI, tests and docs.
    - Remove the manual aiming ada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
    [bench-plate-metal-reference.stl, cradle.stl, hub-ring.stl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]
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2026-10-01 Snap-clip seam option: solid U clips, recess slots, fit-test clips
    - Seam fastening: M3 bolts (default), printed snap clips, or both (every
    station takes either). Clip squeeze is adjustable.
    - Clip: solid blocky U printed flat (4 mm arms, 10 mm wide, 5 mm base);
    shallow 45° nubs click into V-grooves across the flat seats. Strain
    about 0.8% at the default squeeze, sized for ASA-GF.
    - Each clip station gets a slot down the pad face; the slot's down-facing
    wall and the pad ends tilt to 45° or better in print.
    - Clip stations are about twice as dense, clear of keys and ring corners.
    - Fit test includes clips at three squeeze settings.
    - Tests: installed clips clear their petal and the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
2026-10-01 Snap clip: solid trapezoid block that snaps up from below
    - Replace the U clip with a solid trapezoid block with a channel, printed
    standing on its wide base (every face 45° or steeper).
    - Tapered jaws (4 to 2.5 mm) spread over the flange pads; a 0.3 mm 45° lip
    on each jaw hooks the pad's chamfered top edge. Pad bottom edges are
    chamfered as a lead-in. Peak strain about 0.9% at the default squeeze.
    - Clip stations sit lower where the shell slopes across them so jaws and
    lips clear the shell; station heights are exported in the flange spec.
    - Squeeze range 0-0.1 mm; fit-test clips step by 0.05.
    - Mount check: with clips the simple mount clears -7.5° to 100°.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
2026-10-01 Clip teeth with a depth setting; gusset cut at clip spots; flat mating faces
    - Clip: same solid block, now with a real tooth on each jaw (flat ledge
    catch, 45° lead-in) that drops into a matching notch across the pad face.
    New "Clip tooth depth" setting (0.3-2 mm, default 1 mm) sizes both the
    tooth and the notch (+0.1 mm).
    - At clip spots the 45° gusset is cut clean through over the clip width.
    - Alignment keys removed: mating faces are flat in every mode; bolts or
    clips align the petals. Key-clearance setting removed.
    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
2026-10-02 Seam levers as a fastening option, M3/M4 seam bolts
    - Seam fastening gains 'Seam levers' (Both-style stations): the four lever
    parts from cad/seam-lever.scad are bundled for M3 and M4 holes, placed at
    every station in the assembly, flipped to the open side at ring junctions,
    and replaced by a bolt where neither side has room.
    - New seam bolt size option: M3 (Ø3.4 bores, Ø10 seats) or M4 (Ø4.5 bores,
    Ø11 seats, larger pads); hardware schedule, guide and UI follow it.
    - TPU springs pack on their own plates; manual plates reject mixing.
    - scripts/pack-lever.py regenerates the lever STLs and dist/lever-meshes.js.
    - Tests: lever clearance/contact, M4 bores and seats, kit and manifest.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
    [bar.stl, plate.stl, seam-lever.scad]
2026-10-02 Simple mount: split yoke and cradle, add arc lock and base-less options
    The yoke becomes a turntable plate plus a separate upright, and the
    cradle a hub plate plus a separate cheek, joined with M4 heat-set
    inserts (Ø5.6 x 8 pilots) and countersunk M4 flat-heads with flush
    heads. The upright and cheek now print lying on their clamp faces, so
    the elevation bolt holes are vertical and no supports are needed; the
    large inner flare is replaced by an outer foot flange and a small
    locating shoulder on the plate.
    Options: arc_lock adds an M6 bolt in a 110° arc slot (r 28) through the
    upright with a captive head in the cheek; stand_holes drops the base
    and puts four countersunk M5 holes in the yok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
    [simple-base.stl, simple-cheek-arc.stl, simple-cheek.stl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]
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2026-10-02 pack-mount: write canonical STLs so re-exports are byte-identical
    OpenSCAD's binary STL triangle order changes between runs, which
    changed source_sha256 on every re-export of an unchanged model. The
    exporter now rewrites each STL with a fixed header and a sorted
    triangle order (winding kept). Geometry is unchanged.
    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
    [simple-base.stl, simple-cheek-arc.stl, simple-cheek.stl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]
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2026-10-02 Mount: inset tenon joints for the split arms, ribs on the cheek
    - The upright ends in a 2 mm tenon (its whole footprint) that drops into a
    pocket in the yoke plate; the cheek ends in a 2 mm tenon, flush with its
    clamp face and 2 mm inside its other edges, that drops into a pocket in
    the cradle plate. 0.2 mm clearance per side, 0.5 mm lead-in. Insert
    pilots are 2 mm deeper so the M4 x 16 / x 18 screws keep full engagement.
    - Two triangular ribs (9 x 22 x 4 mm) on the cheek's inner face at the
    plate end, clear of the hub bolt heads, bearing on the plate.
    - check-simple-mount: tenon clearance and sideways lock, rib bearing,
    inserts measured from the tenon faces. All 50 checks pass;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
    [simple-cheek-arc.stl, simple-cheek.stl, simple-cradle.stl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]
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2026-10-04 Optimize PETAL: worker engine, faster levers, compact mount cheek, cleaner editor
    Performance
    - Geometry and every export run in a Web Worker (Blob URL, works from file://);
    the same engine runs on the page when workers are unavailable. The page no
    longer freezes while building or exporting.
    - Seam-lever placement tests each set against nearby petals only, in its own
    memory scope: 900 mm builds in 6 s instead of 25 s, 1200 mm no longer
    crashes WASM. Mixed-connection petals build once per distinct variant.
    Dish outputs are identical to the previous engine across 14 configurations.
    - Viewer caches GPU buffers; selection and separation only redraw.
    Fixes
    - Exploded view moves parts r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
    [simple-cheek-arc.stl, simple-cheek.stl, simple-cradle.stl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]
2026-10-05 Add Gregorian collector feed and tripod leg-socket base
    Collector (Optical layout: Gregorian collector)
    - Concave ellipsoidal bowl with foci at the dish focus and the insert; re-solved
    from D and f/D on every build (rim at the dish rim angle + 3°, insert
    half-angle sets the focus spacing, smallest bowl that hides the insert in
    its own shadow, or N wavelengths when a frequency is set)
    - Rods socket into fins built into the bowl, with match-drilled through bolts
    - Insert cup on a tube mast from the hub front, or a printed pedestal on deep
    dishes; cable runs inside the mast
    - Cross-section shows the bowl, F2 and traced rays; guide, PDF, hardware,
    RODS.csv and manifest cover the new p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
    [DEFAULT-GREGORIAN-HARDWARE.csv, DEFAULT-GREGORIAN-RODS.csv, simple-base-legs.stl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]
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2026-10-07 Add plain-hole seat options, an optional hub clearance, and per-build asset URLs
    - Through-bolt seats on the dish front (petal roots, hub mount) can be recessed
    (default) or plain holes; a plain seat keeps only a flat spot face where the
    surface slopes.
    - Mount: the cheek's head pockets, the base's azimuth nut pocket and the
    no-base stand countersinks can be plain holes. SCAD switches head_pockets,
    nut_pocket and stand_countersink match the app's cuts; bolt lengths and
    washers follow.
    - Hub clearance (0-0.6 mm): moves the hub's edges in and enlarges its root
    holes so the petals line up on their seams before the root bolts clamp them.
    Mount holes do not move. The hub chamfer now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
    [simple-cheek-arc.stl, simple-mount.scad]
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2026-10-09 Largest dish on N plates, rods on 1200 mm dishes, clamp sides, warping guide
    - Rods: the datum moves in from the rim to the outermost ring where the
    rods stay under 580 mm and 62 degrees, so 1200 mm dishes build with
    prime-focus, Cassegrain and collector feeds. Auto stock reaches 12.7 mm.
    - Print tab: "Largest dish" finds the biggest diameter, petal count and
    rings that fit a plate budget, with live progress from the worker.
    - Print tab: gap between parts is a setting (3-30 mm) for brims.
    - Mount: elevation clamp on the right, left (self-tightening under the
    dish's weight) or both sides as a U, with mirrored and dual STLs and
    OpenSCAD parity. Holding estimates and a screw-drive con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
    [simple-cheek-left.stl, simple-cradle-dual.stl, simple-mount.scad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]
2026-10-09 Configuration codes and IDs, automatic rod count
    - Header shows the design's configuration ID; matching IDs mean matching
    designs (settings, joint choices, hand-placed plates).
    - Configuration dialog: copy the code or a link, load a code, link, file
    or kit parameters.json, save named designs in the browser, save/open
    files. The address bar always carries the current code.
    - dist/config.js: P1 codes (deflated JSON with a frozen baseline and
    dictionary, URL-safe base64) and 8-character IDs. PDF, parameters.json
    and the SCAD snapshot record the ID and code.
    - Rod count is automatic by default: 4 rods with 8, 12 or 16 petals,
    3 with 6; 3 or 4 can still be fixed. 1200 mm prime-focus a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
2026-10-10 Rim band and underside ribs for stiffer petals in print and in use
    - Rim band (Shape tab, L by default): a 3 mm wall behind the rim of each
    outer petal, 6-30 mm deep, so every side-print layer ends in a hook
    instead of a free edge that flexes when the nozzle turns around. U adds
    a round bend toward the hub with a 2 mm lip; triangle adds a 45° brace
    back to the shell. The bands form one ring when assembled. With 6
    petals the band leans inward so no face prints steeper than 45°.
    - Underside ribs (off by default): a mirrored diamond grid of low ribs
    with 45° sides, clear of seam hardware and the rod socket.
    - Seam stations near the rim move just enough to clear the band.
    - dist/s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
2026-10-10 Rim band square to the dish, with a 45° frame foot as the default
    - The band no longer leans inward on 6-petal dishes; it stays parallel
    to the dish axis with any petal count.
    - New default "Frame": the wall, a round 45° bend toward the hub and a
    5 mm lip, making an angled frame around the dish. It replaces the
    triangle. L and U remain; depth is the straight wall.
    - Stiffener tests check steep faces away from the band and that band
    faces are no steeper than the square wall must be (60° at 6 petals).
    Claude-Session: https://claude.ai/code/session_01PkHeuQjkXJw1mi73tvpb7k
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2026-10-10 Breakaway rim support for the outer petals' side print
    A print-only wall stands in front of each outer petal's rim, 0.3 mm from the
    rim's front edge, joined to it by tapered tines (0.3 mm tall, 0.6 mm wide at
    the rim, at most 4 mm apart) that snap off at the rim. Its outline is a bow
    along the rim and a straight string to the top, with a window between; every
    face prints without support. The dish mesh is unchanged: the support is only
    in the printed file (STL, packed plates, SCAD print module, PDF drawings),
    and the viewer shows it in the support color on print beds.
    Settings in Print: on/off (default on), wall 2-8 mm, gap, tine spacing and
    width. Config codes keep P1: the baseline has the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
2026-11-12 Pair seam station halves by distance, not a rounded key
    The two halves of a station, computed from different petal variants, could
    round to different 0.1 mm keys, so single-joint overrides on some dishes
    (e.g. 600 mm with seam levers) failed with 'Connection choices do not match
    across a seam'. Match within 0.2 mm through a 1 mm grid instead; add a
    regression test.
    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
2026-11-12 Petal Z scale and a sector gauge to close the rim wedge gap
    Petals print on their side, so different Z and XY shrink changes each petal's
    included angle; the error adds up around the ring and opens a wedge gap toward
    the rim that only screws could pull shut. New Print setting 'Petal Z scale'
    scales side-printed parts along print Z; every kit's FIT_TEST folder gets
    sector-scale-gauge.stl (the outer 14 mm of an outer petal, as printed) and
    SECTOR-GAUGE.md with the two-measurement formula. Test and docs included.
    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
2026-11-12 Fix four confirmed generator bugs from the code review
    - jointKey: snap to 1e-6 before rounding to 0.1 mm. On 6-petal dishes with
    odd diameters the two petals of a seam rounded to different IDs, listing
    phantom one-sided seams and breaking kit export whenever an override was set.
    IDs off the boundary are unchanged, so saved codes still load.
    - Faceted rear + staggered rings + clips or levers failed to build: both halves
    of a ring seam now take the lower of the two petals' rear surfaces, so their
    station levels and tilts match.
    - manifest() crashed when overrides removed every clip; clip/lever entries now
    follow the parts in the kit, and seam_fastening reports 'mixed' with counts.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
2026-11-12 UI/UX pass: joint override fixes, stage feedback, tablet/phone layouts, plates view
    Functional fixes from the hands-on review:
    - B2: a petal-seam family choice on a one-ring dish (or one equal to the default)
    sets #seamJoint/#seamBolt instead of an override that hid the default cards; an
    amber notice under the seam cards lists individually set seams, with Edit/Clear.
    - B3: Show in model closes the phone design sheet.
    - B4: seam and joint cards are re-checked in place, so keyboard focus stays.
    - B5: "Use the default" is hidden for whole hub families (their choice is the
    default) and disabled when the scope has no override.
    - B6: out-of-range numbers wait while typing; the field's change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
2026-11-13 Wedge-key seams: tool-less T-key + 1:12 wedge with a V-register (seamJoint 4)
    Printed snap clips cannot store the energy needed to pull warped petals into
    line; this adds a positive, self-locking draw joint as seam method 4
    ("Wedge keys · tool-less"), usable as the default or as a family/joint
    override.
    Petal geometry (dist/wedge-key.js, flange() in dist/geometry.js):
    - clip/lever stations and 5 mm walls; 6.4 x 6.7 mm slot through both walls
    at Y = +0.5, with a 90 deg gable toward print-up where a ceiling would
    overhang; 3 mm lugs (45 deg ends, chamfered on a down-facing upper flange)
    keep 5-6 mm of wall under the slot; gusset windows kept; clip detent
    groove, lead-in chamfer and g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
